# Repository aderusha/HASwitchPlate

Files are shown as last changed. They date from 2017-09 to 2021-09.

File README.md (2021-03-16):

# We're Moving!

This repository is an archived snapshot of the pre-1.0 HASP project.

## [Click here to head to the new home for HASPone!](https://github.com/HASwitchPlate/HASPone)

Below you'll find saved information about previous versions of HASP.

---

# HA SwitchPlate

The HA SwitchPlate is a user-programmable LCD touchscreen you can mount into a [standard North American work box](https://www.nema.org/Standards/ComplimentaryDocuments/NEMA%20WD%206%20-%20Dimensions%20for%20Wiring%20Devices%20-%20Excerpt.pdf) in place of a light switch.  It connects to your home automation system over WiFi to send and receive [MQTT](https://en.wikipedia.org/wiki/MQTT) messages in response to user interactions on the screen or events happening in your home.  The result is an attractive and highly-customizable controller for your home automation system which you can build yourself!

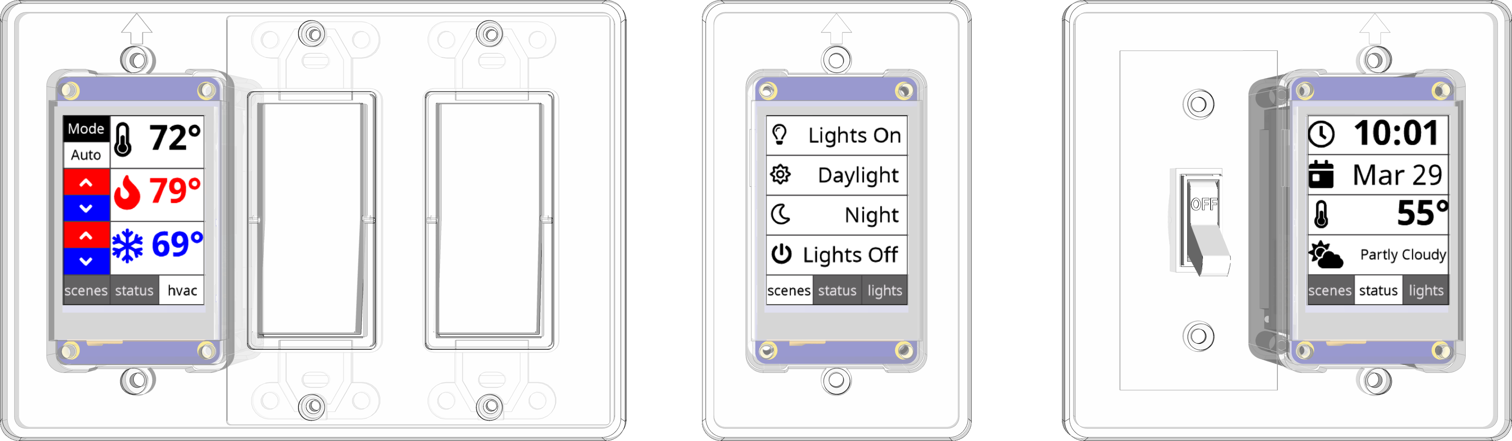
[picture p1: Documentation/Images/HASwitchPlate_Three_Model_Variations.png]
HA SwitchPlate Models


The HA SwitchPlate ("HASP") utilizes a [Nextion 2.4" LCD Touchscreen display](https://amzn.to/2TRTEU2) mounted in a 3D-printed enclosure as a touchscreen panel for home control and information display.  An [ESP8266-based microcontroller](https://amzn.to/2UZlga4) provides WiFi connectivity and system control.  The project has been developed to integrate with [Home Assistant](https://home-assistant.io/) and [OpenHAB](https://www.openhab.org/) but [should be compatible](Documentation/06_MQTT_Control.md) with any other MQTT-enabled automation platform such as [Domoticz](https://www.domoticz.com/wiki/MQTT), [Node-Red](http://noderedguide.com/tag/mqtt/), [Wink](https://github.com/danielolson13/wink-mqtt), [SmartThings](https://github.com/stjohnjohnson/smartthings-mqtt-bridge), [Vera](https://github.com/jonferreira/vera-mqtt), [HomeKit](https://www.npmjs.com/package/homekit2mqtt), etc.

The [Arduino code](Arduino_Sketch) for the ESP8266 provides a generic gateway between [MQTT](https://en.wikipedia.org/wiki/MQTT) and the [Nextion instruction set](https://www.itead.cc/wiki/Nextion_Instruction_Set).  A basic [Nextion HMI display file](Nextion_HMI) has been included with several pages of various layouts to provide user controls or to present information in response to MQTT messages sent to the device.

## Demo screens

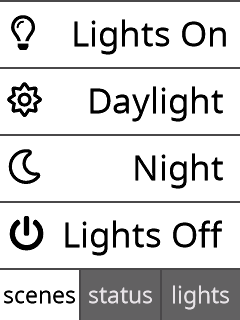
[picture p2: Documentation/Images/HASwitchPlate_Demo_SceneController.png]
Scene controller
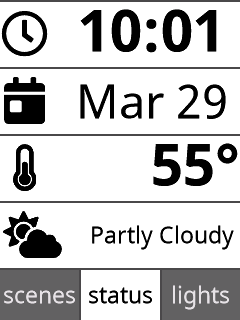
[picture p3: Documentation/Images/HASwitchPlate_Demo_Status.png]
Status display
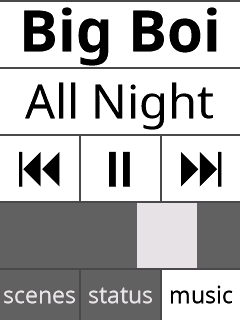
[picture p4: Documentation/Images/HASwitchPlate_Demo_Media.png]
Media control
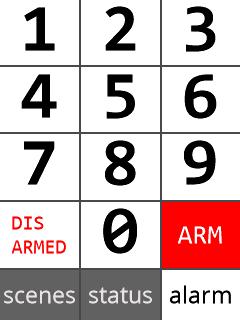
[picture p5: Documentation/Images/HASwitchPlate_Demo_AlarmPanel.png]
Alarm Panel
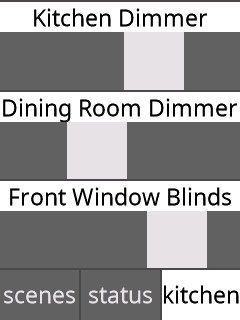
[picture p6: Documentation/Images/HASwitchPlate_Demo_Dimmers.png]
Slider/Dimmer Controls
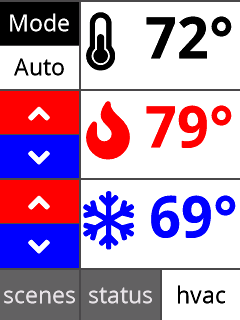
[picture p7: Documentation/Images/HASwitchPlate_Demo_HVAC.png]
HVAC Controls
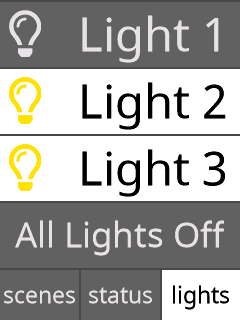
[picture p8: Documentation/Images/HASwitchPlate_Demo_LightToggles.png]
Light toggles
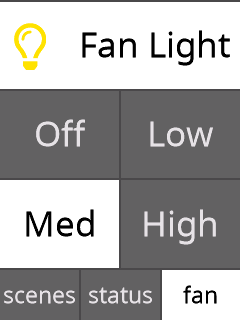
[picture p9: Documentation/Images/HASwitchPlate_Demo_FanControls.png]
Fan controller
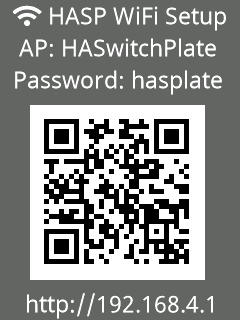
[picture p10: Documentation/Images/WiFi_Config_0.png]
WiFi Setup
        

## Purchase an assembled unit

As this build requires some specialist skills and tools, I will occasionally be [offering assembled devices for sale here](https://www.tindie.com/products/luma/ha-switchplate-hasp-single-wide-assembled/).

## Buy me a coffee

Buy me a coffee (https://www.buymeacoffee.com/gW5rPpsKR)

This project is powered by coffee.  [I might get a little weird about it at times](https://github.com/aderusha/RoastLearner), but it's not much of a stretch to suggest that coffee both powers and consumes a fair portion of my mental energy.  [Hook me up if you think HASP is cool](https://www.buymeacoffee.com/gW5rPpsKR).  Thanks!

## Bill of Materials

To build a simple version of this project you will minimally need the [Nextion display](https://amzn.to/2DIpahB) and the [WeMos D1 Mini](https://amzn.to/2Gc92Xs), 4 jumper wires, and a USB cable to power both devices.

A complete build that's ready to install will require the following components:

* [Nextion 2.4" LCD Touchscreen display](https://amzn.to/2RksiXr)
* [WeMos D1 Mini ESP8266 WiFi microcontroller](https://amzn.to/2UZlga4)
* [3D printed switch plate](3D_Printable_Models/HASwitchPlate_front_single.stl)
* [3D printed rear cover](3D_Printable_Models/HASwitchPlate_rear_nolcdmod.stl)
* [Mean Well IRM-03-5 AC to 5VDC Power supply](https://amzn.to/2UUWGa8)
* [PCB](PCB/)
* [2N3904 NPN Transistor](https://amzn.to/2TRuwwD)
* [1k Ohm Resistor](https://amzn.to/2Ec3kTZ)
* [4pin 2.54mm JST-XH PCB header](https://amzn.to/2Eaywmt)
* [Rubber grommet](https://amzn.to/2N6Etny)
* [6" each of white and black 300V 18AWG stranded power cables](https://amzn.to/2EcMmoA)
* [Two M2 self-tapping 6MM screws](https://amzn.to/2V0djBg) (or just any 4-6mm M2 screws) to mount PCB in rear enclosure
* [Four 20mm M2 flathead screws](https://amzn.to/2TQvd9N) and [four 3mm M2 threaded inserts](https://amzn.to/2N511Fh) to fasten both halves of the enclosure together

## Get Started!

[Check out the documentation](Documentation/) to get started building your own HA SwitchPlate.

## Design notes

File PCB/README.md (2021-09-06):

# We're Moving!

This repository is an archived snapshot of the pre-1.0 HASP project.

## [Click here to head to the new home for HASPone!](https://github.com/HASwitchPlate/HASPone)

Below you'll find saved information about previous versions of HASP.

---

# PCB source files and Gerber outputs

Above you'll find [KiCad](http://kicad-pcb.org/) [schematic](https://github.com/aderusha/HASwitchPlate/blob/master/PCB/HASwitchPlate.sch) and [PCB](https://github.com/aderusha/HASwitchPlate/blob/master/PCB/HASwitchPlate.kicad_pcb) files along with [a ZIP bundle containing complete gerber outputs](https://github.com/aderusha/HASwitchPlate/raw/master/PCB/HASwitchPlate.gerbers.zip) ready to send to [your favorite PCB shop](https://www.allpcb.com/?Mb_InviteId=34099).

I had these manufactured by [AllPCB](https://www.allpcb.com/?Mb_InviteId=34099) and I'm very happy with the results.  The quality has been perfect and their shipping time to the US has been under a week across several orders.  [If you sign up through this link](https://www.allpcb.com/?Mb_InviteId=34099)  they credit me some cash that I can use for future projects which helps me out a bit.

If you aren't looking to buy a zillion boards, I may have some ready for US orders in [my Tindie store](https://www.tindie.com/products/luma/ha-switchplate-hasp-pcb/).

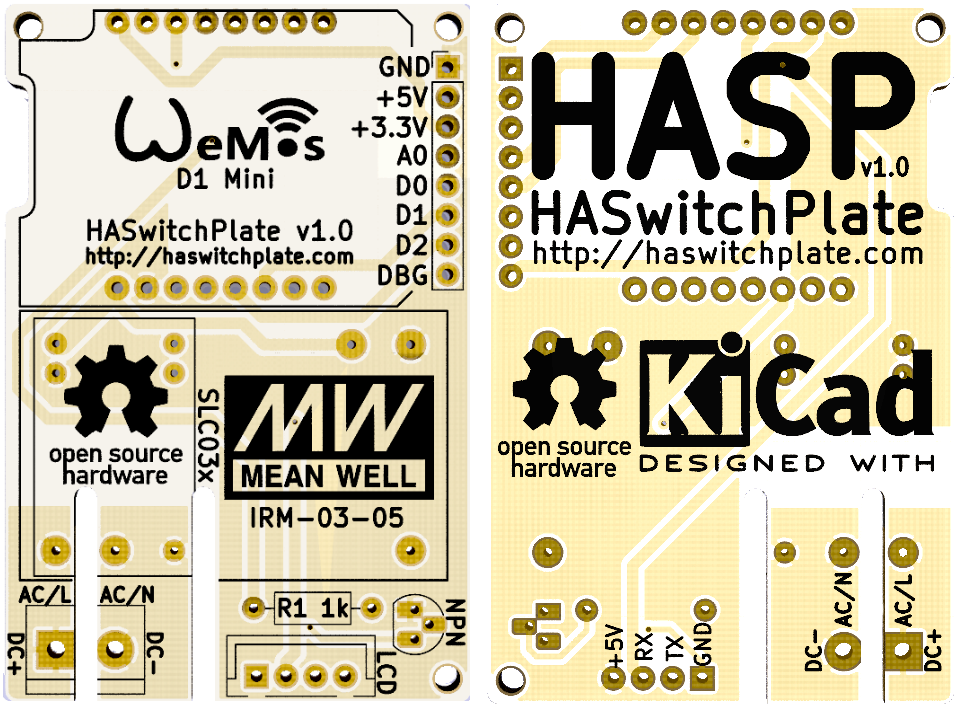
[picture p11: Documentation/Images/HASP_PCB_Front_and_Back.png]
HA SwitchPlate PCB


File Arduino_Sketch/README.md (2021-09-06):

# We're Moving!

This repository is an archived snapshot of the pre-1.0 HASP project.

## [Click here to head to the new home for HASPone!](https://github.com/HASwitchPlate/HASPone)

Below you'll find saved information about previous versions of HASP.

---

# HASwitchPlate Arduino Sketch

Here you'll find the [Arduino source code](./HASwitchPlate/HASwitchPlate.ino) for the microcontroller firmware along with [a pre-compiled binary image](https://github.com/aderusha/HASwitchPlate/raw/master/Arduino_Sketch/HASwitchPlate.ino.d1_mini.bin) which can be [flashed directly to your ESP8266](../Documentation/01_Arduino_Sketch.md#nodemcu-flasher).  

Please [check the Arduino Sketch documentation](../Documentation/01_Arduino_Sketch.md) for additional deployment details.

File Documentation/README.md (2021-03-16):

# We're Moving!

This repository is an archived snapshot of the pre-1.0 HASP project.

## [Click here to head to the new home for HASPone!](https://github.com/HASwitchPlate/HASPone)

Below you'll find saved information about previous versions of HASP.

---

# HA SwitchPlate Documentation

## First, a note of caution

The HA SwitchPlate project requires some basic knowledge of soldering, electronics, Arduino programming, MQTT, and how to safely handle high-voltage AC.  This point bears some repeating so let's try a bigger font to make sure everyone gets it:

# THIS PROJECT INVOLVES MONKEYING WITH HIGH VOLTAGE AND YOU COULD KILL YOURSELF AND/OR SET YOUR HOUSE ON FIRE

The end result is a thing that connects to live voltage and will be placed into your wall for years to come. It will not carry any sort of UL/CE/etc certification.  Proceed with extreme caution.

## With that out of the way, let's get started!

If you want to jump right in, follow the steps below in order to build and setup your device.  Keep reading after that for some background on how this all actually works.

## Step-by-step Instructions

### Step 1 - [Arduino Sketch](01_Arduino_Sketch.md)

Get started with deploying your code to the ESP8266 and getting it connected to WiFi and your MQTT broker.

### Step 2 - [Nextion HMI](02_Nextion_HMI.md)

Next you'll want to flash the Nextion touchscreen with the provided firmware.

### Step 3 - [Electronics Assembly](03_Electronics_Assembly.md)

Now we can hook the ESP8266 to the Nextion HMI and provide power to both.

### Step 4 - [Project Enclosure](04_Project_Enclosure.md)

Time to move from the breadboard into a nice new home suitable for mounting in your wall.

### Step 5 - [Home Assistant](05_Home_Assistant.md)

Utilize the provided Home Assistant automations to control and interact with the panel.

### Step 6 - [MQTT Control](06_MQTT_Control.md)

Time to remove the training wheels and learn to send commands to and from the panel via MQTT.

----

## Frequently Asked Questions

* **Can I install HASP outside of North America?** While the various power supply options for the HASP electronics should offer a solution which can handle line voltage in most countries, the physical installation of the device probably won't work outside of North America.  There is no international standard for the size and shape of workboxes, so things like screw hole locations and overall mounting dimensions used for the HASP are unlikely to work in any workbox outside of North America.
* **Can I use HASP with \<Some Home Automation System\>**?  If your home automation system can send Nextion commands as MQTT payloads, then yes.  Getting it all to work is going to take a lot of work, but it's possible.
* **Can I run HASP without a neutral wire?** Like most smart devices, a HASP installation will require a neutral wire available in the box you're mounting into.

----

## HASwitchPlate Architecture

The complete HA SwitchPlate ("HASP") build consists of 4 physical components:

* Nextion LCD Touchscreen
* ESP8266 WiFi microcontroller
* Power supply and circuit board
* 3D-printed enclosure

In addition, there are three different programming environments involved:

* Nextion Instruction set
* Arduino for ESP8266
* Home Assistant automations (or automation platform of your choice)

## The basics

A home automation system such as Home Assistant can interact with the HASP by sending and receiving MQTT messages to control what appears on the HASP and to respond to user interactions at the HASP.  At its core this project is an Nextion-over-MQTT gateway.  [Nextion Instruction Set](https://nextion.tech/instruction-set/) commands are sent to the HASP via an MQTT message and delivered to the Nextion LCD.  User interactions triggered from the LCD (such as button presses) are sent back out from HASP via MQTT messages to be acted upon by your home automation system.

### Example: one screen button

To illustrate, let's discuss the case of a single button shown on the screen.  Below we see  "page 1", showing a set of 4 buttons arranged vertically and a set of 3 page select buttons at the bottom.

Scene Controls

Referring to the [Nextion Object Reference](02_Nextion_HMI.md#hasp-nextion-object-reference) (more on this later), we find that the top-most button above is an object named `p[1].b[4]`.  When the HASP device shown here powered on, the home automation controller sent an MQTT message that looked like this:

| topic | message |
|---|---|
| `hasp/plate01/command/p[1].b[4].txt` | `"  Lights On "` |

Let's take a look at this `command` message:

`hasp` All messages to and from the HASP appear under the `hasp/` namespace in MQTT

`plate01` This device is named `plate01`.  You can have several HASP devices in your home and each gets their own name.

`command` This message is a `command` being sent *to* the HASP device.

`p[1].b[4]` is the name of a Nextion "object".  A full discussion of these names and a map to the objects included in the HASP project can be found [here](02_Nextion_HMI.md#hasp-nextion-object-reference).

`.txt` is a property of the object named above.  In this case, `.txt` is a reference to the text which appears on this object.

`"     Lights On "` Is the text we wish to appear on the screen.  The `` part of this text is a [FontAwesome icon codepoint](https://fontawesome.com/cheatsheet), which here happens to be a lightbulb.  We've mixed the icon and the text to be displayed in this message.

Put together, we've told the HASP named `plate01` to send a Nextion instruction `p[1].b[4].txt="     Lights On "`.  The HASP sent this command to the Nextion LCD, and the result is the text you see on the screenshot above.

### User Interaction

Now that we have some nice text appearing on the screen, let's see what happens when the user interacts with our button.  When the `Lights On` button is pressed, the Nextion LCD sends a command to the HASP device, which publishes the following MQTT message:

| topic | message |
|---|---|
| `hasp/plate01/state/p[1].b[4]` | `ON` |

Let's take a look at this `state` message:

`hasp` Just as before, all messages to and from the HASP appear under the `hasp/` namespace

`plate01` This message came from a device named `plate01`.

`state` This message is a `state` update sent *from* the HASP device.

`p[1].b[4]` is the Nextion object which triggered the new `state`

`ON` This messages tells us that the object above has entered the `ON` state.  In the case of a button object, this means somebody has pressed the button.  An `OFF` message will be sent later when the user releases the button.

### Responding to User Interaction

Now it is up to your home automation system to pick up this message and doing something meaningful in response, like turning on the lights.  In this project, a set of [Home Assistant automations](https://www.home-assistant.io/docs/automation/) has been provided to demonstrate various interactions which you can use as a starting point for customizing your own environment.

[This is an example Home Assistant automation which will listen for HASP button presses](../Home_Assistant/packages/plate01/hasp_plate01_p1_scenes.yaml#L45-L53):

```yaml
# Trigger scene.lights_on when p[1].b[4] pressed
- alias: hasp_plate01_p1_SceneButton4
  trigger:
    - platform: mqtt
      topic: "hasp/plate01/state/p[1].b[4]"
      payload: "ON"
  action:
    - service: scene.turn_on
      entity_id: scene.lights_on
```

This automation tells Home Assistant to listen to the MQTT topic `hasp/plate01/state/p[1].b[4]` for a message with the payload `ON`.  As we learned above, this is the message that will be sent out when a user presses the button which we've applied the text label "Lights on" (with a nice icon).  When Home Assistant receives this button press, we trigger a [Home Assistant scene](https://www.home-assistant.io/docs/scene/) called `lights_on`.

And that's it!  All of the HASP interactions follow some version of this basic workflow.  The device is configured to display things by receiving MQTT messages.  When the user does things at the HASP device, MQTT messages are sent back for your home automation platform to respond to.

Of course, things can get complicated.  The included automations make extensive use of [templates](https://www.home-assistant.io/docs/automation/templating/) and other advanced features of Home Assistant.  Don't be worried though, underneath it all it's always going to be some version of the simple interaction shown above.

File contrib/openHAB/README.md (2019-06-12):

# openHAB HASP Configuration

The configuration files in this folder have been created to adapt the HASP project for use with the openHAB home automation system. They interface with aderusha's Arduino code via MQTT, without the need for any additional bindings.

## Installation

1. Ensure you have a working MQTT broker and HASP plate
2. Copy the included .items and .rules files into their appropriate folders within your configuration.
3. Copy the sitemap configuration out of the HASP.sitemap file into your own configuration

## Configuration

1. Edit the HASP.rules file (within the "USER CONFIG" sections only!) to adapt the HASP plate to your configuration. You will want to modify the HASP page settings and buttons, to select the pages and buttons you want to show on your HASP plate. Then, edit the HASP->openHAB and openHAB->HASP rules to make the HASP buttons and dimmers interact with your openHAB items and rules.

***

## Notes

I have included several sample config settings and rules to show you how to interact with your own openHAB items (e.g. setting the first dimmer on page 5 will change the HASP brightness item, and the changing brightness item will modify the state of the second dimmer on page 5 - this will show you how to make HASP work with your own openHAB configuration). I also included a rule to operate the chart on page 9, which is a specific display item on the Nextion HMI and this should show you how to interact with the chart.

If you want to use multiple plates, you'll need to create a second set of items/rules/sitemap files, and rename all of them from "plate01" to your proper HASP name.

If you have any specific questions related to the openHAB implementation of the HASP, please post your questions on the [openHAB forums](http://community.openhab.org), watch [BK Hobby's](https://www.youtube.com/c/BKHobby) Youtube channel for videos related to this or openHAB in general, or join [BK Hobby's Discord](https://discord.gg/jUr7J4u) servier for a direct question to one of the openHAB experts there.

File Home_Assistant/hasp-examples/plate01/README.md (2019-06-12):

# Home Assistant example configurations

These configurations serve as additional examples for interacting with the HASP from Home Assistant.  Each `.yaml` file is a Home Assistant package with all of the required components to accomplish the specified task.  Using these examples is as easy as renaming `plate01` to your device name (search and replace will work) and copying the result to your `packages` folder.

## Example Configurations

* [`hasp_plate01_00_autofirmwareupdate.yaml`](hasp_plate01_00_autofirmwareupdate.yaml) Update HASP Arduino code when a new firmware package is published
* [`hasp_plate01_00_backlightbysun.yaml`](hasp_plate01_00_backlightbysun.yaml) Adjust HASP backlight level to gradually dim as the sun goes down, the brighten when it comes back up
* [`hasp_plate01_00_defaultpage.yaml`](hasp_plate01_00_defaultpage.yaml) Define a default page and timeout, switch back to default page after the timeout expires
* [`hasp_plate01_00_kodisensor.yaml`](hasp_plate01_00_kodisensor.yaml) Template sensors to report Kodi media player activity by @squirtbrnr
* [`hasp_plate01_00_motionsensor.yaml`](hasp_plate01_00_motionsensor.yaml) Example automation for use with a motion sensor installed on the HASP
* [`hasp_plate01_p0_messagedisplay.yaml`](hasp_plate01_p0_messagedisplay.yaml) Display messages or QR codes on the HASP
* [`hasp_plate01_p9_3dprint.yaml`](hasp_plate01_p9_3dprint.yaml) Monitor a 3D printer via OctoPrint

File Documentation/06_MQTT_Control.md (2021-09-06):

# We're Moving!

This repository is an archived snapshot of the pre-1.0 HASP project.

## [Click here to head to the new home for HASPone!](https://github.com/HASwitchPlate/HASPone)

Below you'll find saved information about previous versions of HASP.

---

# MQTT Control

## MQTT

[MQTT](https://mqtt.org/faq) is a standard IoT protocol in widespread use everywhere from small home automation projects to global industrial IoT environments.  Think of it as a "twitter for devices" - it works in very much the same way.  MQTT is a "publish/subscribe" message bus, where attached devices can publish `messages` on `topics`, and other devices can subscribe to those `topics` to receive the published message.  MQTT requires a central MQTT server we call a "broker".  Built-in MQTT broker services are available in [Home Assistant](https://www.home-assistant.io/docs/mqtt/broker/) and [OpenHAB](https://www.openhab.org/addons/bindings/mqtt/) or you can run your own standalone instance.  The [Mosquitto](https://mosquitto.org/) MQTT broker is a common open source solution and is probably a good place to start for home use.

At its core, the HASP project acts as a gateway between MQTT and the Nextion LCD.  It will "subscribe" to MQTT messages sent by your home automation software and forward the contents of those messages to the Nextion LCD.  Interactions from the LCD, such as a user pressing a button, are sent back to your home automation system as published MQTT messages.

In order to make use of the HASP project to its full potential, you'll need to understand how the Nextion LCD sends and receives commands, and how to make your home automation system interact with those commands over MQTT.

## Nextion Instructions

A detailed guide to the Nextion instruction set can be found [here](https://nextion.itead.cc/resources/documents/instruction-set/).  A mostly-complete list of all available instructions and their use is available [here](https://www.itead.cc/wiki/Nextion_Instruction_Set).  These Nextion instructions are sent as MQTT messages per the [`MQTT Namespace`](#mqtt-namespace) outlined below.

A common issue people encounter centers around the use of quotes in the Nextion instruction set.  As a general rule, attributes which accept only numbers do not have quotes, and all other values must be enclosed in double quotes.

## Nextion Page and Object IDs

Objects are referenced by page number (*not page name*) and object ID (*not object name*) as shown in the Nextion editor.  The Nextion notation for each object is of the form `p[1].b[2]` meaning page number 1, object ID 2.  Confusingly, button object *names* will start at `b0` but it might be object ID 2, or 7, etc. Other objects will be named similarly with different letters.  For example, the first text field on the page will be automatically named `t0`.  **Ignore these names**.  They have nothing to do with the object ID, and all objects regardless of type are still referenced as `p[<page number>].b[<object id>]`

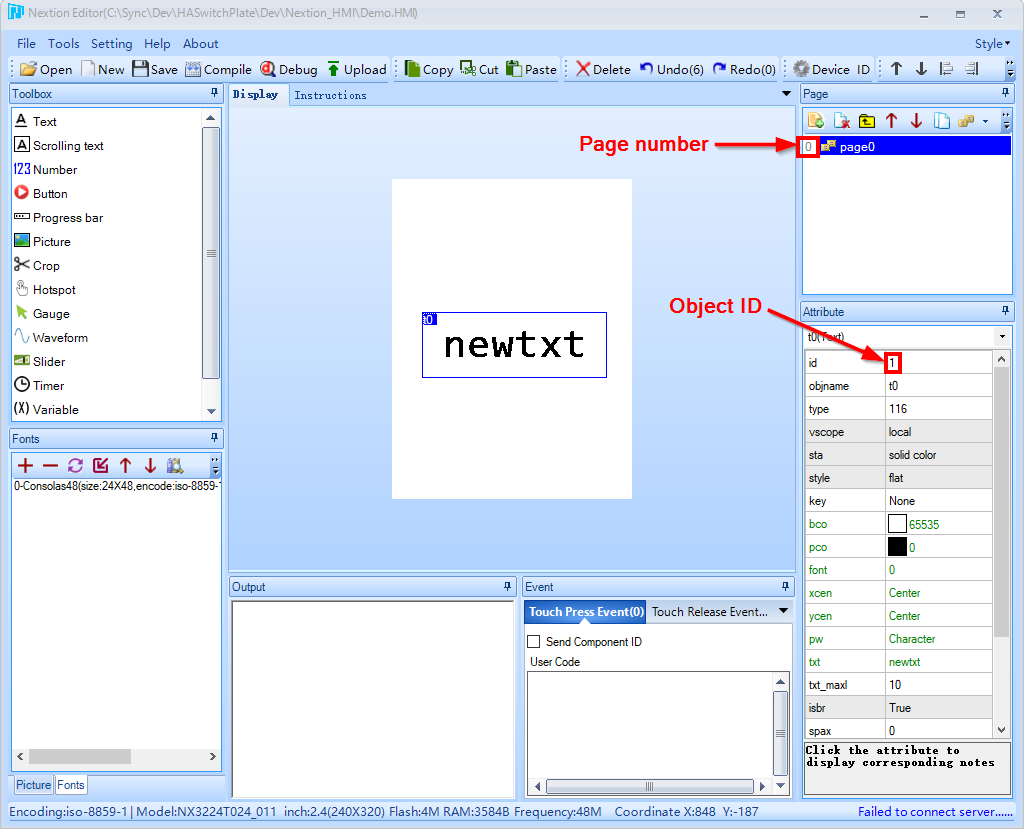
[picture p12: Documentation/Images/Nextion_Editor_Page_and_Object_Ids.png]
Page and Object IDs


Screenshots of each object number on each page of the HASP project can be found in the [Nextion HMI documentation section](02_Nextion_HMI.md#hasp-nextion-object-reference).

An object will have multiple attributes, some of which can be changed.  For example, a button named `p[1].b[2]` may have a "txt" attribute which we'd refer to as `p[1].b[2].txt`.  Not all attributes can be changed at runtime, the ones which can are shown in a green font in the Nextion editor (see the right pane of the image above.)

## MQTT Message Examples

With the information above we can now take a look at a some example MQTT  transactions.  To begin, let's customize the text appearing on a button.  The [topmost button on page one](02_Nextion_HMI.md#pages-1-3) is `p[1].b[4]`.  If we want to set the text on that button to read `HASP` we could send the following MQTT message:

> topic: `hasp/plate01/command/p[1].b[4].txt`  
> message: `"HASP"`

The HASP device named `plate01` will be subscribed to the topic `hasp/plate01/command`.  When it sees this message, it will send the Nextion LCD the command `p[1].b[4].txt="HASP"` which will update the text on our button.

Now let's try one going the other way.  When a user presses that button, HASP is going to publish an MQTT message that looks like this:

> topic: `hasp/plate01/state/p[1].b[4]`  
> message: `ON`  

Your home automation system will be subscribed to `hasp/plate01/state`.  When the message example above is published, your home automation system will know that somebody pressed button `p[1].b[4]` on a HASP device named `plate01` and can take appropriate action in response.

## Home Assistant Automation Example

The HASP project includes [a number of Home Assistant automations](../Home_Assistant) to get you up and running.  To make full use of your HASP you will want to customize these automations to suit your own needs.  The example automations provided are broken down into pages, and the ideas presented build on each other as you work through each page in numerical order.  If you're looking to understand how this works, [start with page 1](../Home_Assistant/packages/plate01/hasp_plate01_p1_scenes.yaml) and work your way up through the rest.

Let's take a look at an automation example to handle the `p[1].b[4]` button we were just working with.  The automations discussed here will be specific to Home Assistant but the concepts should apply to any home automation platform.

### Send commands from Home Assistant to the HASP

[The first page 1 automation](../Home_Assistant/packages/plate01/hasp_plate01_p1_scenes.yaml#L6-L21), like most Home Assistant automations, begins with a [trigger](https://www.home-assistant.io/docs/automation/trigger/).  Ours looks like this:

```yaml
  - alias: hasp_plate01_p1_ScenesInit
    trigger:
    - platform: state
      entity_id: 'binary_sensor.plate01_connected'
      to: 'on'
    - platform: homeassistant
      event: start
```

This trigger will fire whenever the HASP device `plate01` connects to Home Assistant, or whenever Home Assistant starts.  When the HASP starts up it has no text on any buttons, so the first thing we'll do is start sending commands to tell the HASP what we want our buttons to say.  Let's look at the [action](https://www.home-assistant.io/docs/automation/action/) section:

```yaml
    action:
    - service: mqtt.publish
      data:
        topic: 'hasp/plate01/command/p[1].b[4].font'
        payload: '2'
    - service: mqtt.publish
      data:
        topic: 'hasp/plate01/command/p[1].b[4].txt'
        payload: '"Lights On"'
```

The first action tells Home Assistant to publish the message `2` on the topic `hasp/plate01/command/p[1].b[4].font`.  This command sets the font for our button to [font number 2](02_Nextion_HMI.md#hasp-default-fonts) which "Consolas 48 point".  That font allows us to fit 10 characters into a standard-sized button.

Our next action tells Home Assistant to publish the message `"Lights On"` on the topic `hasp/plate01/command/p[1].b[4].txt`.  Note the use of quotes here, as we're sending text instead of a numeric value.  This command will program button `p[1].b[4]` to show the text `Lights On`.

If you would like this button to say something else, you can make that change now and restart Home Assistant to see what happens.

### Send commands from HASP to Home Assistant

[The second page 1 automation](../Home_Assistant/packages/plate01/hasp_plate01_p1_scenes.yaml#L47-L55) in our example looks like this:

```yaml
# Trigger scene.lights_on when p[1].b[4] pressed
  - alias: hasp_plate01_p1_SceneButton4
    trigger:
    - platform: mqtt
      topic: 'hasp/plate01/state/p[1].b[4]'
      payload: 'ON'
    action:
    - service: scene.turn_on
      entity_id: scene.lights_on
```

This automation is `trigger`ed when Home Assistant receives the message `ON` in the topic `hasp/plate01/state/p[1].b[4]`.  The `action:` calls a [Home Assistant scene](https://www.home-assistant.io/components/scene/) called `lights_on` which was [defined elsewhere](../Home_Assistant/packages/hasp_demo.yaml#L43-L57).

You can [change the action](https://www.home-assistant.io/docs/automation/action/) to be anything that Home Assistant can do - [turn on a light](https://www.home-assistant.io/components/light/#service-lightturn_on), [play a song](https://www.home-assistant.io/components/media_player/#service-media_playerplay_media), [notify a user over SMS](https://www.home-assistant.io/components/notify.twilio_sms/#usage), or whatever else you can think of.

## MQTT Namespace

By default the device will subscribe to `hasp/<node_name>/command/#` to accept incoming commands.  The device will also subscribe to `hasp/<group_name>/command/#` to accept incoming commands aimed at a group of devices.

There are two subtopics to send commands to and receive messages from the panel:

* `command` will send commands or set attribute of the display, such as button text or screen dim. The specific attribute must be appended as a subtopic, with the value to be set delivered as the payload.  For example, the following command will set the text displayed on page 1/button 4 to "Lamp On": `mosquitto_pub -h mqtt -t hasp/plate01/command/p[1].b[4].txt -m '"Lamp On"'`
* `state` topics will be sent by the panel in response to local user interactions or received commands which provide output in return.  For example, a user pressing button 4 on page 1 will cause the panel to publish a message: `'hasp/plate01/state/p[1].b[4]' 'ON'`

## `command` Syntax

Messages sent to the panel under the `command` topic will be handled based on the following rules:

* **`-t 'hasp/plate01/command' -m 'dim=50'`** A `command` with no subtopic will send the command in the payload to the panel directly.
* **`-t 'hasp/plate01/command/page' -m '1'`** The `page` command subtopic will set the current page on the device to the page number included in the payload.
* **`-t 'hasp/plate01/command/json' -m '["dim=50", "page 1"]'`** The `json` command subtopic will send a JSON array of commands one-by-one to the panel.
* **`-t 'hasp/plate01/command/p[1].b[4].txt' -m '"Lamp On"'`** A `command` with a subtopic will set the attribute named in the subtopic to the value sent in the payload.
* **`-t 'hasp/plate01/command/p[1].b[4].txt' -m ''`** A `command` with a subtopic and an empty payload will request the current value of the attribute named in the subtopic from the panel.  The value will be returned under the `state` topic as `'hasp/plate01/state/p[1].b[4].txt' -m '"Lamp On"'`
* **`-t 'hasp/plate01/command/statusupdate'`** `statusupdate` will publish a JSON string indicating system status.
* **`-t 'hasp/plate01/command/reboot'`** The `reboot` command will reboot the HASP device.
* **`-t 'hasp/plate01/command/factoryreset'`** The `factoryreset` command will wipe out saved WiFi, nodename, and MQTT broker details to reset the device back to default settings.
* **`-t 'hasp/plate01/command/lcdupdate'`** The `lcdupdate` command subtopic with no message will attempt to update the Nextion from the HASP GitHub repository.
* **`-t 'hasp/plate01/command/lcdupdate' -m 'http://192.168.0.10:8123/local/HASwitchPlate.tft'`** The `lcdupdate` command subtopic attempts to update the Nextion from the HTTP URL named in the payload.
* **`-t 'hasp/plate01/command/espupdate'`** The `espupdate` command subtopic with no message will attempt to update the ESP8266 from the HASP GitHub repository.
* **`-t 'hasp/plate01/command/espupdate' -m 'http://192.168.0.10/local/HASwitchPlate.ino.d1_mini.bin'`** The `espdupdate` command subtopic attempts to update the ESP8266 from the HTTP URL named in the payload.

In each of those commands, you can substitute the `<node_name>` for the `<group_name>` if you want to target all devices in a group.

### MQTT Error codes (rc=n)

If the HASP cannot connect to MQTT it will display a return code on the screen as RC=_n_.  These codes are specified by the MQTT spec [here](http://docs.oasis-open.org/mqtt/mqtt/v3.1.1/os/mqtt-v3.1.1-os.html#_Table_3.1_-).

| Value | Return Code Response | Description |
|---|---|---|
| 0 | 0x00 Connection Accepted | Connection accepted |
| 1 | 0x01 Connection Refused, unacceptable protocol version | The Server does not support the level of the MQTT protocol requested by the Client |
| 2 | 0x02 Connection Refused, identifier rejected | The Client identifier is correct UTF-8 but not allowed by the Server |
| 3 | 0x03 Connection Refused, Server unavailable | The Network Connection has been made but the MQTT service is unavailable |
| 4 | 0x04 Connection Refused, bad user name or password | The data in the user name or password is malformed |
| 5 | 0x05 Connection Refused, not authorized | The Client is not authorized to connect |
| 6-255 | | Reserved for future use |

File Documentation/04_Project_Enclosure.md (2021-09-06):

# We're Moving!

This repository is an archived snapshot of the pre-1.0 HASP project.

## [Click here to head to the new home for HASPone!](https://github.com/HASwitchPlate/HASPone)

Below you'll find saved information about previous versions of HASP.

---

# Project Enclosure

## 3D Printed Enclosure

The [enclosure provided](../3D_Printable_Models) includes STL files ready for slicing and the source models editable in the free edition of [SketchUp Make](https://www.sketchup.com/download).

## Assembling the completed project

### High voltage AC cabling

The AC power cables should be at least 18AWG 300V stranded cable with a white jacket soldered to the `AC/N` pad on the PCB and a similar wire with a black jacket soldered to `AC/L`.  These are fed through a [rubber push-in grommet](https://amzn.to/2N6Etny) mounted into the rear enclosure.  I've had good luck stripping an existing 3 conductor power cord and using the black/white wires inside.

### Threaded Inserts

The two halves of the enclosure are held together by [four 20mm M2 flat-head screws](https://amzn.to/2TQvd9N) through the rear of the enclosure into a set of [four 3mm M2 threaded inserts](https://amzn.to/2N511Fh) installed into the front plate.

To install the threaded inserts in the front plate, thread the end of an M2 screw into the insert with the end of the screw flush with the bottom face of the insert (meaning, it's not sticking out the other side).  Apply a thin bead of slow-set superglue around the outside edge of the insert, taking care not to get glue on the screw itself as you don't want to pull the glue up into the threads when removing the screw.  Then, take a hammer and *gently* tap it into place on the front plate.  You can crack the plastic if you swing too hard, you just need enough force to push the knurled ridges on the outside of the insert into the plate.

### PCB Installation

Installing the [HASP PCB](../PCB) requires a pair of small m2-ish screws, I'm using [M2 self-tapping 6MM screws](https://amzn.to/2V0djBg) but most any 4-6mm M2 screws should work fine too.  There shouldn't be much strain on these two so I haven't bothered with inserts here.

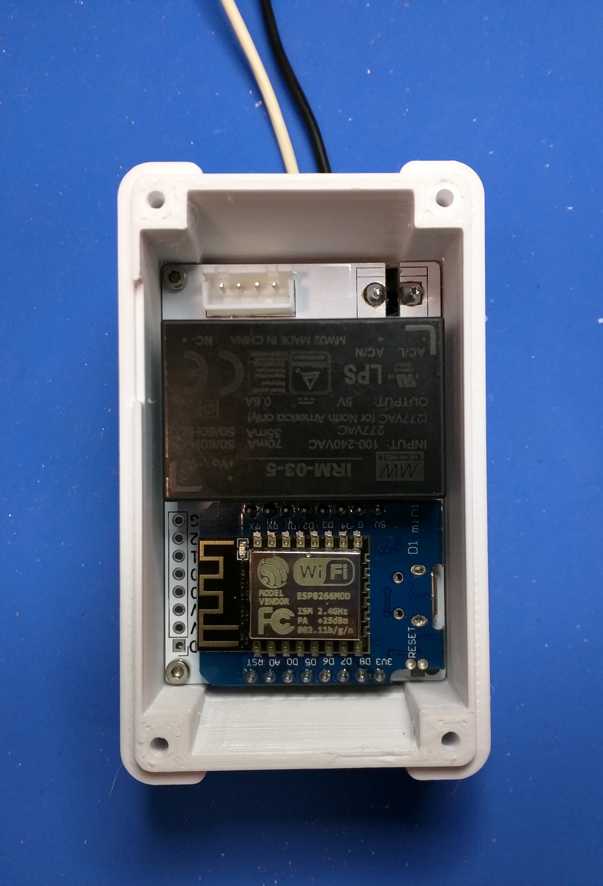
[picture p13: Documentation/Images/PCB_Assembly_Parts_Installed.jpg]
Parts installed


Once everything is fit together then it's a simple matter of running the four 20mm m2 screws through the back to hold the two halves of the enclosure together.  Again, be careful not to tighten these too hard as the screws can dimple the front of the switch plate.  Now you should be ready to mount into the wall!

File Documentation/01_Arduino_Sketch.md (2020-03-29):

# Flash firmware to ESP8266

The first order of business will be to flash the provided firmware to the ESP8266.  You can do this using the [NodeMCU Flasher](#nodemcu-flasher) (easy, Windows-only) or the [Arduino IDE](#arduino-ide) (less easy, but cross-platform).  You should only need to run through this process once as future firmware updates can be applied through the provided web interface.

## NodeMCU Flasher

If you're running Windows and you just want to get started without dealing with Arduino this is probably going to be your best option.

### Required Downloads

* NodeMCU Flasher: [Win32](https://github.com/nodemcu/nodemcu-flasher/raw/master/Win32/Release/ESP8266Flasher.exe) / [Win64](https://github.com/nodemcu/nodemcu-flasher/raw/master/Win64/Release/ESP8266Flasher.exe)
* [HASwitchPlate Firmware](https://github.com/aderusha/HASwitchPlate/raw/master/Arduino_Sketch/HASwitchPlate.ino.d1_mini.bin)

### NodeMCU Flasher Process

* Plug your WeMos D1 into an available USB port on your PC
* Launch the NodeMCU flasher and select the COM port for your device from the `COM Port` drop-down menu
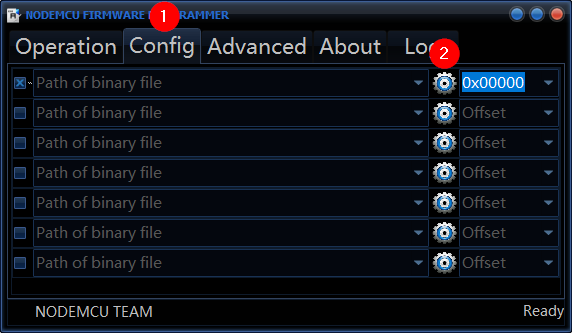
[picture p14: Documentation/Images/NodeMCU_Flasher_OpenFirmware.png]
NodeMCU_Flasher_OpenFirmware
* Select the `Config` tab<sup>(1)</sup>, then click the top-most gear icon to the right<sup>(2)</sup> to open a file browser. 
* Navigate to the HASP firmware image you downloaded and click `Open` to select it
* Switch back to the `Operation` tab and click `Flash(F)`

Now proceed to [First-time Setup](#first-time-setup) to connect to your wireless network.

---

## Arduino IDE

[Download the IDE for your platform](https://www.arduino.cc/en/Main/Software) and [follow these instructions to add support for the ESP8266 platform](https://github.com/esp8266/Arduino#installing-with-boards-manager).  HASP is currently compiled with Arduino core for ESP8266 version 2.5.0.  Once this is installed, select the board `LOLIN(WEMOS) D1 R2 & mini` from 'Tools' > 'Board'

### Required Libraries

Next you will need to add several libraries to your Arduino environment.  [Follow this guide for the general process](https://www.arduino.cc/en/Guide/Libraries) and add the following libraries to your IDE:

* [ArduinoJson](https://github.com/bblanchon/ArduinoJson) by Benoit Blanchon version 6.15
* [MQTT](https://github.com/256dpi/arduino-mqtt) by Joel Gaehwiler version 2.4.7
* [WiFiManager](https://github.com/tzapu/WiFiManager) by tzapu version 0.15.0

To enable future firmware updates you'll need to modify settings in the Arudino IDE for 1M SPIFFs, leaving 3M free for code and updates.  In the Arduino IDE select `Tools` > `Flash Size:` > `4M (1M SPIFFS)`.  If you're using [PlatformIO](https://platformio.org/) instead of Arduino, [modify the build flags](http://docs.platformio.org/en/latest/platforms/espressif8266.html#flash-size) to include `-Wl,-Teagle.flash.4m1m.ld`
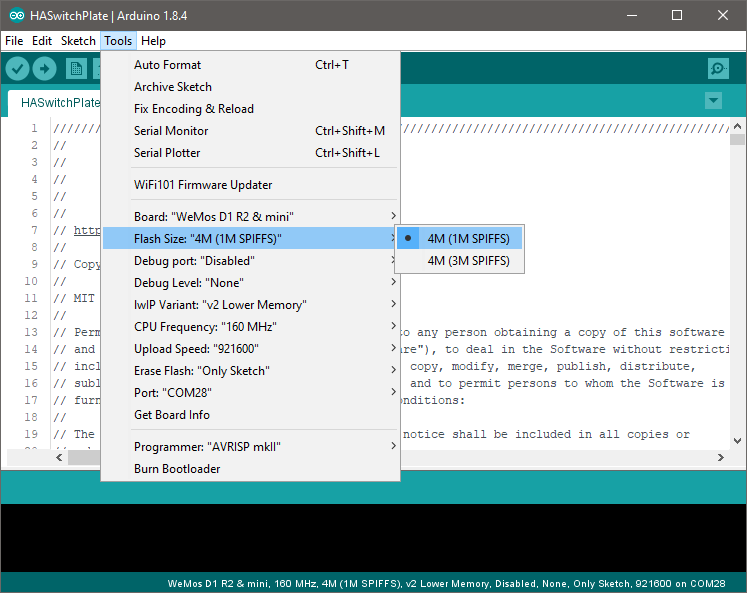
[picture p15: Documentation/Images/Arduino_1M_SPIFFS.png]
Arduino Erase All Flash Contents


## First-time Setup

Once your device has been flashed, restart it and connect to the WiFi SSID and password displayed on the LCD panel (or serial output if you don't have the LCD ready).  You should be prompted to open a [configuration website](http://192.168.4.1) to find your WiFi network and password.  You can set the MQTT broker information and admin credentials now, or use the web interface to do so later.  Once you `save settings` the device will connect to your network.  Congratulations, you are now online!

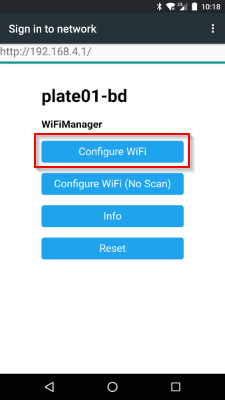
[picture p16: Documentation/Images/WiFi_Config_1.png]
WiFi Config 1
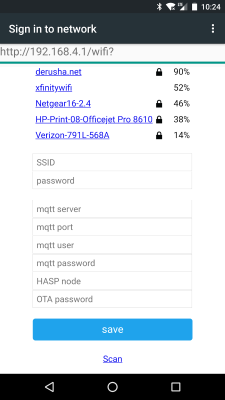
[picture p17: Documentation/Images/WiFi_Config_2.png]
WiFi Config 2
WiFi Config 0  

## Firmware updates

After the initial firmware deployment you should be able to upload new firmware through the web admin interface or [using Arduino OTA updates](https://randomnerdtutorials.com/esp8266-ota-updates-with-arduino-ide-over-the-air/) without connecting to your device via USB.

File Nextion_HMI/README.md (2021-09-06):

# We're Moving!

This repository is an archived snapshot of the pre-1.0 HASP project.

## [Click here to head to the new home for HASPone!](https://github.com/HASwitchPlate/HASPone)

Below you'll find saved information about previous versions of HASP.

---

# Nextion HMI

The Nextion panel ships with a default demo configuration which we need to overwrite with the included compiled code.  The file [HASwitchPlate.tft](HASwitchPlate.tft) can be saved to a FAT32-formatted microSD card and placed into the panel before power on.  The panel will recognize the code update and load it automatically, after which you're ready to connect to the microcontroller.  Note that some users have reported problems with cards formatted under Linux, so use a Windows system for this process and it should work without trouble.

If you want to manually edit your own panels, [download the editor from Nextion](https://nextion.itead.cc/resource/download/nextion-editor/) and you can flash the panel directly via serial.

Please [check the Nextion HMI documentation](../Documentation/02_Nextion_HMI.md) for additional details.

## Nextion Files Explained

* **[HASwitchPlate.hmi](HASwitchPlate.hmi)** This is the "source" file which you can modify in the [Nextion editor](https://nextion.itead.cc/resource/download/nextion-editor/).  If you want to make your own Nextion HMI, I'd recommend starting with this file, keeping Page 0 (`p0`), then start your own design on pages 1+.
* **[HASwitchPlate.tft](HASwitchPlate.tft)** This is the compiled Nextion firmware for the HASwitchPlate usable on a standard Nextion 2.4" LCD, model `NX3224T024_011R`
* **[HASwitchPlate-Enhanced.tft](HASwitchPlate-Enhanced.tft)** This is the compiled Nextion firmware for the HASwitchPlate usable on an enhanced Nextion 2.4" LCD, model `NX4024K032_011R`.  This panel will not fit in the provided 3D printed enclosure and no enhanced features are used in this project.  **Don't buy this panel**, but if you did (*and you shouldn't*), you can use this firmware.
* **[HASwitchPlate-TJC.hmi](HASwitchPlate-TJC.hmi)** This is the "source" file for the Chinese-market TJC LCD model `TJC3224T024_011`.  This file cannot be used with the english language editor.  If you purchase this panel, you will need to use the Chinese-language "USART HMI" editor to modify this file.  **Don't buy this panel**.
* **[HASwitchPlate-TJC.tft](HASwitchPlate-TJC.tft)** This is the compiled Nextion firmware for the HASwitchPlate usable on a Chinese market TJC 2.4" LCD, model `TJC3224T024_011`.

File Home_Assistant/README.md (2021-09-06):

# We're Moving!

This repository is an archived snapshot of the pre-1.0 HASP project.

## [Click here to head to the new home for HASPone!](https://github.com/HASwitchPlate/HASPone)

Below you'll find saved information about previous versions of HASP.

---

# Home Assistant configurations

These folders contain a ready-to-run Home Assistant configuration for testing and demonstration. 3 dimmable lights are defined to demonstrate device control, some weather sensors are defined to show status output, and the [Google Desktop Music Player](https://home-assistant.io/components/media_player.gpmdp/) component is included to demonstrate media player controls.

[Check the documentation](../Documentation/05_Home_Assistant.md) for deployment details.

This setup utilizes [Home Assistant packages](https://www.home-assistant.io/docs/configuration/packages/) for easy deployment.

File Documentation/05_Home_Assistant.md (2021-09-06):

# We're Moving!

This repository is an archived snapshot of the pre-1.0 HASP project.

## [Click here to head to the new home for HASPone!](https://github.com/HASwitchPlate/HASPone)

Below you'll find saved information about previous versions of HASP.

---

# Home Assistant integration

Configuring Home Assistant for the HASP requires making some basic changes to your configuration and downloading the packages to your installation.  [Continue below]((#standard-home-assistant-installation) for a standard Home Assistant installation in a container (HassOS, HassIO, Docker, etc).

The procedure will be a little different if you're running Home Assistant Core (venv, hassbian, or similar), so [skip to that section](#home-assistant-core-installation).

Finally, if you'd rather make all the changes yourself, jump to the [Manual Home Assistant installation section](#manual-home-assistant-installation).

## Standard Home Assistant installation

Before deploying your first HASP device, you'll need to install and configure the [`Mosquitto broker`](https://www.home-assistant.io/addons/mosquitto/) and [`Terminal & SSH`](https://www.home-assistant.io/addons/ssh/) add-ons from the default repository.  Be sure to follow the configuration instructions provided for both add-ons.

The mosquitto broker package requires a username and password.  Be sure to configure the "MQTT User" and "MQTT Password" on the HASP with a valid user from your Home Assistant configuration, and set the broker to the IP address of your Hass.io installation.  You will also need to setup the MQTT Integration (`Configuration` > `Integrations` > `MQTT` > `CONFIGURE`) and check the box `Enable discovery`.

Once those are installed, configured, and started, you can open the Terminal and execute the following command:

```bash
bash <(wget -qO- -o /dev/null https://raw.githubusercontent.com/aderusha/HASwitchPlate/master/Home_Assistant/deployhasp.sh)
```

You will be prompted for a device name and the script will do the rest.  Once it completes, the script will display a Lovelace configuration which you can paste into your existing Home Assistant UI through the Lovelace editor.

To apply your changes, restart Home Assistant (`Configuration` > `Server Controls` > `Server management` > `RESTART`) and then continue to the [First time setup](#first-time-setup) section below to initialize your environment.

[Check out this video](https://youtu.be/wbtVfuDKaM4) for the complete process of starting up a new Hass.io installation, configuring the required add-ons, and setting up your first HASP device.

---

## Home Assistant Core installation

Before deploying your first HASP device, you'll need to install and configure an [MQTT broker](https://www.home-assistant.io/docs/mqtt/broker) for Home Assistant.

You'll need to ssh to your Home Assistant installation as a user who has access to write to your home assistant installation.  For most installations, this will be the user `homeassistant`.

```bash
sudo su -s /bin/bash homeassistant
cd ~/.homeassistant
bash <(wget -qO- -o /dev/null https://raw.githubusercontent.com/aderusha/HASwitchPlate/master/Home_Assistant/deployhasp.sh)
```

You will be prompted for a device name and the script will do the rest.  Once it completes, restart your Home Assistant service to apply changes and then continue to the [First time setup](#first-time-setup) section below to initialize your environment.

---

## Manual Home Assistant installation

### `configuration.yaml` changes

To deploy your first HASP device into Home Assistant a couple simple changes will need to be made to your `configuration.yaml`.  [See the documentation here](https://www.home-assistant.io/getting-started/configuration/) for the general process of editing that file.  These changes only need to be made once, if you are adding additional HASP devices to an existing installation you can skip directly to the [`deployhasp.sh`](#deployhaspsh) section below.

### Packages

The configuration and automation files for the HASP are bundled as [Home Assistant Packages](https://www.home-assistant.io/docs/configuration/packages/).  Enable packages under the `homeassistant` section at the top of your `configuration.yaml` by adding the following line:

```yaml
homeassistant:
  packages: !include_dir_named packages
```

### MQTT

This project relies on communication with an [MQTT broker](https://www.home-assistant.io/docs/mqtt/broker).  You will need to enable Home Assistant MQTT support by following that guide.

### Recorder

The [Home Assistant Recorder](https://www.home-assistant.io/components/recorder/) component is required to allow Home Assistant to save configuration and state of some HASP controls across reboots.  You will can enable Home Assistant Recorder by adding the following line to your `configuration.yaml`:

```yaml
# Example configuration.yaml entry
recorder:
```

### `deployhasp.sh`

Now you'll need to copy over the [packages directory](https://github.com/aderusha/HASwitchPlate/tree/master/Home_Assistant/packages) and modify it for your new device.  The folder name, file names, and the contents of the `.yaml` files will all need to have `plate01` replaced with your new device name.

The `deployhasp.sh` script will automate this task and can be executed with the following commands:

```bash
sudo su -s /bin/bash homeassistant
cd ~/.homeassistant
bash <(wget -qO- -o /dev/null https://raw.githubusercontent.com/aderusha/HASwitchPlate/master/Home_Assistant/deployhasp.sh)
```

Finally, you'll need to restart Home Assistant to apply your changes then continue to the [First time setup](#first-time-setup) section below to initialize your environment.

---

## First time setup

## Lovelace configuration

Lovelace doesn't support automation of the UI so a few manual steps need to happen next

Upon startup the default HMI display file contains empty buttons with no text.  Launch the Home Assistant web UI and look for a new tab with your chosen device name.  Select that tab and look for the automation titled `hasp_<your_device_name>_00_FirstTimeSetup`.  Select that automation and click "TRIGGER" to apply the basic configuration to your new device.

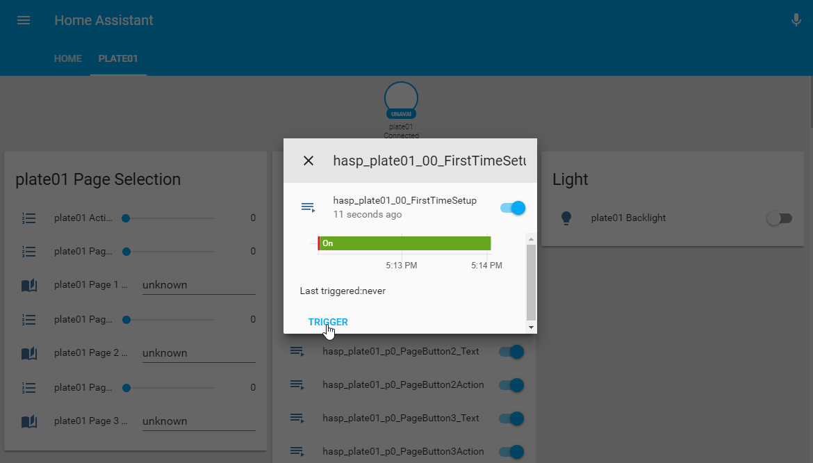
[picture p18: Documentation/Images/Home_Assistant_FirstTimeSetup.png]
Home_Assistant_FirstTimeSetup


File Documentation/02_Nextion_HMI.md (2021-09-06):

# We're Moving!

This repository is an archived snapshot of the pre-1.0 HASP project.

## [Click here to head to the new home for HASPone!](https://github.com/HASwitchPlate/HASPone)

Below you'll find saved information about previous versions of HASP.

---

# Nextion HMI

## Basic first-time use

For most users the deployment of the Nextion firmware is straightforward - simply copy [the compiled firmware image](../Nextion_HMI/HASwitchPlate.tft) to a [FAT32-formatted microSD card](https://nextion.tech/faq-items/using-nextion-microsd/), insert the microSD card into the Nextion LCD, and then apply 5VDC to the power pins on the panel.  It should power up the panel, recognize the .TFT file, and update the panel automatically.  Once the firmware update has completed you can remove power and eject the microSD card.

Compiled TFT files are included for the [Basic](https://github.com/aderusha/HASwitchPlate/raw/master/Nextion_HMI/HASwitchPlate.tft) and [Enhanced](https://github.com/aderusha/HASwitchPlate/raw/master/Nextion_HMI/HASwitchPlate-Enhanced.tft) versions of the panel.  This project does not currently utilize any features offered in the Enhanced panel, and the Enhanced device does not fit in the provided enclosure.  **It is strongly recommended that you do not use the enhanced display**.

Once the project is assembled, future updates to the Nextion firmware can be handled over-the-air by utilizing the built-in web interface or by [issuing an MQTT command](06_MQTT_Control.md#command-syntax) with a URL to the target TFT file.

With the Nextion firmware flashed you can proceed to the [Electronics Assembly section](03_Electronics_Assembly.md) to test the assembled system.

---

## Nextion Editor

For advanced customization you will need to download the (Windows-only) [Nextion editor](https://nextion.tech/nextion-editor/).  You can find instructions on its use [here](https://www.itead.cc/blog/nextion-editor-a-basic-introduction).

If you want to edit the existing HASP interface, you will likely need to delete some pages in order to add your own work as the project consumes nearly the entire memory space of the Nextion basic panel.  If you'd like to start a new interface from the ground up, copy over the existing Page 0 page as the ESP8266 firmware makes use of page 0 for user interactions and WiFi setup.  The Home Assistant automations will probably need to be changed if any major modifications are made to the HMI.

## Nextion Page and Object IDs

Objects are referenced by page number (*not page name*) and object ID (*not object name*) as shown in the Nextion editor.  The Nextion notation for each object is of the form `p[1].b[2]` meaning page number 1, object ID 2.  Confusingly, button object *names* will start at `b0` but it might be object ID 2, or 7, etc. Other objects will be named similarly with different letters.  For example, the first text field on the page will be automatically named `t0`.  **Ignore these names**.  They have nothing to do with the object ID, and all objects regardless of type are still referenced as `p[<page number>].b[<object id>]`

Page and Object IDs

Screenshots of each object number on each page of the HASP project can be found in the [Nextion HMI documentation section](02_Nextion_HMI.md#hasp-nextion-object-reference).

An object will have multiple attributes, some of which can be changed.  For example, a button named `p[1].b[2]` may have a "txt" attribute which we'd refer to as `p[1].b[2].txt`.  Not all attributes can be changed at runtime, the ones which can are shown in a green font in the Nextion editor (see the right pane of the image above.)

## Nextion Instruction Set

The Nextion accepts and sends commands over the serial interface.  Your Home Automation system will send Nextion instructions wrapped in an MQTT message to be delivered by HASP to your display.  A detailed guide to the Nextion instruction set can be found [here](https://nextion.tech/instruction-set/).

## Nextion color codes

The Nextion environment utilizes RGB 565 encoding.  [Use this handy convertor](https://nodtem66.github.io/nextion-hmi-color-convert/index.html) to select your colors and convert to the RGB 565 format.

## HASP Nextion Object Reference

| Page 0 | Pages 1-3 | Pages 4-5 |
|---|---|---|
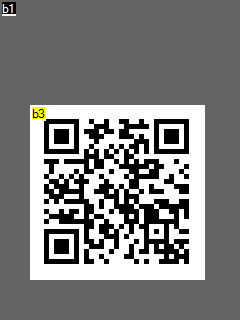
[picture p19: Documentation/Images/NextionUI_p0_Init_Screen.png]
Page 0
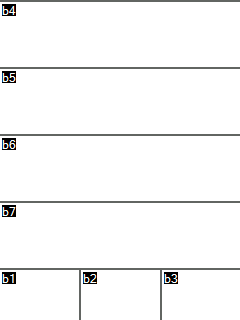
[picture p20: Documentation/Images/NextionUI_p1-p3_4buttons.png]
Pages 1-3
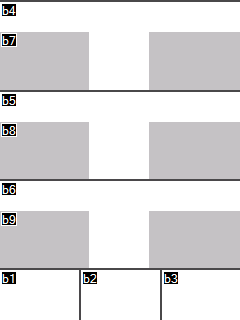
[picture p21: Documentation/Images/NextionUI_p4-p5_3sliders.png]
Pages 4-5
|  |  |  |

| Page 6 | Page 7 | Page 8 |
|---|---|---|
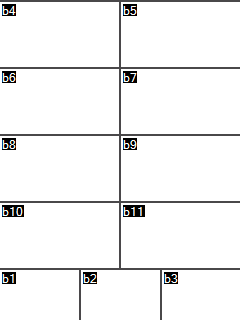
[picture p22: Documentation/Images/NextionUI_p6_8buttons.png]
Page 6
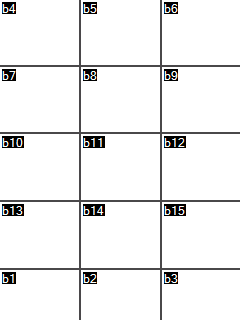
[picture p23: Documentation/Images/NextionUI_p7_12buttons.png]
Page 7
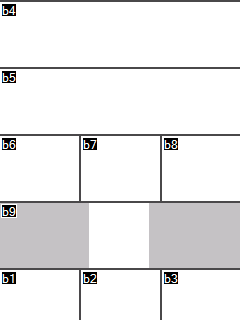
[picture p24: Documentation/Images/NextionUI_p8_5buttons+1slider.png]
Page 8
|  |  |  |

| Page 9 | Page 10 | Page 11 |
|---|---|---|
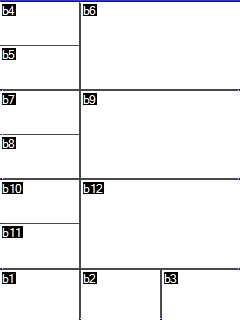
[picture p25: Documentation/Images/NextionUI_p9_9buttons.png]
Page 9
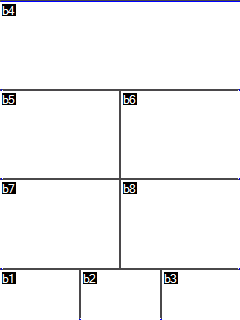
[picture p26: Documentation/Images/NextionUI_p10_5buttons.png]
Page 10
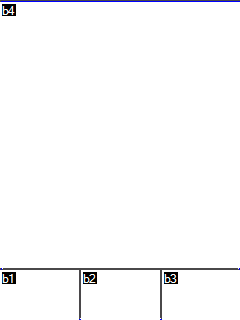
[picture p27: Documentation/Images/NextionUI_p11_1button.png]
Page 11
|  |  | 

## HASP Default Fonts

The Nextion display supports monospaced and proportional fonts.  For proportional fonts, the HASP project includes [Consolas](https://docs.microsoft.com/en-us/typography/font-list/consolas) in 4 sizes and [Webdings](https://en.wikipedia.org/wiki/Webdings#Character_set) in 1 size.

| Number | Font | Max characters per line | Max lines per button |
|---|---|---|---|
| 0 | Consolas 24 point | 20 characters | 2 lines |
| 1 | Consolas 32 point | 15 characters | 2 lines |
| 2 | Consolas 48 point | 10 characters | 1 lines |
| 3 | Consolas 80 point | 6 characters | 1 lines |
| 4 | Webdings 56 point | 8 characters | 1 lines |

The HASP also includes [Google's "Noto Sans"](https://github.com/googlefonts/noto-fonts) proportional font in 5 sizes.  These fonts also have the "[FontAwesome](https://fontawesome.com/cheatsheet)" icon set which can be mixed with normal ASCII text.

| Number | Font |
|---|---|
| 5 | Noto Sans Regular 24 point |
| 6 | Noto Sans Regular 32 point |
| 7 | Noto Sans Regular 48 point |
| 8 | Noto Sans Regular 64 point |
| 9 | Noto Sans Regular 80 point |
| 10 | Noto Sans Bold 80 point |

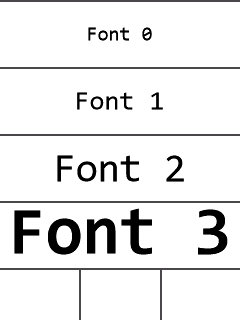
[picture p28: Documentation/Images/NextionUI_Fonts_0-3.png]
HASP Fonts 0-3
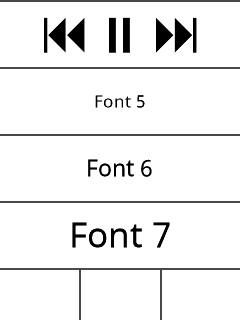
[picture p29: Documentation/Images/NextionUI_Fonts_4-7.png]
HASP Fonts 4-7
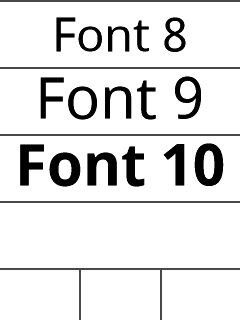
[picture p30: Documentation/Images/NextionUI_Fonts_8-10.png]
HASP Fonts 8-10
  

## Using FontAwesome Icons

FontAwesome ("FA") icons are now included with HASP in fonts 6-10 (`Noto Sans` fonts).  To use these, open the [FontAwesome Cheat Sheet](https://fontawesome.com/cheatsheet), browse to any of the "Solid", "Regular", or "Brands" pages, highlight the icon in your browser, and then paste the result into your automation or the Nextion editor.  The result in your editor should look like this: 

When sent to your LCD with the appropriate font selected (again, only fonts 6-10), the icon should show up as seen on the Cheat Sheet.  You can also mix text and icons in the same string.

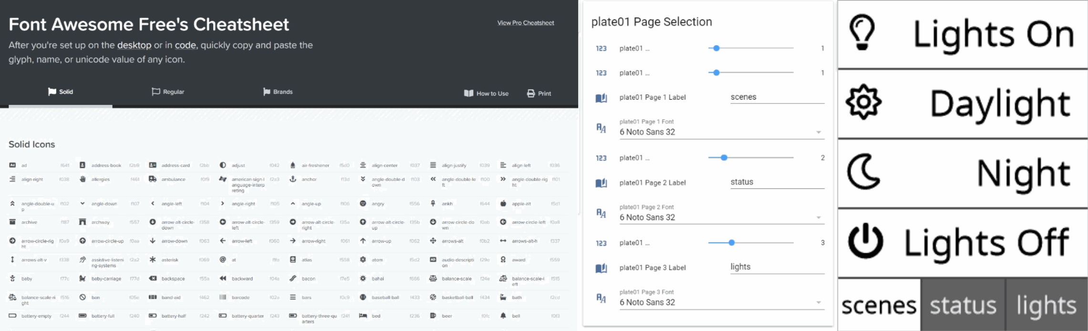
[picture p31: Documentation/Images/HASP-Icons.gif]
Using FontAwesome Icons


## HOW TO: Run this software with an ESP8266 only

One feature of the Nextion Editor is the [Nextion Simulator](https://www.itead.cc/wiki/Nextion_Editor_Quick_Start_Guide#Debug.2C_online_simulator), which allows the user to debug an HMI being edited.  You've probably used this if you've worked on editing your own HMI file.  You can run through the screens using your mouse to issue touch commands and feed it commands and see output in the text boxes provided.

The Nextion simulator allows you to run [hardware-in-loop](https://en.wikipedia.org/wiki/Hardware-in-the-loop_simulation) with your microcontroller.  If you have a second USB UART kicking around (you could use a second WeMos or Arduino if you have one handy), connect the UART RX to pin D4 and the TX to pin D7 which are the pins you'd use to hook up a real panel.  In the Nextion Simulator you can then select "User MCU Input", select your UARTs COM port, set the Baud to 115200, then click Start.

Now the Simulator will accept input from and send output to your flashed ESP8266 without having a Nextion on hand!

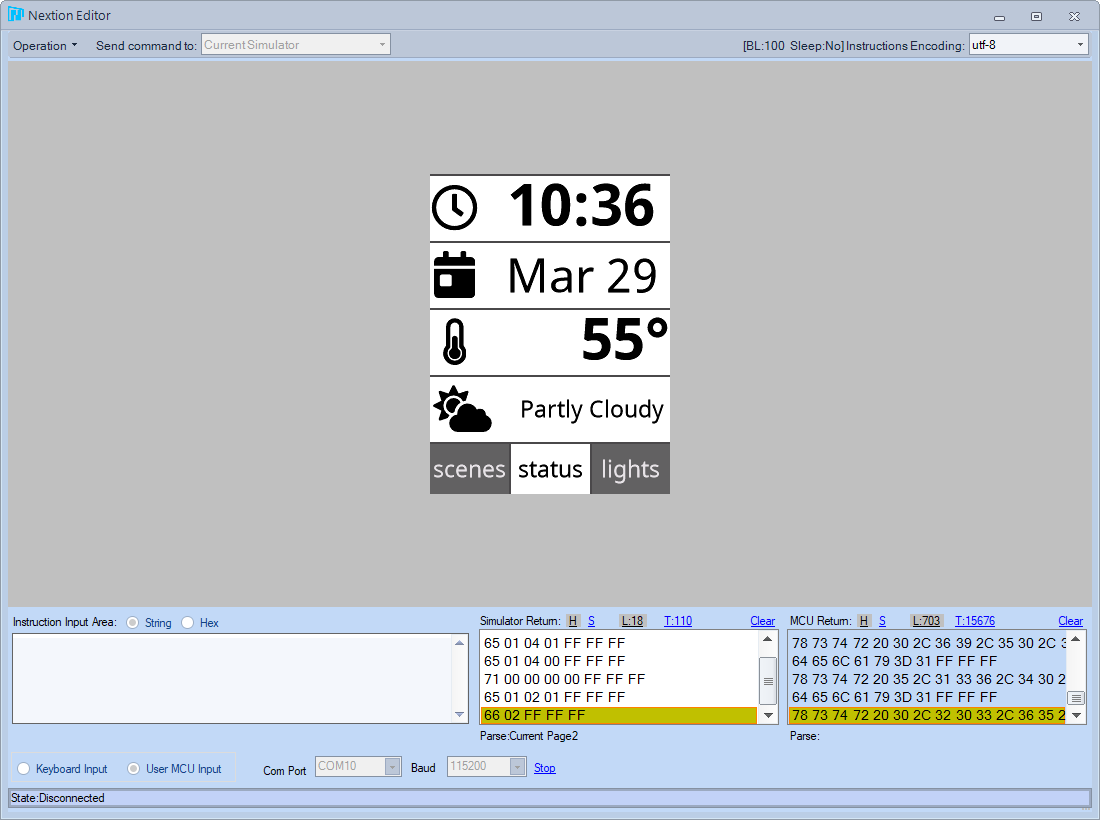
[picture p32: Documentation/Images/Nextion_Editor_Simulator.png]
Nextion Editor Simulator


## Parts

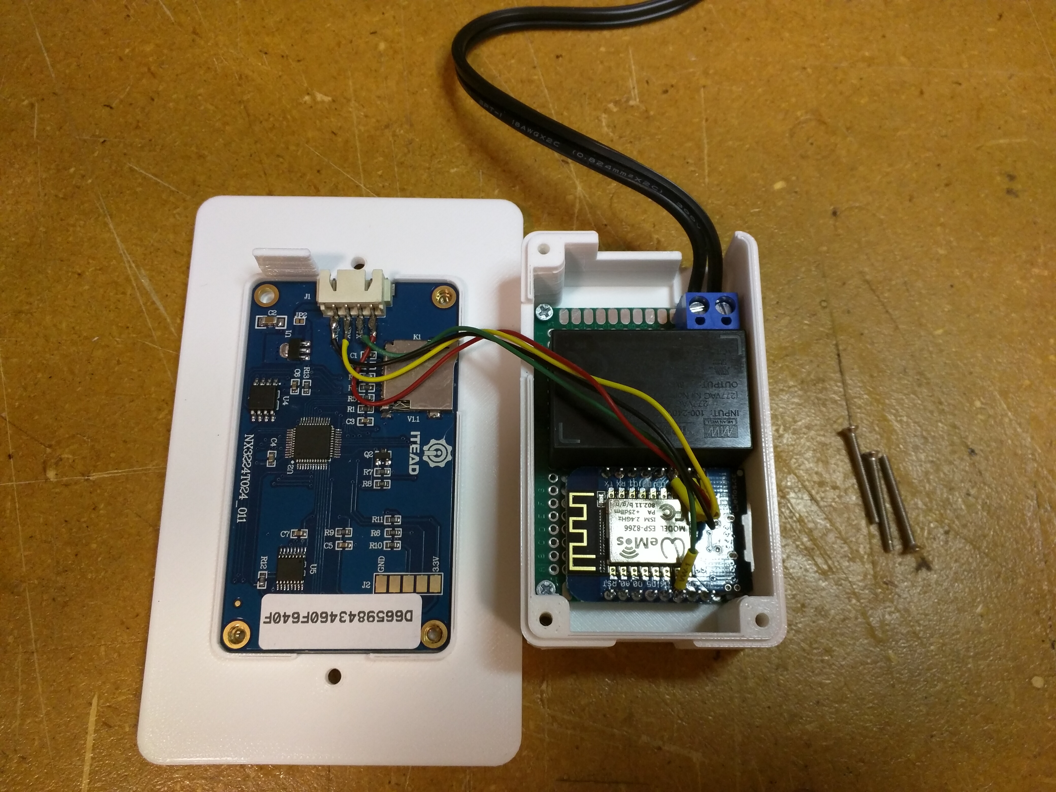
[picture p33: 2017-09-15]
Documentation/Images/Perfboard_Assembly_Parts_Installed.jpg

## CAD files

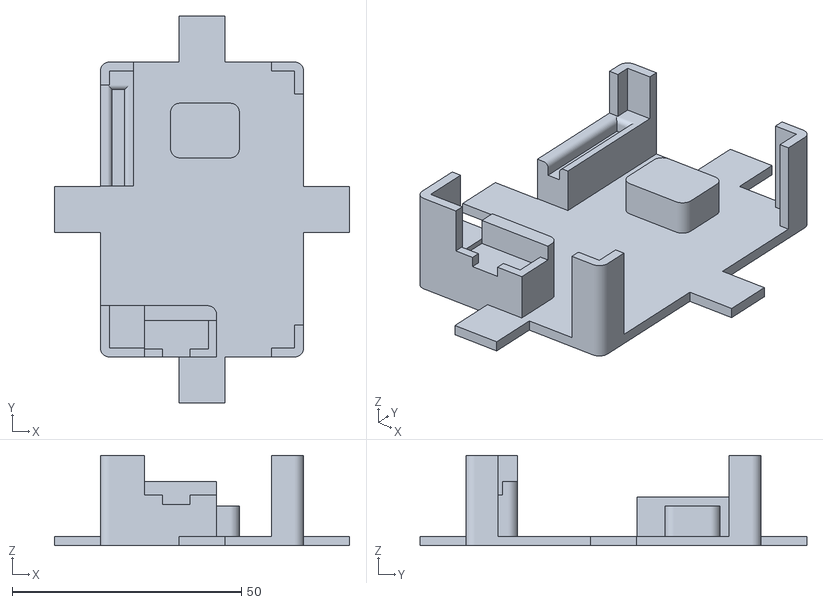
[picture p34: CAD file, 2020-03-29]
3D_Printable_Models/HASwitchPlate_assembly_jig.stl
64.4 x 84.4 x 19.7

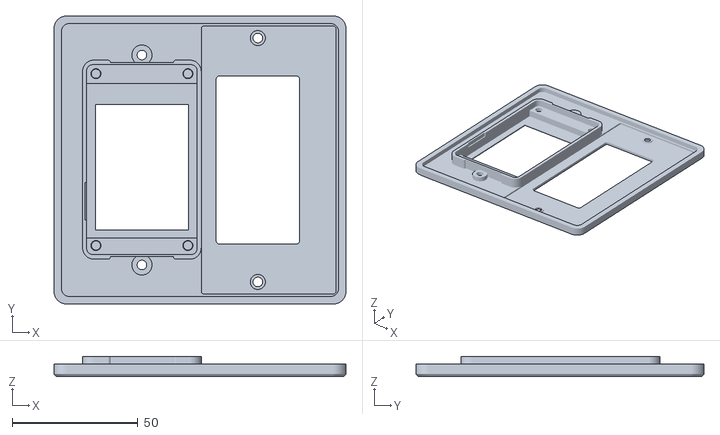
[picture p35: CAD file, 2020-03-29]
3D_Printable_Models/HASwitchPlate_front_2x_hasp_decora.stl
115.9 x 114.3 x 8.00

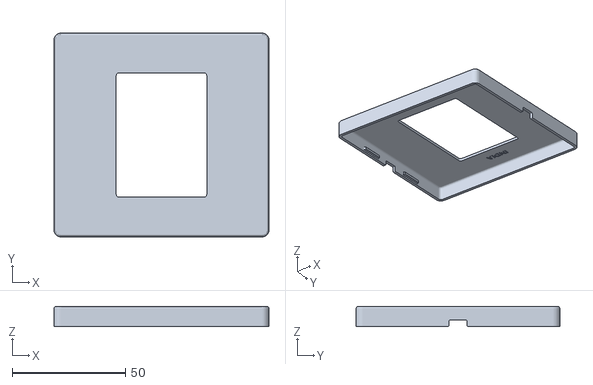
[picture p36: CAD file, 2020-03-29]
contrib/3D_Printable_Models/HASP_frontcover_India_V2.STL
95.0 x 90.0 x 9.00

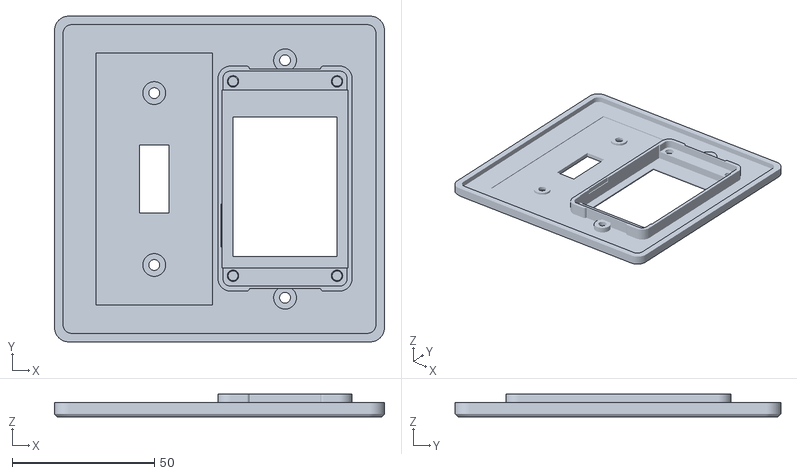
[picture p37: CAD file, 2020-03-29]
3D_Printable_Models/HASwitchPlate_front_2x_toggle_hasp.stl
115.8 x 114.3 x 8.00

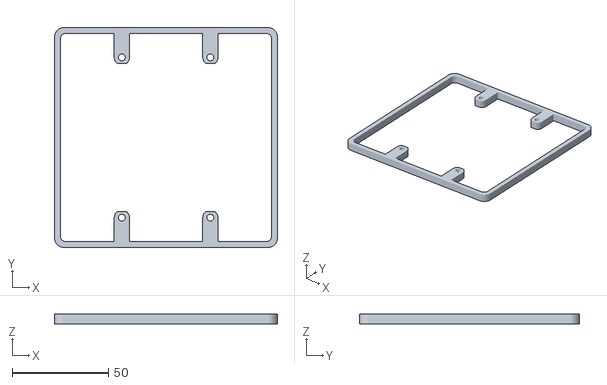
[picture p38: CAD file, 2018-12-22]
contrib/3D_Printable_Models/HASwitchPlate_double_spacer.stl
115.9 x 114.3 x 5.00

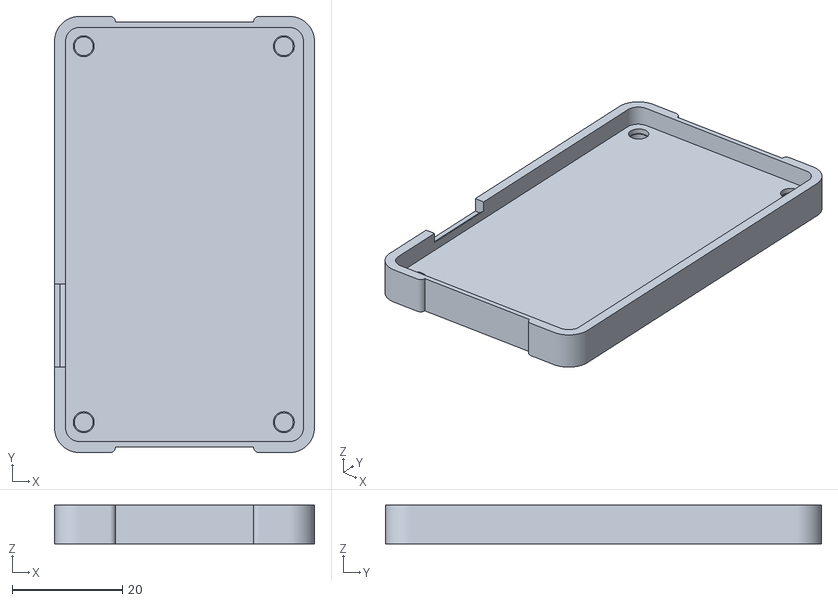
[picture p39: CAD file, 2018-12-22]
contrib/3D_Printable_Models/HASwitchPlate_front_nolcd.stl
47.1 x 79.0 x 7.00

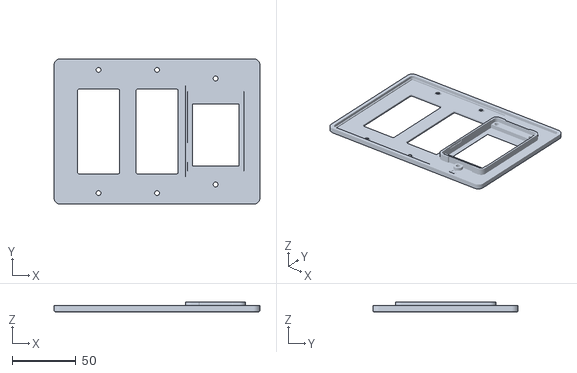
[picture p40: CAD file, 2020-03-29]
3D_Printable_Models/HASwitchPlate_front_3x_decora_decora_hasp.stl
161.9 x 114.3 x 8.00

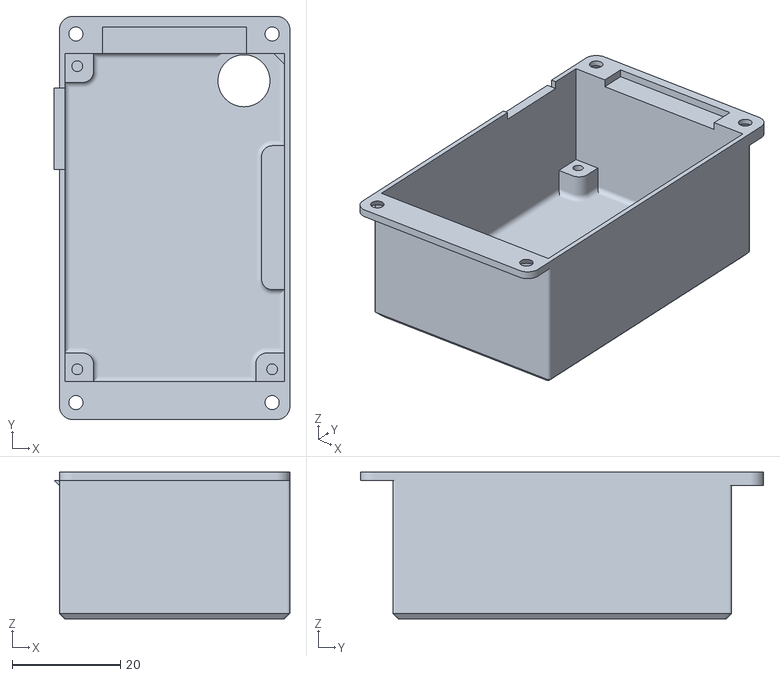
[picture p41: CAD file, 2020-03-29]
3D_Printable_Models/HASwitchPlate_rear_lcdmod_minimum_clearance.stl
43.6 x 74.5 x 27.1

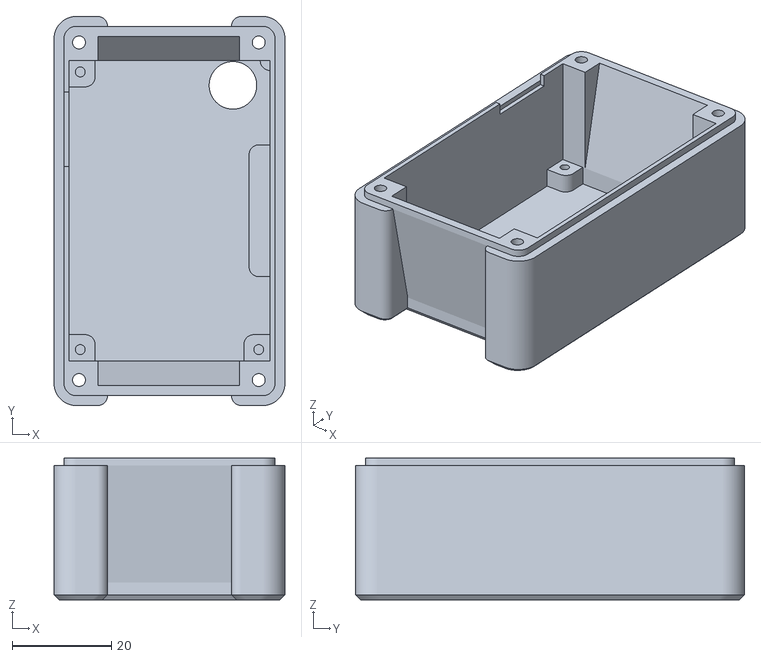
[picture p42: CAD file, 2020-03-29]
3D_Printable_Models/HASwitchPlate_rear_lcdmod.stl
46.6 x 78.5 x 28.6

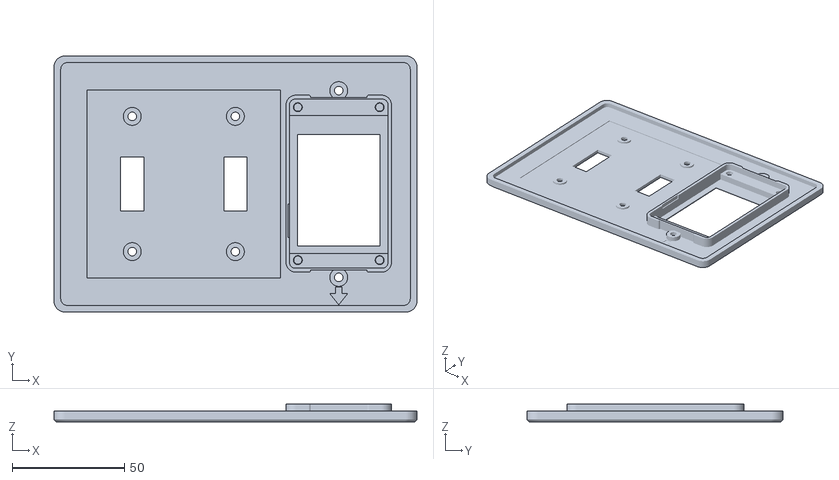
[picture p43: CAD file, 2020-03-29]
3D_Printable_Models/HASwitchPlate_front_3x_toggle_toggle_hasp.stl
161.9 x 114.3 x 8.00

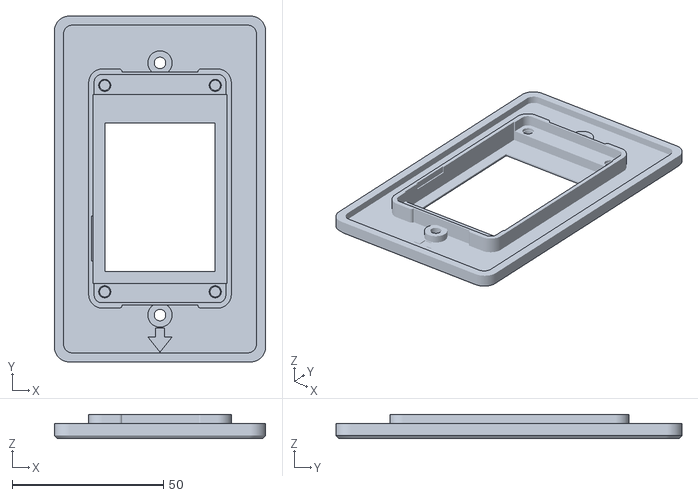
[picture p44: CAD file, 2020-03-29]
3D_Printable_Models/HASwitchPlate_front_single.stl
69.8 x 114.3 x 8.00

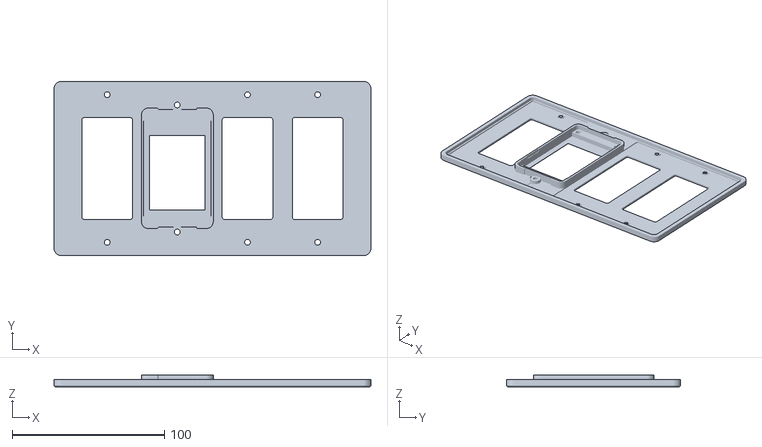
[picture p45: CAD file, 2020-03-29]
3D_Printable_Models/HASwitchPlate_front_4x_decora_hasp_decora_decora.stl
207.9 x 114.3 x 8.00

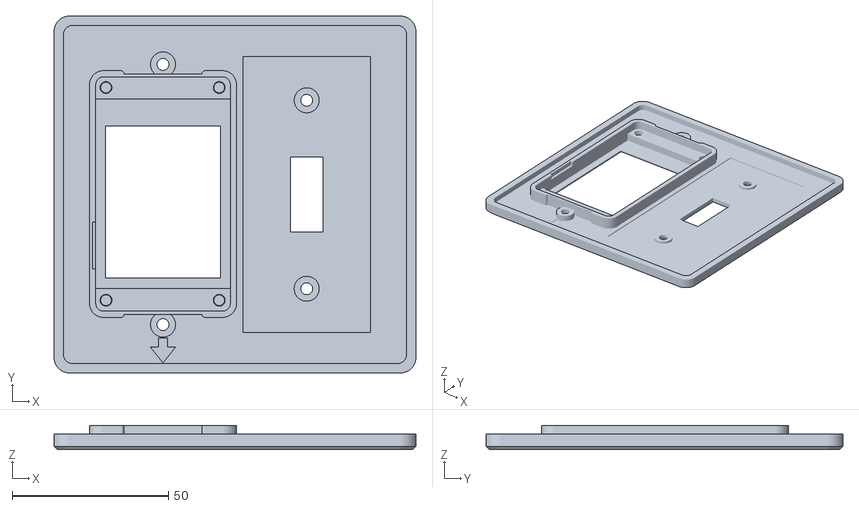
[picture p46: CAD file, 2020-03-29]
3D_Printable_Models/HASwitchPlate_front_2x_hasp_toggle.stl
115.9 x 114.3 x 7.70

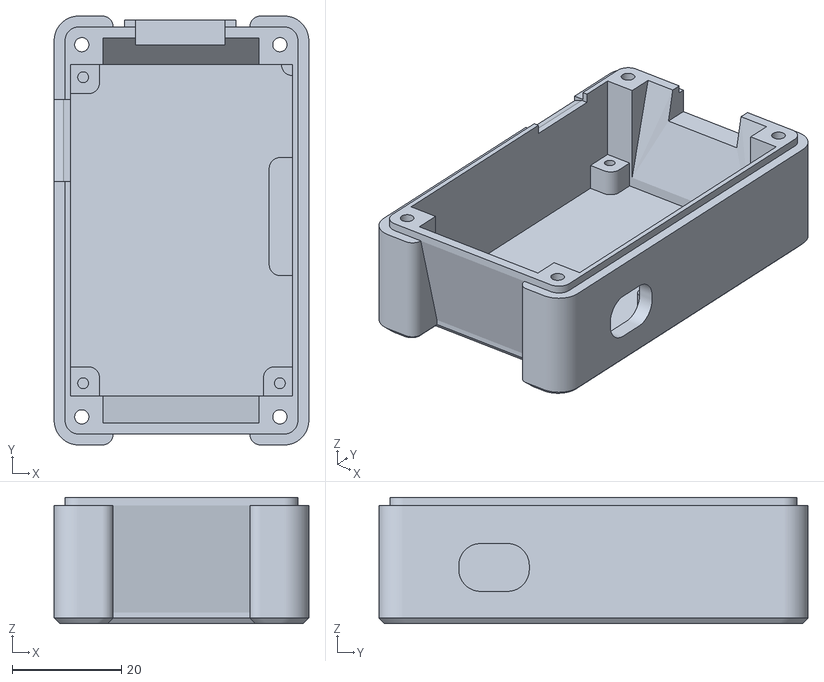
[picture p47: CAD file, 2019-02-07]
3D_Printable_Models/HASwitchPlate_desktop_rear.stl
46.6 x 78.5 x 23.1

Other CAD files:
3D_Printable_Models/HASwitchPlate_front_3x_hasp_decora_decora.stl
3D_Printable_Models/HASwitchPlate_front_2x_decora_hasp.stl
3D_Printable_Models/HASwitchPlate_front_3x_decora_hasp_decora.stl
3D_Printable_Models/HASwitchPlate_front_3x_hasp_toggle_toggle.stl
3D_Printable_Models/HASwitchPlate_desktop_base.stl
3D_Printable_Models/HASwitchPlate_desktop_front.stl
3D_Printable_Models/HASwitchPlate_front_single_UK-UNTESTED.stl
3D_Printable_Models/HASwitchPlate_front_single_dev.stl
3D_Printable_Models/HASwitchPlate_rear_dev.stl
3D_Printable_Models/HASwitchPlate_rear_nolcdmod.stl
contrib/3D_Printable_Models/HASwitchPlate_contrib.skp

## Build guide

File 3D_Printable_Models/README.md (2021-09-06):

# We're Moving!

This repository is an archived snapshot of the pre-1.0 HASP project.

## [Click here to head to the new home for HASPone!](https://github.com/HASwitchPlate/HASPone)

Below you'll find saved information about previous versions of HASP.

---

# Switch Plate model for single-gang workbox

## 3D Printed Enclosure

Above you'll find STL files ready for slicing and the source models editable in the free edition of [SketchUp Make](https://www.sketchup.com/download).  There are several models presented here for various plate configurations on the front and two options for the rear enclosure.

For most users, you'll want to print [HASwitchPlate_front_single.stl](HASwitchPlate_front_single.stl) and [HASwitchPlate_rear_nolcdmod.stl](HASwitchPlate_rear_nolcdmod.stl).

### Front plate models

* **[HASwitchPlate_front_single.stl](HASwitchPlate_front_single.stl)** Standard single-wide plate. `[HASP]`
* **[HASwitchPlate_front_2x_hasp_decora.stl](HASwitchPlate_front_2x_hasp_decora.stl)** Double-wide plate with Decora switch to the right `[HASP|Decora]`
* **[HASwitchPlate_front_2x_hasp_toggle.stl](HASwitchPlate_front_2x_hasp_toggle.stl)** Double-wide plate with toggle switch to the right `[HASP|toggle]`
* **[HASwitchPlate_front_3x_hasp_decora_decora.stl](HASwitchPlate_front_3x_hasp_decora_decora.stl)** Triple-wide plate with Decora switches to the right `[HASP|Decora|Decora]`
* **[HASwitchPlate_front_3x_hasp_toggle_toggle.stl](HASwitchPlate_front_3x_hasp_toggle_toggle.stl)** Triple-wide plate with toggle switches to the right `[HASP|toggle|toggle]`
* **[HASwitchPlate_front_5x_decora_decora_hasp_decora_decora.stl](HASwitchPlate_front_5x_decora_decora_hasp_decora_decora.stl)** 5-wide plate with 4x Decora switches and HASP in center `[Decora|Decora|HASP|Decora|Decora]`
* **[HASwitchPlate_front_single_dev.stl](HASwitchPlate_front_single_dev.stl)** Standard single-wide plate with SD card exposed for development use (unsafe!) `[HASP]`

### Rear enclosure models

* **[HASwitchPlate_rear_lcdmod.stl](HASwitchPlate_rear_lcdmod.stl)** The `lcdmod` enclosure requires the removal of the 4-pin XHP connector from the Nextion LCD panel.  This option allows for better clearance around the screw posts which may help in tight work boxes, but the process of safely removing the connecter may require a hot air station.
* **[HASwitchPlate_rear_nolcdmod.stl](HASwitchPlate_rear_nolcdmod.stl)** The `nolcdmod` enclosure does not require removing the 4-pin XHP connector from the Nextion LCD panel.  This simplifies the build process but has just a little less room behind the device for the work box screws.  We're not talking a lot here, so if you don't have the hot air station this option will probably work fine for you.
* **[HASwitchPlate_rear_lcdmod_minimum_clearance.stl](HASwitchPlate_rear_lcdmod_minimum_clearance.stl)** The `lcdmod_minimum_clearance` rear enclosure has been modified to provide the tightest fit around the HASP components that I can work out.  The walls are flimsy and thin, it will require supports to print, and you'll need 4 x [4mm M2 countersunk screws](https://amzn.to/2Eaz9wl) to assemble.  I don't recommend this enclosure unless you can't get the standard enclosure to fit in your workbox.
* **[HASwitchPlate_rear_dev.stl](HASwitchPlate_rear_dev.stl)** The `dev` enclosure has USB, SD card, and Nextion XHP connector exposed for development/test purposes.  This is unsafe to install in your workbox.

### Desktop models

An enclosure designed for desktop (table, bedstand, etc) use has been developed.  The enclosure will fit the standard PCB, WeMos D1 Mini, and Nextion 2.4" but will not allow installation or use of the AC PSU.  Power is provided by USB connection to the WeMos D1 Mini.

* **[HASwitchPlate_desktop_front.stl](HASwitchPlate_desktop_front.stl)** Front panel for desktop use with opening for SD card access
* **[HASwitchPlate_desktop_rear.stl](HASwitchPlate_desktop_rear.stl)** Rear enclosure for desktop use with openings for SD card, USB, and Nextion Serial access
* **[HASwitchPlate_desktop_base.stl](HASwitchPlate_desktop_base.stl)** Handy base for desktop use.  Print with higher infill to add mass to weigh it down a bit.

## 3D Printing Notes

### FDM affordance

The careful observer might note that the dimensions of the model vary just slightly from the [published dimensions](https://www.itead.cc/wiki/images/a/ad/2.4%27%27_Nextion_Dimension.pdf) of the panel used in this project.  This has been done to accommodate the nature of FDM 3D printing, which means that other production technologies may require slight modifications to make everything fit snug.  The STLs are published in the correct orientation for printing.

### Filament

I printed these two parts with [AmazonBasics White PETG](https://amzn.to/2I6ctPd) on a [Prusa i3 MK3](https://shop.prusa3d.com/en/3d-printers/180-original-prusa-i3-mk3-kit.html) with 20% infill, .15mm layers, no supports, and 6 bottom layers.  PETG provides good flexibility when mounting the device into your wall, as sometimes the drywall, workbox, etc require a little bit of flex.  PLA might work, but may crack in some installations.  If you have both on hand, print the front in PETG and the back in PLA.

### Inserts

The mounting holes for the Nextion panel are sized to fit [M2 x 3mm threaded inserts](https://amzn.to/2N511Fh) but should accept an M3 screw (tightly).  See [the enclosure build documentation](../Documentation/04_Project_Enclosure.md#threaded-inserts) for more details.

### SketchUp

The SketchUp file included here is dimensioned in meters but 1m == 1mm due to issues with how SketchUp (doesn't) handle small dimensions.  If you intend to modify the provided SketchUp model, export to STL in meters then import for print in mm (the standard setting for most slicers) and you'll be fine.  The included STLs are ready to slice as-is.

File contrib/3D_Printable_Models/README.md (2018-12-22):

# Additional User Contributed 3D Printable Models

HASwitchPlate_double_spacer.stl - 5mm spacer between front switchplate and wall. 

HASwitchPlate_front_double_blank.stl - Left HASP module and right is a blank for two gang boxes

HASwitchPlate_front_nolcd.stl - Solid front plate to separate LCD from D1/Power

HASwitchPlate_contrib - Source files for above

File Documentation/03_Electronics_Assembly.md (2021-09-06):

# We're Moving!

This repository is an archived snapshot of the pre-1.0 HASP project.

## [Click here to head to the new home for HASPone!](https://github.com/HASwitchPlate/HASPone)

Below you'll find saved information about previous versions of HASP.

---

# Electronics Assembly

## Test Assembly

Once the [ESP8266](01_Arduino_Sketch.md) and [Nextion](02_Nextion_HMI.md) firmware images have been flashed, you can connect the two devices together using the following wiring map:

| WeMos Pin | Nextion Cable |
|---|---|
| 5V | Red |
| GND | Black |
| D7 | Blue |
| D4 | Yellow |

### First-time Setup

With your device flashed and wired up, plug the WeMos into a USB port to power up your HASP.  You should be presented with an initialization screen and then information regarding WiFi access along with a QR code for easy connection.  With a PC or mobile device, connect to the WiFi SSID and password displayed on the Nextion (or serial output if you don't have the Nextion ready).  You should be prompted to open a [configuration website](http://192.168.4.1) which will allow you to configure HASP to connect to your WiFi network.  You can set the MQTT broker information and admin credentials now, or use the web interface to do so later.  Once you `save settings` the device will connect to your network.  Congratulations, you are now online!

WiFi Config 0 WiFi Config 1 WiFi Config 2

If you are still testing the HASP before complete assembly, continue to the [Home Assistant section](05_Home_Assistant.md) to configure your Home Assistant installation to support your HASP device.

---

## Complete Electronics Assembly

### BOM

* [Nextion 2.4" LCD Touchscreen display](https://amzn.to/2RksiXr)
* [WeMos D1 Mini ESP8266 WiFi microcontroller](https://amzn.to/2UZlga4)
* [Mean Well IRM-03-5 AC to 5VDC Power supply](https://amzn.to/2UUWGa8)
* [2N3904 NPN Transistor](https://amzn.to/2TRuwwD)
* [1k Ohm Resistor](https://amzn.to/2Ec3kTZ)
* [4pin 2.54mm JST-XH PCB header](https://amzn.to/2Eaywmt) *(note that these are the knockoff 2.54mm versions of the 2.50 XH series from JST.  What they lack for in authenticity they make up for in ubiquity and dirt cheap pricing)*
* [PCB](../PCB)
* [6" each of white and black 300V 18AWG stranded power cables](https://amzn.to/2EcMmoA)

> ## WARNING: do not connect AC power and USB at the same time, as there is a chance you could fry your USB ports.  Always disconnect AC before connecting USB or serial to the ESP8266 and Nextion panel (or doing anything else to the device for that matter)

### PCB Unassembled

This is what your PCB should look like from the top before you've placed any of the components.

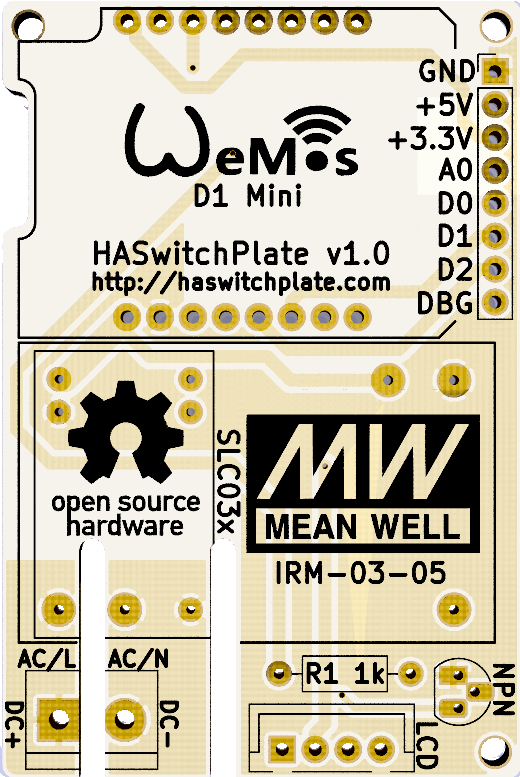
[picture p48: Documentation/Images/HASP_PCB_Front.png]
PCB Unassembled


### PCB Assembled

Now place the components, taking care to orient the WeMos D1 Mini, Mean Well Power Supply, and JST-XH header as shown in the image below.

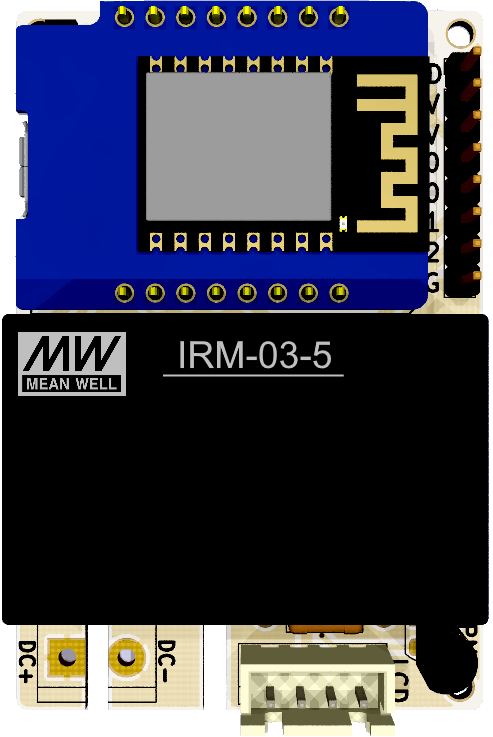
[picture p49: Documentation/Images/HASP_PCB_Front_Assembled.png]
PCB Assembled


### Transistor soldering

The transistor and resistor act as a switch on the GND connection for the Nextion LCD.  This allows the HASP to reboot the LCD in the event of a failed LCD firmware update.  The pads on the transistor are a little close together, so take care when soldering here and use as little solder as possible.  **The LCD will not power on until the ESP8266 code is flashed and running**, sending power to the "switch" to turn on the LCD.  If you've flashed the ESP8266 code to the WeMos, you've connected the LCD, you can see the program running in the serial console, and the display isn't powering on... you almost certainly have a problem with the soldering job on the transistor.  If you just can't make it work, that's OK!  Simply cut the resistor out of the circuit (important!), and then you can bridge the 3 pads for the transistor together with a glob of solder.  This will disable the power switch for the LCD, which might mean pulling the device out of the wall if an LCD firmware update fails but will not otherwise impact daily operation.

### High voltage AC cabling

The AC power cables should be at least [18AWG 300V stranded cable](https://amzn.to/2EcMmoA) with a white jacket soldered to the `AC/N` pad on the PCB and a similar wire with a black jacket soldered to `AC/L`.  These are fed through a [rubber push-in grommet](https://amzn.to/2N6Etny) mounted into the rear enclosure.  I've had good luck stripping an existing 3 conductor power cord and using the black/white wires inside.

### Nextion LCD Modification

The Nextion LCD can be modified to give a little extra room around the screw lugs which may help with mounting in some work boxes.  If you have the means to do so, you can use a hot air gun to remove the 4-pin JST XHP connector from the PCB and then use the [`lcdmod` rear enclosure model](../3D_Printable_Models/HASwitchPlate_rear_lcdmod.stl) for some extra room in your box.  If you don't have hot air, some careful use of side cutters or a rotary tool may also do the job.  Be careful not to lift any traces as it's easy to do when applying mechanical force the connector.

In any event, you're going to need to solder the cable harness included with the Nextion display directly to the pins as shown in the image below.  This demonstrates a panel with the connector removed, but you also solder the cable harness directly to the legs of the existing connector with a simple soldering iron with little trouble.  After soldering the cables in place and confirming everything works, I like to put a bit of hot glue over the wires to provide some measure of strain relief.

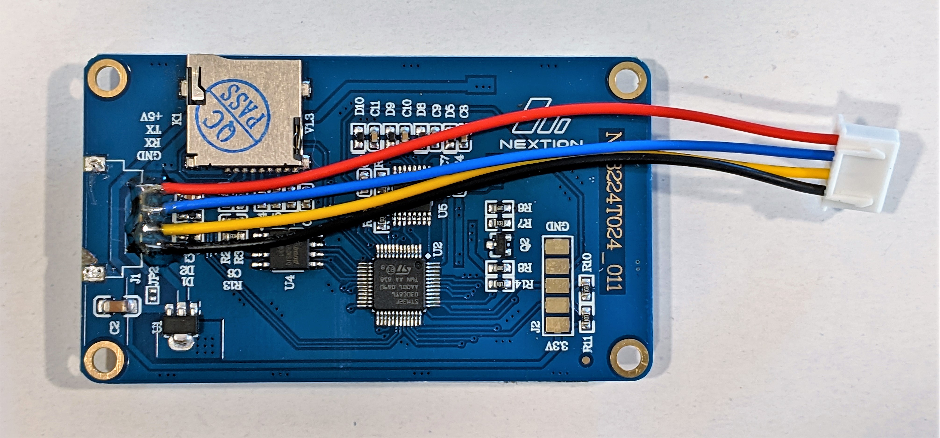
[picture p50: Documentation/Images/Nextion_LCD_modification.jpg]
Nextion_LCD_modification


### DC Power Option

The [Mean Well IRM-03-5 AC to 5VDC Power supply](https://amzn.to/2UUWGa8) can be substituted with any of the following [Mean Well SLC03-series DC-DC power supplies](http://www.meanwellusa.com/productPdf.aspx?i=786) if you'd prefer a low-voltage DC option.  This should be suitable for use over existing Cat5 cables, speaker cables, alarm cabling, etc already in your wall.  Check to confirm that the existing cable wire gauge will be safe for the load you will be putting on the system, and try not to put voltage down a wire where other expensive and flammable things might be connected which aren't expecting it.

| Model | Input Voltage Range |
|---|---|
| SLC03A-05 | 9-18VDC |
| SLC03B-05 | 18-36VDC |
| SLC03C-05 | 36-75VDC |

These DC-DC supplies are smaller than the AC-DC supply and have a different footprint on the board.  Position the supply as shown below.

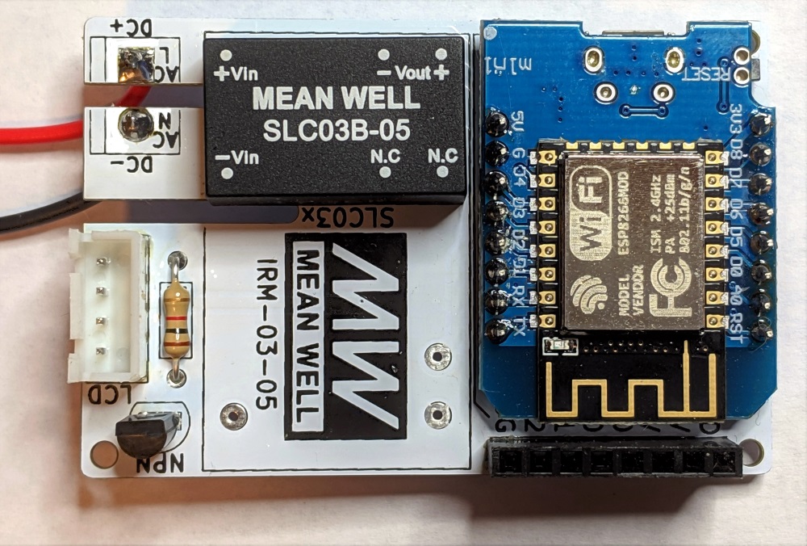
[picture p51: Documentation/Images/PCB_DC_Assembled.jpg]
PCB_DC_Assembled


### Schematic for protoboard assembly

This project was initially built on a [4x6 protoboard](https://amzn.to/2N6IqbM) and the enclosure should still accommodate this approach if you have boards on hand.  Note that this approach is probably dangerous as 120VAC and protoboards are a bad mix.

The parts should be fit much as shown in the PCB images above.  In my case the bottom-most row of 8 pins on the WeMos D1 mini [as shown in this image](https://raw.githubusercontent.com/aderusha/HASwitchPlate/master/Documentation/Images/Perfboard_Assembly_Parts_Installed.jpg) would not fit on the perforated area of the board, instead I soldered the pin header with the pins projecting upward from the board to attach wires above.  It wasn't pretty, it's likely not safe, and you really should use the PCB.

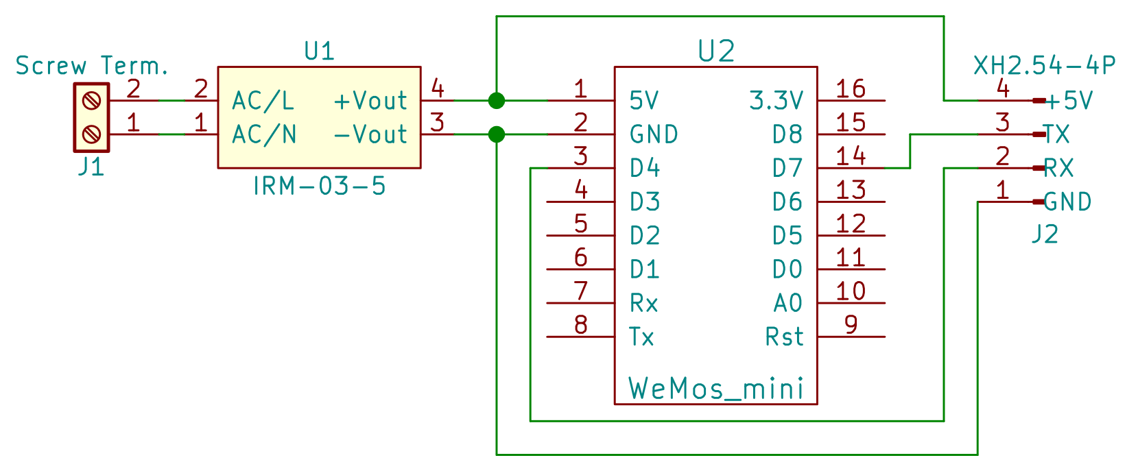
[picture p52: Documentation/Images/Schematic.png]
Schematic


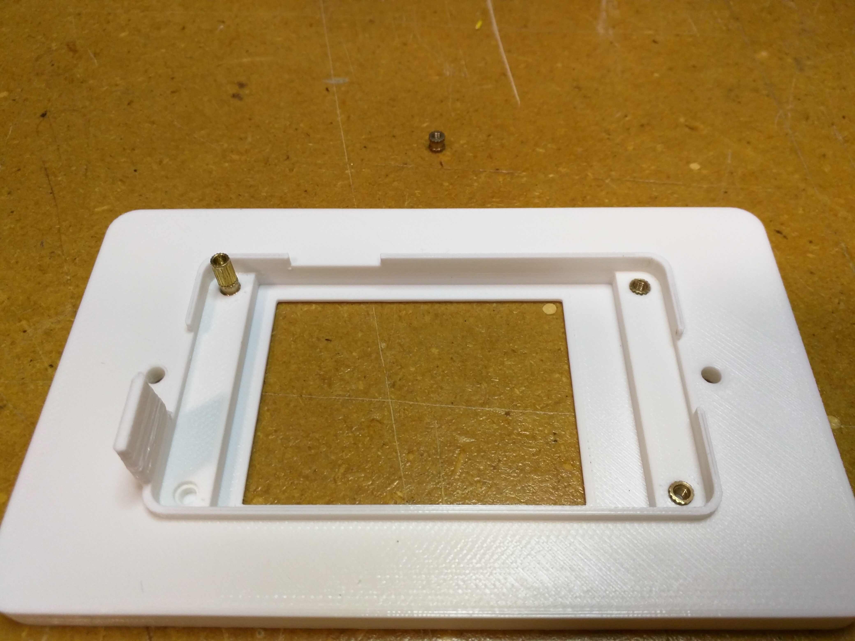
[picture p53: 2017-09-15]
Documentation/Images/Assembly_Installing_Inserts.jpg

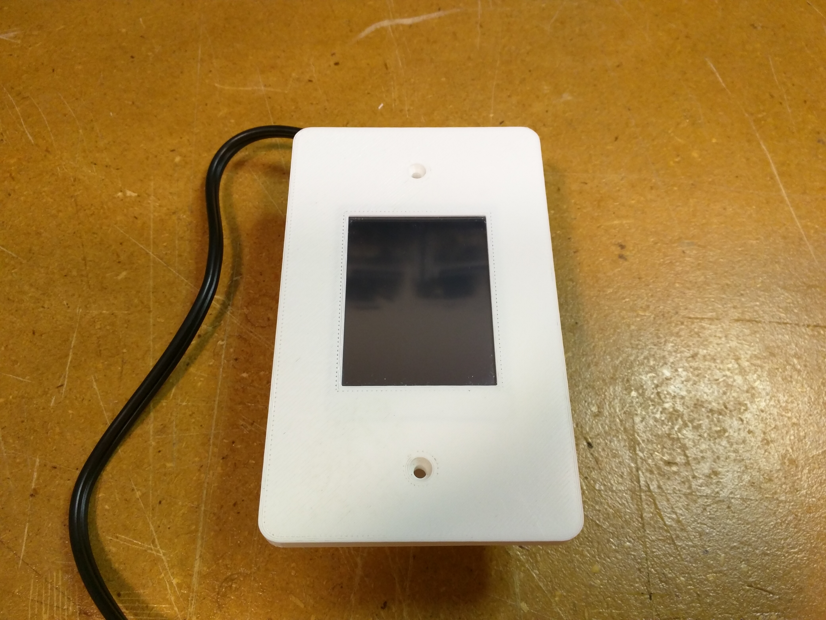
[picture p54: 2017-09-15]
Documentation/Images/Assembly_Assembled_Front.jpg

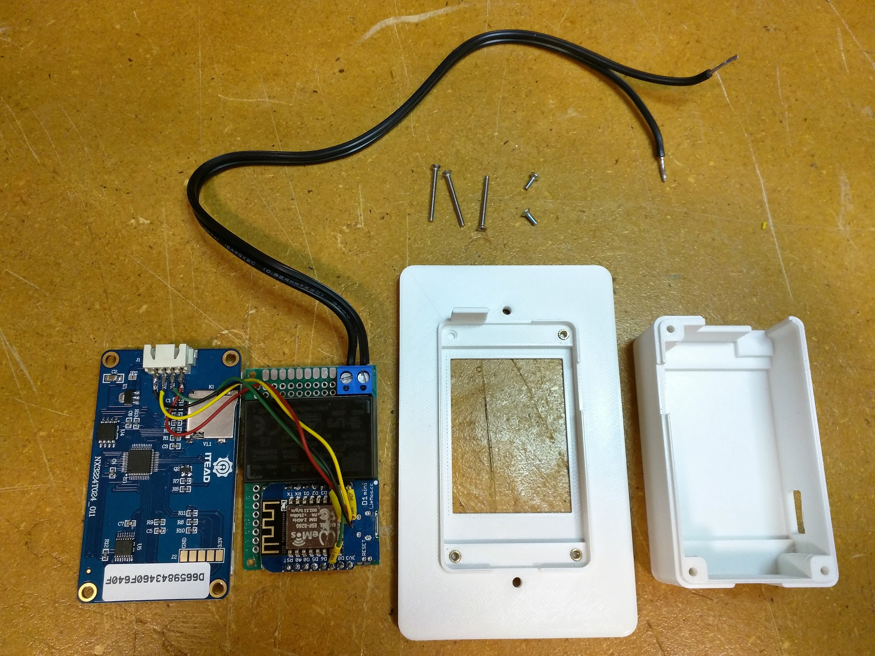
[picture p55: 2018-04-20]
Documentation/Images/Perfboard_Assembly_Ready_to_Assemble.jpg

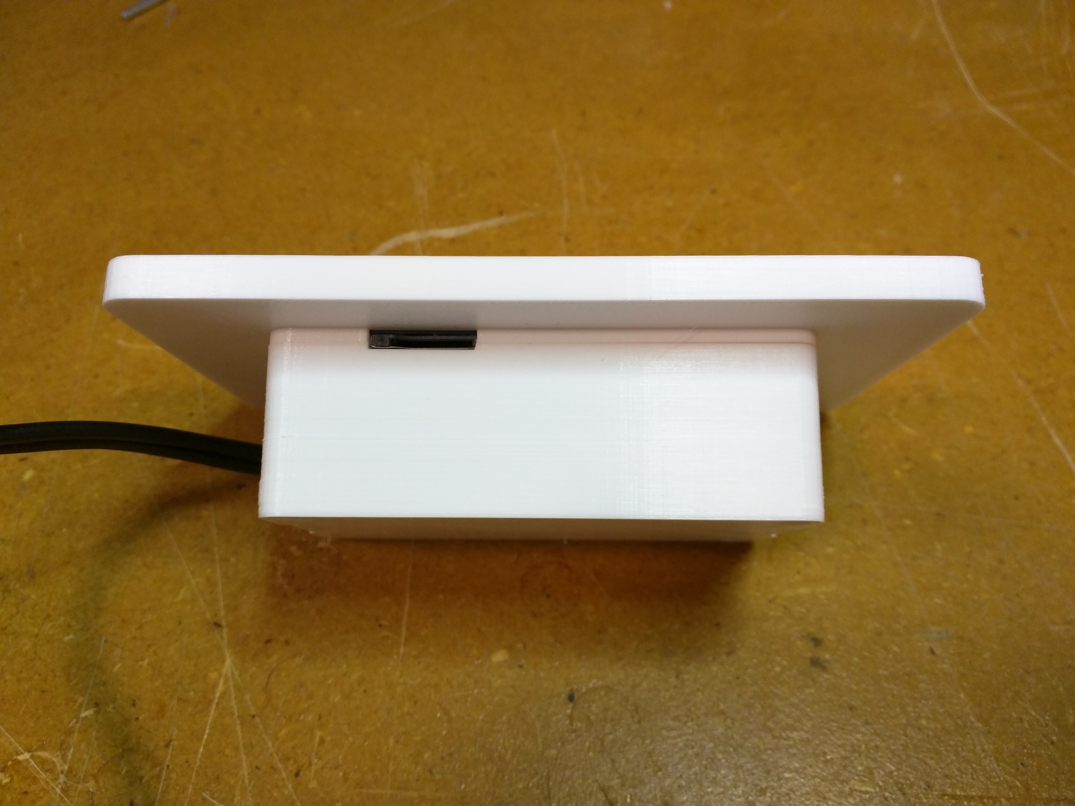
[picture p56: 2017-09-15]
Documentation/Images/Assembly_Assembled_Side.jpg

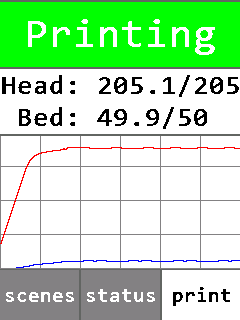
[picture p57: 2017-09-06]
Documentation/Images/HASwitchPlate_Demo_PrintStatus.png

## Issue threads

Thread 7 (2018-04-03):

HASwitchPlate Connected automation triggers multiple times

squirtbrnr, 2018-04-03:
The HASwitchPlate_Connected automation triggers multiple (close to 15 times) when cycling power on the panel or when it reconnects to WiFi/MQTT

squirtbrnr, 2018-04-03:
file: HASwitchPlatePages.yaml

aderusha, 2018-04-18:
I can't seem to reproduce this behavior.  I've deployed a new instance of hass (currently `0.67.1`) and deployed the stock config from the repo here with the following command:
`svn export https://github.com/aderusha/HASwitchPlate/trunk/Home_Assistant ~/.homeassistant --force`

I started up Hass and configured the default state of the page selection buttons with the following commands:
```
curl -X POST -H "x-ha-access: YOUR_PASSWORD" -H "Content-Type: application/json" -d '{ "entity_id": "input_text.haswitchplate_pagebutton1_label", "value": "scenes" }' http://localhost:8123/api/services/input_text/set_value
curl -X POST -H "x-ha-access: YOUR_PASSWORD" -H "Content-Type: application/json" -d '{ "entity_id": "input_text.haswitchplate_pagebutton2_label", "value": "status" }' http://localhost:8123/api/services/input_text/set_value
curl -X POST -H "x-ha-access: YOUR_PASSWORD" -H "Content-Type: application/json" -d '{ "entity_id": "input_text.haswitchplate_pagebutton3_label", "value": "media" }' http://localhost:8123/api/services/input_text/set_value
curl -X POST -H "x-ha-access: YOUR_PASSWORD" -H "Content-Type: application/json" -d '{ "entity_id": "input_number.haswitchplate_pagebutton1_page", "value": 1}' http://localhost:8123/api/services/input_number/set_value
curl -X POST -H "x-ha-access: YOUR_PASSWORD" -H "Content-Type: application/json" -d '{ "entity_id": "input_number.haswitchplate_pagebutton2_page", "value": 2}' http://localhost:8123/api/services/input_number/set_value
curl -X POST -H "x-ha-access: YOUR_PASSWORD" -H "Content-Type: application/json" -d '{ "entity_id": "input_number.haswitchplate_pagebutton3_page", "value": 8}' http://localhost:8123/api/services/input_number/set_value
curl -X POST -H "x-ha-access: YOUR_PASSWORD" -H "Content-Type: application/json" -d '{ "entity_id": "input_number.haswitchplate_active_page", "value": 1}' http://localhost:8123/api/services/input_number/set_value
```
Once Hass has initialized I powered on the HASwitchPlate and observed all automations running once.  I power cycled the HASwitchPlate device several more times with Hass running and observed the same behavior each time.

Can you test this with a clean configuration by chance?  Is there any way another automation you've deployed might be interacting somehow?

aderusha, 2018-04-22:
I've narrowed the issue down to two compounding problems.  One is [an issue with Hass for which I have submitted a bug report](https://github.com/home-assistant/home-assistant/issues/14047).  With MQTT discovery enabled, hass is sending multiple replies in response to a single trigger.  This behavior is compounded by the page switching automations, which in certain cases can result in the page command being sent twice.  Because Hass is duplicating the automation response, the system can get stuck in a loop sending page commands back and forth, each of which triggers an additional cascade of MQTT messages until the Arduino code can't keep up and either resets or takes too long to respond to keep the loop going.  The result can be 10 or more responses on some of the page flipping automations.

squirtbrnr, 2018-05-06:
this is still occurring.  in fact I have the switch plate disconnected from power yet whenever I restart HA, the state goes back to "Connected" even though the switch plate is physically powered off, then the automation triggers now close to 25 times

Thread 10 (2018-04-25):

WiFi autoconfig not triggered on missing MQTT broker

aderusha, 2018-04-25:
The WiFi autoconfig process is triggered when the system cannot connect to WiFi with the saved SSID and password.  This leaves the system in a loop trying to connect to an MQTT broker that hasn't been defined.  The OTA service will work while in this loop, allowing you to push new firmware to the device while it's attempting to connect to MQTT, but that's not a great approach.  I think it might be better to trigger the WiFi autoconfig process if there is no saved MQTT broker defined.

zombu2, 2018-04-25:
great idea

aderusha, 2018-04-26:
With release v0.2.1 I've added a web admin panel which removes the need for this.  If the device can connect to WiFi, it opens an admin interface for basic configuration, allowing you to change MQTT settings and displaying current MQTT connection status along with any errors.  With WiFi up and running, you can now make any other configuration changes as needed.

Closed 2018-04-26.

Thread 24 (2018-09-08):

Custom Component?

rohankapoorcom, 2018-09-08:
We might be approaching the point where a custom component may be the right way to go rather than having all of the automations dealing with the MQTT directly.

Pull requests #17 , #19, #23 have been moving us towards the right direction (using python_scripts) for the actions being performed but it would be better if we created a new event that would be fired whenever a button was clicked with the button information in the event data. This would simplify the automation triggers.

Additionally, we could fire events when a HASP unit was connected/disconnected (similar to my [custom automations in my own config](https://github.com/rohankapoorcom/homeassistant-config/blob/master/packages/hasp/plates/plates_components.yaml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)

Another benefit of the custom component approach is that some point after making a custom component we could work to get it added to Home Assistant proper which would make setting up new HASP units much easier.

aderusha, 2018-09-08:
I don't really speak Python so a custom component is out of my reach.  However, if you wanted to take a swing at it I'm 100% behind the concept.  I'm going to have a difficult time contributing anything meaningful towards the component but would be thrilled if someone were to take it on!

rohankapoorcom, 2018-09-09:
Sounds good, I've made some progress towards this today. If anyone wants to try it out, it's currently on [my fork](https://github.com/rohankapoorcom/HASwitchPlate/blob/custom-component/Home_Assistant/custom_components/ha_switchplate.py)

So far, this handles all of the same stuff as the python_scripts I had added in pull requests #19, #23 as well as firing an event when a node action occurs.

Feel free to assign this issue to me. I'll keep posting here when I make meaningful updates.

aderusha, 2019-01-03:
Coming back to this - I'm still on the fence about a custom component, as it creates another environment for HASP users to learn if they want to make changes to anything.  I've tested the component and it works great!  However, we now have the ability to send a JSON object which allows Home Assistant to publish a single MQTT message with up to 4kb worth of Nextion commands which has had the impact of improving performance and reducing network traffic.  This makes me wonder if the custom component is still a net benefit.

What I'd like to do is to merge the component itself so people can experiment with it on their own if needed, but leave the stock automations as they currently exist (meaning, using the core MQTT functionality) as I believe it will be a little more approachable for new users.

Does this sound reasonable?  I really appreciate your work here and sorry this has taken so long.  I don't want to sideline the massive effort you've put into this and I'd like to make sure the work you've done is available for everyone.

rohankapoorcom, 2019-01-26:
I haven't seen this JSON object yet. Docs link?

I think the custom component is still helpful with batching these commands. For example, you can provide it a set of key value pairs representing text to update at once and the component can add the necessary logic for adjusting font sizes and batching that all at once so the user doesn't have to worry about it. I think it's also super convenient to just get the sensors provided with no configuration.

I'd like to refactor the custom component (over the last few months, I've learned a lot more about how HA code is architected) and I think it's worth basically rewriting the component. I think it's probably something we can get included in stock Home Assistant rather than as a custom component as well. That makes it much more accessible immediately.

I definitely think the component is a much better approach than the python_scripts in #19.

aderusha, 2019-06-11:
Hey @rohankapoorcom is this still under development?  Looking to cleanup issues and branches here.  Does the JSON command approach outline above do what you would expect?

rohankapoorcom, 2020-02-13:
The JSON command does do what I expect, but I'm not sure I like the way a full component makes this work super well. It gets a little inflexible in some places.

Let's keep it closed.

Closed 2020-02-13.

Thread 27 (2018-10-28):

Failed to mount FS - symptom, can't save MQTT setting.

dethpickle, 2018-10-28:
Hi, I'm going through building my own - fabulous project and instructions, btw - and am running into a problem in testing the thing when all connected.

When I initially flashed the D1 Mini and connected to it unattached to anything, I could see that my logging into the website and configuring "took".  At least, I could see through a serial monitor that it setup all the plates channels on MQTT.

So then I soldered up the D1 to the board and attached the screen and now I'm constantly getting, `Configure MQTT`.  When I look at it, it has all the WiFi configs I put in there but the MQTT is gone.  Configuring it again fails with the log looking like this: (starting with where I save the settings)

```[+3.555s] HMI OUT:  vis 3,1
[+21.850s] SPIFFS: Saving config
[+21.857s] SPIFFS: Failed to open config file for writing
[+21.868s] RESET: HASP reset

 ets Jan  8 2013,rst cause:2, boot mode:(3,6)

load 0x4010f000, len 1384, room 16
tail 8
chksum 0x2d
csum 0x2d
v614f7c32
~ld
   [+0.058s]
SYSTEM: Hardware initialized, starting program load
[+0.070s] HMI OUT:  rest
[+0.075s] SPIFFS: mounting FS...
[+0.082s] SPIFFS: [ERROR] Failed to mount FS
[+0.091s] HMI OUT:  page 0
[+0.099s] HMI OUT:  'p[0].b[1].txt="WiFi Connecting"'
[+5.057s] HMI OUT:  'p[0].b[1].txt="WiFi Connected:\r172.16.1.189"'
[+5.069s] WIFI: Connected succesfully and assigned IP: 172.16.1.189
[+5.082s] HTTP: Server started @ http://172.16.1.189
[+5.093s] ESP OTA: Over the Air firmware update ready
[+5.104s] HMI OUT:  page 0
[+5.116s] HMI OUT:  'p[0].b[1].txt="WiFi Connected!\rConfigure MQTT:\r172.16.1.189\r\r\r\r\r\r\r "'
[+5.138s] HMI OUT:  'p[0].b[3].txt="http://172.16.1.189"'
[+5.149s] HMI OUT:  vis 3,1
[+13.114s] HMI OUT:  connect
```

Any clue what I might have done?  Something in soldering or elsewhere that could result in this?  And are the comments around the FS normal?

Any thoughts would be appreciated.

Thanks,

Dave

dethpickle, 2018-10-29:
I think I found it.  When flashing with ESP8266Flasher, I needed to set the `Flash size` to 4MByte instead of the default 1MByte.

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

My apologies if I missed that in the instructions.

Closed 2018-10-29.

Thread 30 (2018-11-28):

Relay control?

jshank, 2018-11-28:
Could this setup support a single relay for local control of a device?

jshank, 2018-11-28:
Could also use this to add dimming on the PWM channel of the WeMos - https://www.aliexpress.com/item/AC-Light-Dimmer-Module-for-PWM-control-1-Channel-3-3V-5V-logic-AC-50-60hz/32802025086.html

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

jshank, 2018-11-29:
Thanks for getting back to me @aderusha. The HASP seems to be the best solution available today for dynamic control. I've ordered all of the parts for 2 of these units in an effort to replace some failing [Insteon Keypadlinc](https://amzn.to/2TTvkSe) units. I've looked for comparable Z-Wave solutions and come up very short. I've yet to find a single-gang solution that locally controls a dimming load as well as provides dimming control of 7 other devices.

I'm really excited at the possibility of context changing the buttons but bummed that I'm losing the ability to locally control the one device like the Keypadlinc does. It might be a while before the displays are here (AliExpress), can you provide the open area inside the enclosure where I might be able to add a relay/dimmer?

aderusha, 2018-11-29:
I think your best bet would be to grab something like a Shelly 1, which should fit in your box with the HASP.  If the ask is to modify the enclosure to provide more room, I'm probably not going to be adding that to the project directly although it should be doable for your own use with the provided models.

jshank, 2018-11-29:
Just wondering if there was room to incorporate the dimmer/relay into the HASP enclosure directly. The Wemos has additional GPIO capacity and I'm sure the sketch could be modified easily to control it. Unfortunately neither Shelly nor Sonoff makes an AC dimmer module.

aderusha, 2018-11-29:
The WeMos has a bit of room above it for mounting of WeMos shields. [There is approximately 12mm of usable space between the WeMos and the LCD above](https://i.imgur.com/Fv12siN.png).  If you need more room than that (and you certainly will for AC dimmers that can handle several hundred watts of load), you'd probably need to modify the enclosure.  The source files for the enclosure are available and editable via [SketchUp Make](https://www.sketchup.com/download/make).

xHirscHx, 2021-02-25:
I know this an old post but was wondering if the new .41 is going to have gpio support.  I want to use a Sonoff T3 as the base for power and the relays and retrofit the mini and screen.

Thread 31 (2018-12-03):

Faceplate Design Methods

jshank, 2018-12-03:
I'm working on recreating the faceplate in a parametric CAD tool (Fusion 360) for easier customization. I was wondering how you came up with the placement of the panel in the faceplate. I noticed the top of the screen is 30.34mm from the top of the panel (in 3D_Printable_Models/HASwitchPlate_front_double_decora_right.stl) and 35.16mm from the bottom edge. Was there a specific reason it's off center?

jshank, 2018-12-03:
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

aderusha, 2018-12-04:
That's because the actual display device (including the frame around the LCD display area) is not centered.  There is very little room between the screw holes for everything to fit, so the dimensions as you are seeing in the model are a requirement to make this work in a North American workbox.

jshank, 2018-12-04:
Thanks. I'll model mine after yours then.

Closed 2018-12-04.

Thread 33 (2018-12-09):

Too many MQTT messages.

marciogranzotto, 2018-12-09:
The idea of the project is great.
However, it's very message intensive and that demands a lot of the broker. It's causing my broker to slow down for the rest of my devices.

I propose having a batch topic, that we could send one message containing several topics and values, much like the [Tasmota Backlog command](https://github.com/arendst/Sonoff-Tasmota/wiki/Commands#using-backlog).
A simple JSON would suffice, like so:
```json
{
	"command": "dim=50",
	"command/page": 1,
	"command/p[1].b[4].txt": "Lamp On"
}
```

aderusha, 2018-12-09:
This is an interesting idea and I'll look into it further.  The latest release of the Arduino code + Home Assistant automations may resolve a lot of the MQTT traffic you're seeing, so I'd make sure you're running the latest automations and that will likely address your current problems.

Still, I think sending a JSON over with a set of commands it interesting and warrants further investigation.  Thanks for the suggestion!

aderusha, 2019-01-02:
This has been added in version 0.33 using a JSON array instead of objects, as key:value doesn't really make sense here.  Documentation [here](https://github.com/aderusha/HASwitchPlate/blob/master/Documentation/06_MQTT_Control.md#command-syntax).

Closed 2019-01-02.

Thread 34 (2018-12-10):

Recommended Motion Sensor

jshank, 2018-12-10:
I noticed the `Motion Sensor Pin` setting in the configuration and code. Is there a recommended sensor that fits in the enclosure? Any pics of the install?

aderusha, 2018-12-10:
The hardware angle is still being worked out.  I posted a solution here: https://community.home-assistant.io/t/ha-switchplate-diy-lcd-touchscreen-wall-switch-replacement/25464/726

But there are still a fair amount of false positives and the sensor performance is flakey.  Others have used a PIR sensor which works but for which there isn't any particularly good option for mounting that I've worked out yet.  Still, I think the code is useful for those looking to experiment with different hardware solutions.

Closed 2019-01-01.

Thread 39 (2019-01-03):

information for pcb

lscosta90br, 2019-01-03:
What are the dimensions height x width mm?
How many layers and thickness?

aderusha, 2019-01-03:
60mm x 40mm, dual layer, silkscreen on both sides, FR4 1.6mm board, 1oz copper, and the tracks/drills/etc are all big enough and far enough apart that they should fit into any board shops' design rules.

MrClowny666, 2019-01-04:
I just wanted to say thank you for this amazing project, it was something I was going to start looking at and then suddenly via DrZ channel I found out that you've already done all the heavy lifting!

I've never completed any PCB's before, so thank you once again. There are a lot of options on the AllPCB page - can I just leave these as standard and use the options you have listed above?

aderusha, 2019-01-04:
Yup!  I personally like how the white solder mask looks so I'd check that box but it's just an aesthetic thing :D

Closed 2019-01-10.

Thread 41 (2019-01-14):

Question: Is anyone working on a UK version

nodecentral, 2019-01-14:
As the UK have a different style of wall light switch, I was just wondering if anyone was working on something that would be compatible there ?

aderusha, 2019-01-14:
If I can get somebody to mail me a UK standard workbox I can work on developing a model to fit.  I've been unable to source them locally.

aderusha, 2019-01-14:
What I don't see are detailed IDs of the opening in the wall (the workbox itself).  There is already a [UK model](https://github.com/aderusha/HASwitchPlate/blob/master/3D_Printable_Models/HASwitchPlate_front_single_UK-UNTESTED.stl) based on a similar diagram but I have no way to test if it works, and I haven't gotten anyone in the UK to try printing it for me and reporting back.  If you have a printer, maybe give it a go and let me know what comes of it?

I'd really like to offer some international versions, but to do that I need detailed mechanical drawings (not just screw hole locations, but the entire model), and I'd strongly prefer having something physically in hand so I can mount it and do thorough print/fit testing.

welbymcroberts, 2019-02-10:
There are also a few other points of note for UK folks.

We have 3 back box depths
- 16mm - not common
- 25mm - most common
- 35mm - not common

A number of new build homes have started using the 16mm, which makes it exceedingly challenging to work with if you've got a 3 way - 3 wire switch with 1.5mm cable, however i would argue its safest to target the 25mm, as that's what most folks have.

The biggest issue however is the wiring in most boxes. Most homes in the UK have a '2 wire' light switch, which is a 'switched live', relying on the load to be connected for the switch to have a connection to neutral via the load. A '3 wire' system I believe is similar to the US where Live and Neutral are in the switch box, however we don't actually use the neutral for anything, other than putting on a connector block. Due to this we have a very limited number of relays etc that work with home automation systems, with the majority being things like LightwaveRF.

There also is the added challenge of light switches that are multiple individual switches. It's extremely common to see a 1, 2 or 3 gang light socket, all fit into the same '1 gang' socket shown above (I've not seen anything larger than a  3 switch in a 1 gang, as I think that would be impossible to fit between the two screw holes!). Which can mean even if you're not switching loads with the switch, you've got a plethora of wires to contend with.

I'm looking at options to adapt the existing PCB design into an 'u-shape' pcb that could be used in an existing light switch, without the screen. Mainly as our options for switches that don't actually switch the load directly are very few and far between, are usually touch button, or momentary buttons, both of which are not in line with what most people 'expect' for a light switch in the UK. I know its a different use case to the HASP, but it's something that I'm looking at.

I'd be happy to send some backboxes, and a switch or two for you to use for sizing.

aderusha, 2019-06-11:
Duplicate of #46

Closed 2019-06-11.

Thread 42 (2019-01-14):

LCD Reset

RDickens, 2019-01-14:
The `nextionReset()` function does not work.

You have set the `digitalWrite(nextionResetPin, LOW);` but did not set it HIGH again

`void nextionReset()`
`{`
`  digitalWrite(nextionResetPin, LOW);`
`  Serial1.print("rest");`
`  Serial1.write(nextionSuffix, sizeof(nextionSuffix));`
`  Serial1.flush();`
`  delay(2000);`
`}`

I have added a `digitalWrite(nextionResetPin, HIGH);` and `mqttClient.disconnect();`. This turns on the power to the diplay again and also forces the diplay to re-connect and sync.

`void nextionReset()`
`{`
`  digitalWrite(nextionResetPin, LOW);`
`  Serial1.print("rest");`
`  Serial1.write(nextionSuffix, sizeof(nextionSuffix));`
`  Serial1.flush();`
`  delay(2000);`
`  digitalWrite(nextionResetPin, HIGH);`
`  mqttClient.disconnect();`
`}`

aderusha, 2019-01-17:
Great catch!  I had intentionally done this the way it's written as the use cases I was considering were followed by an `ESP.reset()`.  Of course, I forgot the MQTT command `lcdreset` which *doesn't* also reset the ESP.

Next release will have this fix, thank you for digging into it, pointing it out, and providing an easy solution!

aderusha, 2019-02-07:
New reset code in latest HASP release v0.35

Closed 2019-02-07.

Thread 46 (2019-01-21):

EU version

zdar, 2019-01-21:
Hi,
I'm trying to develop a version which fits into EU style box (68mm diameter) for 2.4" LCD.

For those interested  - current version of PCB can be found here: https://easyeda.com/zdar/d1-power-board

At this moment I have prototype PCB assembled and I'm waiting for the LCD to test everything.
Unfortunatelly the HMI LCD is a bit too big so regular switch front frame and plate will need adjustment (Logus90 in my case).

The design uses power source (the break out part of PCB - simply snap it off by pliers) perpendicullary attached to the main board via solder bridge or angle pins. The LCD should go on top and hopefully it will fit into regular plastic frame with the inner fence trimmed off in apropriate parts.

Comments are welcome :-)

zdar, 2019-01-22:
Open the project at EasyEda and select "Switch version"
Note: It is completly untested with IRM-15-5 and it may be too deep for your box.

stijnbrattinga, 2019-02-17:
Did you already get the Nextion screens? Is everything fitting well into the wall box?  I live in The Netherlands and would like to start a build. Can I use your PCB design as is and just download the .gerber and send to JLCPCB, or do you recommend any additional modifications?

zdar, 2019-02-18:
> Did you already get the Nextion screens? Is everything fitting well into the wall box? I live in The Netherlands and would like to start a build. Can I use your PCB design as is and just download the .gerber and send to JLCPCB, or do you recommend any additional modifications?

I'm still waiting for my 2.4" display. Sofar I have assembled PCB and it fits in deep box (depth of 35 mm is needed when powerboard is attached).

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

stijnbrattinga, 2019-02-21:
Very nice! Looks great, I will order some PCB's!

zdar, 2019-02-21:
> Very nice! Looks great, I will order some PCB's!

Wait a few days :-)
I should pick up my nextion shortly (it is at post office) and I'll test everything togeather...

aderusha, 2019-02-22:
WOW!

stijnbrattinga, 2019-02-23:
Very cool, thanks for all the hard work @zdar ! I will order the parts and report back on my progress.

stijnbrattinga, 2019-03-22:
@zdar  Did you use the exact same parts for the rest of the projects? Like the 4pin header and grommet?

zdar, 2019-03-23:
> @zdar Did you use the exact same parts for the rest of the projects? Like the 4pin header and grommet?

No. My LCD is solded directly to PCB by short uninsulated wires. The LCD sits directly on PCB and solder pads on LCD&PCB should be aligned.

Originally I planned to use plastic spacers and nuts to hold LCD but at the end I just removed connector from LCD board, soldered wires on LCD board in place of connector, aligned LCD on PCB with wires going trough, soldered wires to PCB, did some testing and hot glued the LCD to PCB. That way I got lowest profile.

For the power lines make sure to use good 230V or better rated connector on power PCB. Insulate any exposed mains connected parts (for your own safety). If you want to be extra safe use shrink wrap/insulation tape over power board (do not over do it - the power supply needs cooling).

It all fits into wall box which itself provides secondary (mechanical) protection. Keep it mind that it has to be installed according to your local code and it is intended for permanent installation (not to be opened by user).

If you do not install it into the wall then you need a compliant box. These boxes shall come with proper grommit/cable gland a there has to be strain relief on the cable to prevent cable beeing pulled out and wires exposed.

Warning - this project is connected to the mains. It should be only done by person with proper qualification. There is serious risk of injury (the same applies to orginial US version).

marrobHD, 2019-06-14:
Were can I buy it?

Misiu, 2019-11-18:
@zdar did you use nextion LCD? or maybe other types could be used?

aderusha, 2019-11-18:
> @zdar did you use nextion LCD? or maybe other types could be used?

The HASP project fundamentally relies on the Nextion command protocol, so unless another LCD panel also supports that protocol, you're stuck with Nextion or TJC.  [There have been reports of people swapping out the display panel on an existing Nextion board](https://unofficialnextion.com/t/9-500nit-screen-on-7-nextion-enhanced-board/331) to utilize larger or brighter displays.

rexkani, 2020-04-02:
Hi, may i know why is this L shaped designed needed for EU boxes? i guess the original design give a slimmer profile for the whole thing? with only the thickness of the IRM-03-05 module?

but this L shape will make the whole thing digging deeper into the box with the length of the IRM-03-05 module?

I'm going to try installing HAswitchplate to our UK boxes and i'm also worried about fitting the whole thing into the box, appreciate if you could share more experiences here.

Thanks!

zdar, 2020-04-02:
> Hi, may i know why is this L shaped designed needed for EU boxes? i guess the original design give a slimmer profile for the whole thing? with only the thickness of the IRM-03-05 module?
> but this L shape will make the whole thing digging deeper into the box with the length of the IRM-03-05 module?

It is not exactly mandatory :-) But there were several reasons for this design. The biggest constrain was simply that there is not enough space in round 68 mm diameter box used on continent (screw distance 60 mm). It is impossible to fit D1 mini and power supply safely there on one board. That means a second board or separate supply had to be used.

I have opted for L shape design for two reasons:
- I did not want to have connecting wires and two separate units in the box
- It reduced depth of assembly a bit.

This construction resulted in 35 mm of depth needed  which fits into commonly used deeper variant of installation wall boxes.

Anyway, you do not need to use L shape construction. You can simply keep the power board separated (and have it parallel to main board or elsewhere) or not use it at all.

I believe that UK you have square boxes which gives you more space. You can probably stick IRM-03-05 somewhere to the corner without any problem which will reduce overall height.

My recommendation - if you have the option install as deep wall box as possible (UK  ?47 mm deep). That way you will have some space for the wiring,...

Note: I do not recommend having power supply on the front PCB (or similary exposed) as it poses risk having live mains lines in place where somebody could touch them after removal of front plate.

rexkani, 2020-04-08:
Thanks for you information, i guess i could try with the original PCB
first, and if it doesnt fit to the UK box, then i will try on your design.

As i'm living in an apartment and i have asked workers to drill deeper
space for boxes during renovation, i guess it should be easier for me.

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

socialstijn, 2020-07-21:
My soldering connection (Power to PCB and Screen to PCB keep breaking. Any tips on making a small and strong connection from screen to the pcb?

aderusha, 2022-09-06:
Closing as this repo is not being maintained.  [Check here for the updated project](https://github.com/HASwitchPlate/HASPone)!

Closed 2022-09-06.

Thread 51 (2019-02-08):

Temperature sensor

spiddder, 2019-02-08:
Are you planning to integrate a DHT22  sensor into your firmware?

aderusha, 2019-02-10:
HASP is intended to be a control surface as opposed to an all-in-one hub, and I don't know how having a temperature sensor mounted inside the device is going to tell anyone anything useful.  I'd think you'd be far better served hooking a temperature sensor to a device that's not inside of your wall (and thus exposed to the room temperature), and then sending that data out via MQTT, where you can then display that info on the HASP.  Does that make sense?  Am I misunderstanding the question or your use case?

spiddder, 2019-02-11:
I thought it could be used as a thermostat if there was a temperature sensor in it. There was only one idea about me. Maybe someone else would like it.
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

aderusha, 2019-02-11:
That actually makes a bit of sense.  Let me stew on this a bit, thanks for the idea!

aderusha, 2019-06-11:
Still think is is really cool but also out of scope of the HASP project itself. Closing issue.

Closed 2019-06-11.

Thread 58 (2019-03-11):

Bluetooth presence detection

penright, 2019-03-11:
Feature Request:

[This link is an example of someone using esp32 and mqtt.](https://community.home-assistant.io/t/esp32-based-ble-tracking-for-mqtt-room/71309)

[This link is an example of someone using a pi-zero, this has some algorithms that might come in handy.](https://community.home-assistant.io/t/presence-detection-ble-mi-flora-rf-gateway-with-esp32-openmqttgateway-is-now-compatible/37577)

I thought I would start this here so it does not get lost in the main thread, and I am interested in helping code it.
I have a dozen esp8266 but no esp32 yet. I have one ordered, once I get it, I will try and get a hello world running. Then we can see more what is involved.

aderusha, 2019-03-25:
I think the major challenge is going to be making an ESP32 board fit into the existing WEMOS D1 Mini footprint.  There is a D1 mini-like ESP32 which is pin compatible but it's too wide for the PCB.

penright, 2019-03-25:
When I posted the FR I did not notice the size difference of the ESP8286 mini vs the ESP32.
I see what you mean. I do have the board I order from you now. I also had a B114R (old work box) laying around, and the current .STL files will not fit in it, little on making it bigger. My house has all new workboxes, so I am sure it will fit them.
I do have one of the ESP32 on order and I am waiting on the slow boat.  Still learning. (a lot). :-)

To be honest, I am not sure if it will help or not. Right now for presence detection, I am using the google maps. For some reason, in the middle of the night, it will drift far enough that it triggers a "not home". I try adding nmap, the problem is leaving takes too long to trigger the "leave home". Comparing nmap to google map, arriving is pretty close, leaving is sometimes up to 10 minutes. I know there are settings, but I am trying to save batteries.

aderusha, 2019-06-11:
Closing issue as it pertains to ESP32, not used in this project.

Closed 2019-06-11.

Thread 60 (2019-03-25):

"No matching function for call to HTTPClient::begin(WiFiClient&, String&)"

petergreis, 2019-03-25:
Arduino IDE version 1.8.9 on MacOS

Could we get a list of the required libraries (and versions)? I am getting various compiler errors (like the one above), and also a complaint about MDNS.

Second question - can the binary be downloaded to the board directly from the IDE? I don't see a way to do this...

aderusha, 2019-03-25:
Good call.  I've updated [the documentation page](https://github.com/aderusha/HASwitchPlate/blob/master/Documentation/01_Arduino_Sketch.md#arduino-ide) to call out specific versions of the board manager and libraries in use.  I've just tested this in a clean 1.8.9 using the instructions provided and the project compiles without errors.

The documentation also covers using NodeMCU Flasher for writing the binary directly but that's a Windows-only tool.  I don't have a Mac with which to test MacOS binaries but a google search suggests there are several options available.  [This command line tool from Espressif](https://github.com/espressif/esptool) seems like a good starting point.

petergreis, 2019-03-25:
Hi Allen

OK, flashing with esptool.py does the trick. But after updating my WiFi and MQTT settings, the screen simply displays

WiFi Connected: 192.168.1.205
MQTT Connected: 192.168.1.201

How does it move to the next screen? Is there something that I need to do?

Best regards

Peter

From: Allen Derusha <notifications@github.com>
Reply-To: aderusha/HASwitchPlate <reply@reply.github.com>
Date: Monday, 25 March 2019 at 14:22
To: aderusha/HASwitchPlate <HASwitchPlate@noreply.github.com>
Cc: Peter Greis <peter.greis@freethinker.com>, Author <author@noreply.github.com>
Subject: Re: [aderusha/HASwitchPlate] "No matching function for call to HTTPClient::begin(WiFiClient&, String&)" (#60)

Good call. I've updated the documentation page<https://github.com/aderusha/HASwitchPlate/blob/master/Documentation/01_Arduino_Sketch.md#arduino-ide> to call out specific versions of the board manager and libraries in use. I've just tested this in a clean 1.8.9 using the instructions provided and the project compiles without errors.

The documentation also covers using NodeMCU Flasher for writing the binary directly but that's a Windows-only tool. I don't have a Mac with which to test MacOS binaries but a google search suggests there are several options available. This command line tool from Espressif<https://github.com/espressif/esptool> seems like a good starting point.

—
You are receiving this because you authored the thread.
Reply to this email directly, view it on GitHub<https://github.com/aderusha/HASwitchPlate/issues/60#issuecomment-476193952>, or mute the thread<https://github.com/notifications/unsubscribe-auth/AEI0pygZuHZhQaiSgv9-Wvvj70U2K9MTks5vaM2cgaJpZM4cGxr7>.

aderusha, 2019-03-25:
You'll then need to proceed through the rest of the documentation to setup Home Assistant.  If you have everything physically hooked up (which is sounds like you do), you can probably jump to [step 5 in the documentation](https://github.com/aderusha/HASwitchPlate/blob/master/Documentation/05_Home_Assistant.md).

petergreis, 2019-03-25:
But what if I am not using home assistant? I use homebridge and an MQTT Broker, eventually driving everything with Apple Home and Siri.

Best regards

P

On Mar 25, 2019, at 17:13, Allen Derusha <notifications@github.com<mailto:notifications@github.com>> wrote:

You'll then need to proceed through the rest of the documentation to setup Home Assistant. If you have everything physically hooked up (which is sounds like you do), you can probably jump to step 5 in the documentation<https://github.com/aderusha/HASwitchPlate/blob/master/Documentation/05_Home_Assistant.md>.

—
You are receiving this because you authored the thread.
Reply to this email directly, view it on GitHub<https://github.com/aderusha/HASwitchPlate/issues/60#issuecomment-476268545>, or mute the thread<https://github.com/notifications/unsubscribe-auth/AEI0p53FtXsZqwv95BdsYNKDN9eKQt_yks5vaPWQgaJpZM4cGxr7>.

aderusha, 2019-03-25:
This project includes pre-canned automations for Home Assistant and OpenHAB.  If you aren't going to be using one of those two options, you'll need to build out your own solution for your own environment from scratch.  [The MQTT namespace is outlined here](https://github.com/aderusha/HASwitchPlate/blob/master/Documentation/06_MQTT_Control.md), but understand this is going to be a substantial undertaking.

petergreis, 2019-03-25:
I am ready to do that... was planning on mapping actions through NodeRed. My question is, should it boot fully into the screens with the buttons, or is it waiting to contact a home assistant server?

On Mar 25, 2019, at 19:17, Allen Derusha <notifications@github.com<mailto:notifications@github.com>> wrote:

This project includes pre-canned automations for Home Assistant and OpenHAB. If you aren't going to be using one of those two options, you'll need to build out your own solution for your own environment from scratch. The MQTT namespace is outlined here<https://github.com/aderusha/HASwitchPlate/blob/master/Documentation/06_MQTT_Control.md>, but understand this is going to be a substantial undertaking.

—
You are receiving this because you authored the thread.
Reply to this email directly, view it on GitHub<https://github.com/aderusha/HASwitchPlate/issues/60#issuecomment-476318925>, or mute the thread<https://github.com/notifications/unsubscribe-auth/AEI0p83GBrtki0Vq6OLW3Cd_FYVpukLKks5vaRLOgaJpZM4cGxr7>.

aderusha, 2019-03-25:
It's waiting on page 0 to be told what to do.  You can tell it to switch pages using the MQTT commands outlined in that document.  If you check the Home Assistant forums you'll find some users have been working on this.  [This user](https://community.home-assistant.io/t/ha-switchplate-diy-lcd-touchscreen-wall-switch-replacement/25464/983) posted his NR flows [here](https://hastebin.com/mayuyegufa.json).

petergreis, 2019-03-27:
Allen

Thank you so much 😊
I now have a 2.4 and 7” version running.

What I did find odd - adding a slider (as p[1]h[0] comes over MQTT as b[2], not h[0]. Is this the expected behavior?

Best regards

Peter

[image1.jpeg]

On Mar 25, 2019, at 19:26, Allen Derusha <notifications@github.com<mailto:notifications@github.com>> wrote:

It's waiting on page 0 to be told what to do. You can tell it to switch pages using the MQTT commands outlined in that document. If you check the Home Assistant forums you'll find some users have been working on this. This user<https://community.home-assistant.io/t/ha-switchplate-diy-lcd-touchscreen-wall-switch-replacement/25464/983> posted his NR flows here<https://hastebin.com/mayuyegufa.json>.

—
You are receiving this because you authored the thread.
Reply to this email directly, view it on GitHub<https://github.com/aderusha/HASwitchPlate/issues/60#issuecomment-476322151>, or mute the thread<https://github.com/notifications/unsubscribe-auth/AEI0p1QImHBME-eJSRSzJv6tRhpAJEMNks5vaRTCgaJpZM4cGxr7>.

aderusha, 2019-03-27:
> Allen Thank you so much 😊 I now have a 2.4 and 7” version running. What I did find odd - adding a slider (as p[1]h[0] comes over MQTT as b[2], not h[0]. Is this the expected behavior?

It is, [check out the documentation here](https://github.com/aderusha/HASwitchPlate/blob/master/Documentation/06_MQTT_Control.md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) for an explanation of what is going on.

Closed 2019-03-25.

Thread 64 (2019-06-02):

Compile Error - Software Serial - use of deleted function

FritzTheCatfish, 2019-06-02:
This is the Error:

HASwitchPlate-master\Arduino_Sketch\HASwitchPlate\HASwitchPlate.ino:

In function 'void debugPrintln(String)':

HASwitchPlate:2506:54: error: use of deleted function 'SoftwareSerial::SoftwareSerial(const SoftwareSerial&)'

     SoftwareSerial debugSerial = SoftwareSerial(17, 1); // 17==nc for RX, 1==TX pin

                                                      ^
Environment is:
Windows 10
Arduino 1.8.9 (Windows Store 1.8.21.0)

Libraries:
Esp8266 2.5.2
ArduinoJson 5.13.5
MQTT 2.4.3
WifiManager 0.14.0

No modifications were made to the file.
Any suggestions?

FritzTheCatfish, 2019-06-02:
BTW what esp8266 version was used? If I change version i.e. 2.5.0 I get an MDNS error

aderusha, 2019-06-11:
Fix is sorted out and coming in 0.38

aderusha, 2019-06-12:
HASP v0.38 has been published which resolves this issue.  HASP now uses the latest version of ArduinoJSON 6.x, and the Arduino build instructions have been updated to match.

Closed 2019-06-12.

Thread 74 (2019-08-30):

FR: Adjust switchplate model to address LCD Backlight light leakage

mattster98, 2019-08-30:
Just for tracking purposes at this point.  I bought mine pre-printed so I haven't tried to edit the model yet.  Noticed under low light that some backlight leaks through the front plastic of the cover plate (at the bottom, see pic below).  Hoping just some additional thickness will help and shouldn't break the clearances required for proper fit.

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

mattster98, 2019-09-01:
I might just add some black electrical tape or some other opaque material to the inside bottom - not sure how much clearance there is but it'll likely have to be a lot thicker in order to block all the light.

I printed a test piece with 1mm thickness instead of the 0.7mm and it wasn't significantly more opaque.. thicker than that and it'll start to look too thick, I think.

Closed 2019-09-01.

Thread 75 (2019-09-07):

Fitting into old work electrical box

osbash, 2019-09-07:
Has anyone been able to edit the 3D files to allow the back piece to fit into an old work electrical box?  Something like this:  https://www.homedepot.com/p/Carlon-1-Gang-Old-Work-PVC-Electrical-Box-with-Clamp-Case-of-25-B114RR-UPC/205338594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

The inner height is just under 2.9"

aderusha, 2019-09-08:
I created a [minimum clearance rear  enclosure](https://github.com/aderusha/HASwitchPlate/blob/master/3D_Printable_Models/HASwitchPlate_rear_lcdmod_minimum_clearance.stl) that you might be able to use.  It is a little flimsy, needs supports to print, and generally isn't as nice as the normal rear enclosure, but it has every bit of non-essential geometry stripped to the bone so it is as small as I could make it for tight work boxes.

osbash, 2019-09-09:
Thanks for the response.  After looking into it a bit more, I noticed the Nextion itself is about 1mm taller than the work box, so it wouldn't work even if I were to reduce enclosure to fit.  I don't have any spots to install the switch plate so I need to add one of these work boxes into existing drywall.

My only other option is to create a 3d printed workbox to work like the one linked above and fix the enclosure.

Closed 2019-09-09.

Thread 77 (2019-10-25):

Payload Problems: txt with ""

MadNBG, 2019-10-25:
Hi,
I'm a newbie. And I've got a Problem.
My home sends as payload 22.3 (i.e. for temperature in °C).
The hasp wants a txt-payload like "22.3" (with quotationmarks).
I use fhem (fhem.de) as home-server.

I cannot bring the marks in the payload. My scripting has a Problem with " in between "" of a command.

Is there a chance, that you build in a check on those Inputs and add the ""-marks?

I like this Project, and hope I'll get this (big) Problem solved.

Kind regards from Baden, GER
MadNBG

aderusha, 2020-01-15:
You should be able to escape a " with a preceding \

Closed 2020-01-15.

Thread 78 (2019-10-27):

Control without MQTT?

m14t, 2019-10-27:
### Question
Is it possible to adjust the backlight level when the MQTT server is unavailable?

### Back story

I live in CA and am effected by the fire preventive power shutoffs.  When this is scheduled, I proactively power down a bunch of things, like the MQTT server that my HASwitchPlate connects to in order to save the UPS it's connected to for other things.

However, when this happens, the HASwitchPlate displays the wifi information and sets the backlight to what looks like 100%.  This plate is in our bedroom and so ideally we would be able to control/dim this backlight.

--

Thanks again for all the work here!  This is one of the first things I look at every morning.  I love it.

petergreis, 2019-10-28:
In the pre-initialize for my 7” panel I have the following:

thup=1

thsp=120

This blanks the panel after 120 seconds of no input. The first touch thereafter turns the panel back on, the next touch is passed on normally. Perhaps this would help you?

From: Matt Farmer <notifications@github.com>
Reply to: aderusha/HASwitchPlate <reply@reply.github.com>
Date: Sunday, 27 October 2019 at 03:44
To: aderusha/HASwitchPlate <HASwitchPlate@noreply.github.com>
Cc: Subscribed <subscribed@noreply.github.com>
Subject: [aderusha/HASwitchPlate] Control without MQTT? (#78)

Question

Is it possible to adjust the backlight level when the MQTT server is unavailable?

Back story

I live in CA and am effected by the fire preventive power shutoffs. When this is scheduled, I proactively power down a bunch of things, like the MQTT server that my HASwitchPlate connects to in order to save the UPS it's connected to for other things.

However, when this happens, the HASwitchPlate displays the wifi information and sets the backlight to what looks like 100%. This plate is in our bedroom and so ideally we would be able to control/dim this backlight.

--

Thanks again for all the work here! This is one of the first things I look at every morning. I love it.

—
You are receiving this because you are subscribed to this thread.
Reply to this email directly, view it on GitHub<https://github.com/aderusha/HASwitchPlate/issues/78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>, or unsubscribe<https://github.com/notifications/unsubscribe-auth/ABBDJJ4XFUY232XXXU52LJ3QQT6BRANCNFSM4JFPYEMQ>.

aderusha, 2020-02-13:
The comment above shows one way to deal with the specific nature of the issue raised.  Also, the ask for "control without MQTT" is now fulfilled via telnet.  The telnet client allows you to send commands to the Nextion panel without MQTT being active.

Thoky81, 2020-08-10:
@petergreis Hi, can you please explain where to put thup=1 thsp=120 in nextion editor? I have done something but the display dont want to sleep - just restart. Plus, when I tried to simulate it on nextion, it was working no issue. Thanks

petergreis, 2020-08-11:
Certainly, it goes in the Preinitialize Event. For example, I have this:

bauds=115200

vis 3,0

thup=1

thsp=120

sendme

best regards

Peter

From: Thoky81 <notifications@github.com>
Reply to: aderusha/HASwitchPlate <reply@reply.github.com>
Date: Monday, 10 August 2020 at 22:17
To: aderusha/HASwitchPlate <HASwitchPlate@noreply.github.com>
Cc: Peter Greis <peter.greis@freethinker.com>, Mention <mention@noreply.github.com>
Subject: Re: [aderusha/HASwitchPlate] Control without MQTT? (#78)

@petergreis<https://github.com/petergreis> Hi, can you please explain where to put thup=1 thsp=120 in nextion editor? I have done something but the display dont want to sleep - just restart. Plus, when I tried to simulate it on nextion, it was working no issue. Thanks

—
You are receiving this because you were mentioned.
Reply to this email directly, view it on GitHub<https://github.com/aderusha/HASwitchPlate/issues/78#issuecomment-671566723>, or unsubscribe<https://github.com/notifications/unsubscribe-auth/ABBDJJ7756OB6SRK457QIM3SABIT3ANCNFSM4JFPYEMQ>.

Thoky81, 2020-08-11:
@petergreis Thanks its working now.

Closed 2020-02-13.

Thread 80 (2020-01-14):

Not Initializing

Erdcgh, 2020-01-14:
My screen is just stuck on "HASP Not Initializing......."

I have installed the HASwitchPlate.ino.d1_mini.bin onto the D1 mini and have it connected up to the HASP PCB.

I have tried to unplug the D1 mini and just power it up alone and see if I could see an Access Point, but I don't  see any. If it was possible to do so.

UPDATE:
I see that it is already connected to my WIFI. I have logged into its web page, updated the firmware and set up the MQTT broker. I do see MQTT messages being sent by it. But I still just have the "HASP Initializing......." that is being shown on the screen

aderusha, 2020-01-15:
That strongly suggests that TX from the PCB is not making it to RX on your Nextion.  Check your soldering joints and if you have a multimeter you can check continuity to make sure there's a path from D4 on the WeMos to the RX pad (usually the yellow wire) on your Nextion.

Erdcgh, 2020-01-15:
Thanks, That did it. The D1 mini actually had a cold solder joint on it.

Closed 2020-01-15.

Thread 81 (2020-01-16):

HASP Time not correct since upgrading to HA .104

rlust, 2020-01-16:
The displayed time on all of my panels are running several minutes slow since HA upgrade to V .104.

aderusha, 2020-01-16:
Is the time set correctly on your HA system?  An HA automation is triggered every minute which sends the current time to HASP.  The HASP understands nothing about time, it's just displaying what HA tells it.  If HA has the wrong time, then that's what it sends to the HASP.

rlust, 2020-01-17:
HA time is correct, I was just looking at all of the MQTT hasp messages.
Very few and very slow to update. Everything was fine prior to HA update to .104 and now .104.1.
MQTT server is fine and no issues with other device types using MQTT.

aderusha, 2020-01-17:
So for some reason Home Assistant isn't sending the messages on time, this is going to require troubleshooting your Home Assistant installation to determine why automations using the Time trigger aren't firing on time.

rlust, 2020-01-17:
OK Found the issue. I added more memory to the HA VM. It was maxing out as was the Swap area. I added memory and so far all is well.
Glances was very helpful in finding the issue.
Thanks for the help!

Closed 2020-01-17.

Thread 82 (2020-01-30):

Adding diferent component to Swichplate

CsepregiArtur, 2020-01-30:
Hello

Would it be possible to add different components (temp sensor, relay) to the switch plate?
I'm not referring to if there is space, I'm referring software side, and I need then to rewrite the software? Or it will wor with the actual one?

aderusha, 2020-01-30:
Currently the Arduino code has support for a motion sensor on D1 or D2.  Adding any other sort of sensor would require modification to the Arudino project.

Closed 2020-02-13.

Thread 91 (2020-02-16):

Three-gang plate with HASP in the middle

aph3rson, 2020-02-16:
At the moment, there's only one option for a three-gang plate with an HASP module - mounting it on the side.

In some instances, it may be more desirable to have it in the middle - case in point, I have two ZEN22's I'd be mounting it next to, which can't be mounted next to each other (heat dissipation issues). Therefore, putting the HASP in the middle would be more practical and fits the aesthetic I'd be going for.

aph3rson, 2020-02-16:
For reference, here's the two models that I'm referring to: [three-gang Decora](3D_Printable_Models/HASwitchPlate_front_triple_hasp_decora_decora.stl), [three-gang toggle](3D_Printable_Models/HASwitchPlate_front_triple_hasp_toggle_toggle.stl).

aderusha, 2020-02-29:
You make a compelling argument.  [Currently available in dev branch](https://github.com/aderusha/HASwitchPlate/blob/dev/3D_Printable_Models/HASwitchPlate_front_3x_decora_hasp_decora.stl), should hit master "soon".

Closed 2020-03-24.

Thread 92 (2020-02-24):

Uploading firmware or TFT to nextion display

jaygrovr, 2020-02-24:
I bought a nextion display from amazon and the part number is NX3224T024_011, and when i try to update the firmware on the device, I get the following message "model does not match Device model: NX3224T024_011R".  What am I doing wrong?  This part number seems to match what your readme file describes,.

aderusha, 2020-02-24:
How are you handling the update?  SD card? Serial through HASP?  Any screenshots of what you're seeing?  Can you provide a link to the device you bought?

jaygrovr, 2020-02-24:
Sorry, doing the update using an SD card.. i formatted it as fat32, and the device recognizes the file, but for some reason doesnt allow it.  Here is the link for the screen https://www.amazon.com/gp/product/B015DMP45K/ref=ppx_yo_dt_b_asin_title_o00_s02?ie=UTF8&psc=1

it does say the exact part number on the PCB.,. without the R at the end..

aderusha, 2020-02-24:
Weird :(  There should only be two models of that device per the Wiki: https://nextion.tech/datasheets/nx3224t024/#2

One ending in "R" for resistive touchscreen, and one ending in "N" for no touch sensor.

Do you have a spare UART kicking around?  I wonder if loading up the Nextion editor and attempting to send the project that way would yield any different results or at least tell you more about what it thinks is happening.

jaygrovr, 2020-02-24:
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

aderusha, 2020-02-24:
Allright one more idea - can you show me the contents of the SD card?

jaygrovr, 2020-02-24:
i can try with a uart, but was hoping to not have to do that.  Could it possibly be not enough power for the screen?
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

aderusha, 2020-02-24:
That is the correct file for your display model.  Power problems can present themselves in all sorts of wacky ways but I've not seen it do this...

I'd have to default back to using the Nextion editor.  Once it connects it should identify your device and give you some options for the current project to make sure it matches your LCD.

jaygrovr, 2020-02-24:
ok so with a uart, i should be able to connect to the screen directly with the editor?

aderusha, 2020-02-25:
That's the idea I'm shooting for.  Take HASP out of the middle, let the Nextion software talk directly to the Nextion panel and see what it makes of the situation.

jaygrovr, 2020-02-27:
by the way I figured out my issue.  For some reason github wasnt downloading the correct file.  i was downloading some other file type.  Once I signed in, the files were much larger and now everything works.  Totally my mistake and I feel very dumb about it.
jason
    On Tuesday, February 25, 2020, 04:17:30 AM PST, Allen Derusha <notifications@github.com> wrote:

That's the idea I'm shooting for. Take HASP out of the middle, let the Nextion software talk directly to the Nextion panel and see what it makes of the situation.

—
You are receiving this because you authored the thread.
Reply to this email directly, view it on GitHub, or unsubscribe.

aderusha, 2020-02-28:
Hey brother glad you got it sorted!

thatoneprogram, 2021-09-19:
how am I supposed to get rid of this error

thatoneprogram, 2021-09-19:
I

thatoneprogram, 2021-09-19:
need

thatoneprogram, 2021-09-19:
help

aderusha, 2021-09-19:
Can you maybe help us out by explaining what you've done, what you expected, and what happened?

thatoneprogram, 2021-09-19:
nvmd i have done it

melazzab, 2021-12-27:
I have the same error but when trying to uplad the tft file via the the serial port using the **whmi-wri** instruction. The same file can be uploaded properly using the SDcard, so the version is normally correct. But when I try to appload it via serial port, I receive the first message back from the screen **(0x5)** meaning that it is ready to receive, then I send the first 4096 bytes of the file, then the screen shows the error : Model does not match

mohammedelazzab, 2021-12-27:
I have the same error but when trying to uplad the tft file via the the serial port using the whmi-wri instruction. The same file can be uploaded properly using the SDcard, so the version is normally correct. But when I try to appload it via serial port, I receive the first message back from the screen (0x5) meaning that it is ready to receive, then I send the first 4096 bytes of the file, then the screen shows the error : Model does not match.

The file is generated using Nextion Editor on windows, then I move it to a Linux machine connected to the nextion touchscreen 3.5" Basic.

aderusha, 2021-12-27:
Which version of the HASPone firmware are you running, and what serial speed to do have set?

melazzab, 2021-12-27:
I don't know what is the HASPone. Can you please explain what it is and how to get the version?
 I am using the Nextion NX4832T035_011R, which is a 3.5" Basic, with a baudrate of 9600, I can establish a communication with the screen and send commands etc with that baudrate, only the TFT upload that doesn't work.

simoelazzab, 2021-12-27:
don't know what is the HASPone. Can you please explain what it is and how to get the version?
I am using the Nextion NX4832T035_011R, which is a 3.5" Basic, with a baudrate of 9600, I can establish a communication with the screen and send commands etc with that baudrate, only the TFT upload that doesn't work.

aderusha, 2021-12-27:
Are you using the HASwitchPlate project?  This repo is no longer maintained and everything has moved over to the [HASPone repo](https://github.com/HASwitchPlate/HASPone).  If you stumbled into this looking for general Nextion help, maybe try the [Unofficial Nextion Forum](https://unofficialnextion.com/).

ageorgiev86, 2023-01-28:
what do we do if the model is correct.  because in this case it is exactly like that.  The model is correct, but it tells me that it does not match

henriquejsbraga, 2025-03-07:
I have the same problem. The model was selected correctly, but the display says it is wrong. My display model is NX3224T024_011R.

Closed 2020-03-19.

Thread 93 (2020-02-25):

Trouble compiling source

bgardner46, 2020-02-25:
I have an HASwitchPlate running on a breadboard, have printed the case, and am just waiting for PCBs from PCBWay which have been slightly delayed due to the virus problems over there. I am using it with my Homevision controller and an MQTT plugin and it works great. I definitely plan to build several of them. My only problem is that I would like to make some minor changes for my personal use but I have been unable to compile the source. I am using the Arduino IDE version 1.8.8 and the ESP8266 core version 2.5.0. I get numerous errors but they all seem to have this form:

HASwitchPlate:1595:24: error: 'HTTP_HEAD_END' was not declared in this scope

   httpMessage += FPSTR(HTTP_HEAD_END);

D:\Electronics\HASP\Arduino\HASwitchPlate\HASwitchPlate.ino: In function 'void webHandleSaveConfig()':

HASwitchPlate:1716:30: error: 'HTTP_HEAD' was not declared in this scope

   String httpMessage = FPSTR(HTTP_HEAD);

It's probably something simple but I'm stumped. Any suggestions would be greatly appreciated.

Thank you for an incredibly useful project.

Bob Gardner

aderusha, 2020-02-25:
That problem is due to a change in the WiFiManager library.  The next release of HASP will address this issue, but you can clear it up yourself by simply deleting the lines calling HTTP_HEAD_END (so, just delete or comment out the entire line `httpMessage += FPSTR(HTTP_HEAD_END);`).

bgardner46, 2020-02-25:
Well I tried commenting out all of those lines as well as others that were
causing errors but never got the source to compile. I even tried other
versions of the WiFi Manager library but was unsuccessful there as well.
I'm not really in a big hurry so at this point I will wait for your next
release.

Thanks again for releasing such a great project.

Bob

On Tue, Feb 25, 2020 at 4:16 AM Allen Derusha <notifications@github.com>
wrote:

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

bgardner46, 2020-02-25:
Cancel my last email. I tried one more time with a fresh version of the source and version 0.14 of the WiFiManager and the source compiled. Sorry for the confusion.
Thanks,
Bob

aderusha, 2020-02-28:
No worries.  The Arduino library system can make this difficult, glad you got it worked out.  The next release will be up-to-date vs all current libraries, but that will last for all of a day until something gets updates somewhere....

Closed 2020-02-28.

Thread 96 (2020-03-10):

Setting Nextion attributes

bgardner46, 2020-03-10:
Greetings,
I'm not sure this is the correct place to put this so please tell me if there is somewhere else to post.
I am building an HASwitchPlate but using it with my Homevision home control system not Home Assistant. It has been going well but I was having trouble with sending some MQTT commands to set or change attributes on the nextion display from my system. For example I can send:
hasp/disp01/command/page 1
and page 1 is sent to the display and it changes as it should
however when I send:
hasp/disp01/command/picq 0,0,120,120,1
picq=0,0,120,120,1 is sent to the display and I get an error since the display doesn't want the = sign.
I went into the ESP8266 source and changed the following lines as shown here by replacing the = sign with a space.

`void nextionSetAttr(String hmiAttribute, String hmiValue)
{ // Set the value of a Nextion component attribute
  Serial1.print(hmiAttribute);
  Serial1.print(" "); // was "="
  Serial1.print(utf8ascii(hmiValue));
  Serial1.write(nextionSuffix, sizeof(nextionSuffix));
  debugPrintln(String(F("HMI OUT: '")) + hmiAttribute + " " + hmiValue + "'");```

This works for now but I don't know if this will affect anything else or if I'm doing something incorrectly. Can you provide me some insight?
Thanks,
Bob Gardner

aderusha, 2020-03-11:
What you're looking to do is send a command, not set an attribute.  The modification you've made to `nextionSetAttr()` is going to cause problems for you down the road and I'd recommend switching it back, as you'll have broken the ability to send attribute changes.

To run Nextion commands that have arguments, you'll want to send a message like this:

**Topic:** `hasp/disp01/command`
**Message:** `picq 0,0,120,120,1`

aderusha, 2020-03-11:
As a side note - very interested to hear about your progress with getting HASP to work with HomeVision!  If you want to drop in on [our Discord channel](https://discordapp.com/invite/c5DvZ4e) I might be able to field questions interactively as they come up and would love to help out where possible.

bgardner46, 2020-03-11:
Thanks for the quick response. I switched the Wemos software back to the
original form and I changed the way I was sending the message from
Homevision and it worked just fine. From Homevision I send a serial command
which is captured by an MQTT plugin written by one of the Homevision users
which is written in TCL. The original purpose of the plugin was to work
with Sonoff and Shelly devices that had been flashed with Tasmota software.
The command has this format:

mqtt: pub hasp/disp01/command picq 0,0,120,120,1;

This worked great. I also wrote another plugin that captures the published
messages from the hasp and performs the associated actions in Homevision.
When I'm all done I'll put together a page on my web site that has all of
the details and share it with you and our Homevision users.

I will also pop over to the discord channel since I have  few other
questions about 3D printing the enclosures.

Bob

On Wed, Mar 11, 2020 at 4:50 AM Allen Derusha <notifications@github.com>
wrote:

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

Closed 2020-03-12.

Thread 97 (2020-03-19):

group depreciated

mcfarlde, 2020-03-19:
Hassio 107 depreciated groups which is used extensively in the HASP demo configuration.

aderusha, 2020-03-19:
Groups haven't been deprecated entirely, but much of the functionality we had been using has been removed.  The current `master` branch of the project does not include and of the group capability that has been removed and loads on 107 without problem.

If you have an existing installation, a script was created to migrate your existing HASP installations to work with 107.

```bash
bash <(wget -qO- -o /dev/null https://raw.githubusercontent.com/aderusha/HASwitchPlate/master/Home_Assistant/migrate-hasp-107.sh.sh)
```

Finally, the `dev` branch contains the current codebase being developed for better Lovelace compatibility.  [See here](https://community.home-assistant.io/t/ha-switchplate-diy-lcd-touchscreen-wall-switch-replacement/25464/1369) for details on how to test that.

marc-gist, 2020-03-24:
Did something break/change in 0.107.5? as I get a blank page when I click on the "plate01" from the left bar (don't have a "plate01" tab on lovelace).
Thanks!

aderusha, 2020-03-24:
The link to the left is an iframe, which is opening the web interface on your HASP directly and presenting it in a frame.  It relies on MDNS working in your environment to turn "plate01.local" into the IP address of your HASP.  If for whatever reason your desktop can't resolve that address, then that frame won't work.

If you have the IP address of your HASP you should be able to type the address in directly to a web browser and access the same interface.

aderusha, 2020-03-29:
Closed, all compatibility fixes are now in the `master` branch.

Closed 2020-03-29.

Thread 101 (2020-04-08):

Splitting up the code into classes

gztproject, 2020-04-08:
Hi, I've been working on creating a PlatformIO version of the ESP firmware, would you be interested in including that in your repo?

aderusha, 2020-04-08:
This is all developed in PlatformIO and the project should be directly portable with no code changes, just drag the .ino into `./src`, pull in your libraries, and it will build.

gztproject, 2020-04-08:
Thanks for quick response.
I had some problems with function declarations but that might be an error on my part renaming it to .cpp

In any case, what I had in mind (and failed to properly explain) is splitting the code in classes as it might simplify it a bit and make the main file more readable. I will probably do it in my fork anyway, and see how it turns out :)

aderusha, 2020-04-08:
Sounds good.  I'm keeping the codebase Arduino IDE-native because I feel like that's the lowest-friction option for new users, but personally I can't stand working in that environment :D

Splitting up the code into classes is something that I should have done from the get-go, and we are now where we are due to years of accumulated features and me being a lousy programmer.  If you want to take a swing at this, please do!

SittingDuc, 2020-12-06:
Hello.

I have forked your project to add some features I want (mostly more pages despite Nextion's limitations) and along the way I am going to try to break the .ino apart into C++ classes and use PlatformIO too because I like the environment better.

Since it is not fair to keep changes to myself, I have tried to make my code less ugly than usual and started uploading it to GitHub.

So far I have a separate class for all the Nextion accesses, and a separate class for all the debugPrintln. I still want to separate MQTT, Webserver and Telnet into more classes.

Since I am walking into your project and tearing it all to pieces on my fork, I thought at the least I should say Hello. You are welcome to have a look at my fork and let me know how you feel. If I have "the right end of the stick", if there are small things I can do differently that would make the class-separating-work more useful to you; if there is anything I can usefully do to make the HASP project better.

Thanks!,

aderusha, 2022-09-06:
Closing as this repo is not being maintained.  [Check here for the updated project](https://github.com/HASwitchPlate/HASPone)!

Closed 2022-09-06.

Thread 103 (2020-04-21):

Disconnecting issues

jhhernan, 2020-04-21:
Hi. First of all: Congratulations! Great job, its a very useful proyect.
I updated to the last version but I`ve been noticing some disconnections. What can I check?
I have another HASwitchPlate with the older verson and it`s working OK.

aderusha, 2020-05-20:
For testing purposes you can revert to an older firmware if you think that's the issue.  Is there any chance the issue is RF signal related?  Can you maybe swap the location of the two devices?

aderusha, 2020-12-19:
Closing after no update from submitter

Closed 2020-12-19.

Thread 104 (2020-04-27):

Include the adc channel to the mqtt protocol

miloit, 2020-04-27:
Might it be possible to include the adc channel to the protocol in one of the next versions so that someone who is interested can maybe read out the supply voltage by putting 180(= max. 5V)/280 (=max. 6V)kohm between a0 pin and supply voltage?

miloit, 2020-05-15:
Combined with issue #106

Closed 2020-05-15.

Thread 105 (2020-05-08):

HAswitchplate forgetting settings

scubieman, 2020-05-08:
Having issues with the HASwitchplate forgetting settings, Like the wifi network and MQTT devices. With this happening it wont grab the yaml and update. Any ideas what i did wrong?

aderusha, 2020-05-08:
What process did you use for flashing the device originally?

scubieman, 2020-05-08:
I used Tasmotizer to flash, and used your bin file to update it. Seems ok i guess for now. I will close this and reopen if i run into another issue. Any way to chat via discord or something?

Closed 2020-05-08.

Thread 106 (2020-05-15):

Include all Open Digital and analog IO to configuration and MQTT protocol

miloit, 2020-05-15:
Hello,
Might it be possible that you can add all open I/O of the Wemos to the mqtt protocol and can they be configured via website to
-input
-output
-dht sensor protocol

So you can individually use the hasp for other purposes as well.

Thanks

PaulG4H, 2020-06-22:
Hello,
if you are searching for an universal Firmware for ESP which is configurable over web and support a lot of devices OOTB maybe ESPEasy or Tasmota is the way you want to go.

kquinsland, 2020-10-17:
@miloit It's relatively easy to add your own code to publish the value of the `A0` pin to MQTT.
[I added a LDR (and neopixels) to the HASP](https://karlquinsland.com/2020/10/enhanced-home-assistant-switch-plate-hasp/) to check the ambient light level in the room where the HASP is deployed.

You can see the code that publishes the LDR value here:

https://github.com/kquinsland/HASwitchPlate/blob/add-neopixels/Arduino_Sketch/HASwitchPlate/HASwitchPlate.ino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

But if you're looking for more 'generic' sensor support, Tasmota and ESPHome are much better alternatives!

aderusha, 2022-09-06:
Closing as this repo is not being maintained.  [Check here for the updated project](https://github.com/HASwitchPlate/HASPone)!

Closed 2022-09-06.

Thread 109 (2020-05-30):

no power issues

xHirscHx, 2020-05-30:
So i built 2 of these and using all the build materials for the list. When i power it with ac the wemo does not power on. If i plug in usb to wemo it powers up but no screen  ( no 5v as expected).
I have 120v to power supply lugs and 5v to the 5v lugs but not to wemo 5v or 3v.

aderusha, 2020-05-30:
Can you post pictures?  Are you using the PCB or protoboard?  In general, I'd advise tracing the path of 5V and see where it stops working.  If you have 5V at the PSU, do you also have 5V at the 5V pin to the WeMos?  If not, can you do a continuity test and see why that is?

xHirscHx, 2020-05-30:
im using the pcb board hasp  from the link. have continuity from 5v power supply to both pins wemo and the pin to the right on pcb.  It seems its a ground issue but i no nothing about this power supply form ac to 12v.

aderusha, 2020-05-30:
Any chance of a soldering issue on the 5V or GND pins on the WeMos?  Can you check your joints on the Wemos pin headers and also on the HASP board?

The Wemos has a 5V to 3.3V regulator on board.  5V from the USB or from that 5V pin both go to that regulator which then powers the board.  So, if it works from USB, that means that the regulator is working and the board is working.  This leaves getting 5V to that regulator, which must be your problem.

xHirscHx, 2020-05-30:
definitely could be a sodering issues i did my best non are touching but it ant pritty LOL

aderusha, 2020-05-30:
Visually I don't see anything overtly wrong, but the solder joints here aren't great and it's very possible that they aren't making contact where you'd hope they would.  I'd suggest some solder braid + flux to clean things up a bit.  Also, check continuity from +5V on the top of the Wemos board to +5V on the PSU.  Also check GND to GND, and also confirm there is no continuity between +5V and GND.

xHirscHx, 2020-05-30:
No continuity from gnd to gnd. 5v to 5v is fine

xHirscHx, 2020-05-30:
I have ground from psu to the header pins on the right but no ground at the wemo pin

aderusha, 2020-05-30:
That leaves GND at Wemos to it's header pins (on top) or the GND from wemos header pin to the PCB itself on the bottom.  If you have solder flux (not plumbing flux, stuff for electronics), soak those joints and hit it with some heat.

xHirscHx, 2020-05-30:
no joy. will it hurt anything if i conect the  2 gnds with a jumper and leave it

xHirscHx, 2020-05-30:
Funny i have 2 boards that are doing this

aderusha, 2020-05-30:
A jumper from PSU GND to Wemos GND is OK.

xHirscHx, 2020-05-30:
soldered  a jumper No fire no smoke all good booting up.
thx for your help,

Closed 2020-05-30.

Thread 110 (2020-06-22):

EU Version for 3.2 inch Nextion with PIR, LUX and BME280 Sensor, Automatic Backlight

PaulG4H, 2020-06-22:
I start with this project and update the software with the following features:

- change the display to an 3.2 inch which will fit in an standard 55mm double frame
- use an BH1750 I2C Lux sensor to calculate the screen brightness.
- the motion sensor switches the display on until timeout without re trigger by the PIR expired
- use an BME280 I2C temperature, humidity and air pressure sensor
- create a 3D printable case with base and top connected by 5x2 magnets
- use it with IP Symcon over mqtt

The software works but is not perfect as yours...

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

Are there anyone interested?

miloit, 2021-01-11:
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

Hello, I am interested.

Can you post your code and STL files.

SeraphimSerapis, 2021-01-11:
Better late than never. I'd also be interested -- would even consider buying a pre-assembled unit ;-)

PaulG4H, 2021-01-13:
Hello,

sorry for the late reply...

I will fork the project within the next week with my changes and STL Files

PaulG4H, 2021-01-13:
Fork done...

https://github.com/PaulG4H/HASwitchPlate

aderusha, 2021-01-13:
If you want to issue a PR I'd love to roll these into the main project repo!

PaulG4H, 2021-01-15:
> If you want to issue a PR I'd love to roll these into the main project repo!

Hi,

as I see you also still working in the dev branch, so it makes no sense to to do a PR for the code.

My current Version is much ahead and sliced into different files and the development is switched to Visual Studio Code with platformio instead the Arduino IDE (no more library version issues!)

My project is now an universal ESP8266 which I use for controll my 3D Printer Rack (Nextion Enhanced with 8 Relais board connected and controlled by the Nextion), three MQ4 Smoke Sensors on and ADS1015 I2C ADC board, 1-Wire Temperature Sensors and more...

It would be a honor for me if you add the stl files and code parts to your repo, then I will delete my fork again.

aderusha, 2022-09-06:
Closing as this repo is not being maintained.  [Check here for the updated project](https://github.com/HASwitchPlate/HASPone)!

Closed 2022-09-06.

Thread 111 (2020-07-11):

Connecting display using Wemos D1 R1 (not mini)

mirko25, 2020-07-11:
I have Wemos D1 R1 and Nextion NX3224T028_011 panel
I flashed firmware for nextion using sdcard successfully.
Flashed D1 using Arduino - selected WeMos D1 R1 as board also successfully.
Connected blue wire from panel to D7 and yellow to D4.
When powered on I can access web admin and set wifi network and connect to MQTT
But on display there is only message HASP Initializing...
Do I need to change something in sketch for D1 R1 board or connect display to different pins?

aderusha, 2020-07-11:
Your pinout as described should be correct.  That behavior suggests TX from the WeMos on pin D4 for some reason isn't making it to the RX on the panel.  Confirm your wiring with continuity checks, if you have access to another serial interface you can check at the panel to confirm it's seeing Nextion commands.

mirko25, 2020-07-12:
Thanks for your help. I finally found the problem. tx on my board is on pin labeled d9/tx1 so i switched it and it works.

Closed 2020-07-12.

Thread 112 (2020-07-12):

Certificate support?

jshep321, 2020-07-12:
Hi,
I have my MQTT setup for secure TLS / Certificate based usage only.  Does HASP support this?
Thanks!

aderusha, 2020-07-12:
Not as of now, no.  Doing this in a manner which works across all installations and which is also actually secure is problematic as we don't have the room nor the update mechanisms to pull trusted root certs regularly in order to compare your host cert.

It may be possible to do this insecurely, meaning connecting via TLS but not bothering to check the cert.  I'll dig into it.

jshep321, 2020-07-16:
OK thanks.  I'm soon going to be looking into integrating TLS+certs into my ESP32.  Likely similar challenges.   Might move to a REST interface instead of MQTT since TLS is already integrated there.

aderusha, 2020-12-26:
I'm digging into this one with no success thus far.  I think we might be able to do this by offering the user the ability to connect via TLS but with no actual certificate check, or by allowing the user to supply the expected certificate fingerprint.  However, getting BearSSL to work with the RAM currently left available by the rest of the code is problematic.  The most recent commit to the dev branch includes a substantial memory reduction in the form of doing fewer stupid things in the rest of the sketch.  It hasn't cleared up enough RAM to make BearSSL work right, but it's a start.

I've created a `MQTTTLSTEST` directive which turns on the current, broken attempts to make this fly.

aderusha, 2020-12-26:
Found some means to reduce the BearSSL memory requirements and that hasn't impacted functionality with any of the required services (MQTT add-in for Home Assistant and github).  Validation process is still fingerprint-only but it's a start.  `dev` branch should have a fully-working implementation, and it'll likely be pushed out in the next release here soon.

aderusha, 2022-09-06:
Closing as this repo is not being maintained.  [Check here for the updated project](https://github.com/HASwitchPlate/HASPone)!

Closed 2022-09-06.

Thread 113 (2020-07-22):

Missing Icon

CAB426, 2020-07-22:
I am trying to use the lung icon (f604) but not having any luck.  I tried fonts 6-10 and it does not seem to be included.  Wondering if it would be possible to get this font added.

EDIT:  It also appears heartbeat (f21e) in font 8 isn't available.

Appreciate it!

CAB426, 2020-07-25:
I took the time to figure out how to update the fonts in the HMI.  I also found that the heartbeat was in there, just didn't have the correct width.  Closing this as it is no longer relevant.  Loving the device!  Thanks!

Closed 2020-07-25.

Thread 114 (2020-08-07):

Track backlight on/off status for Nextion sleep/wake

aderusha, 2020-08-07:
Catch sleep/wake events from the panel and send MQTT backlight ON/OFF status in response.  Great idea @SeLLeRoNe!

SeLLeRoNe, 2020-08-07:
Thanks!!!!

jmyler, 2020-08-07:
I love this idea

mattkerrison, 2020-10-05:
Any update on this one? would be handy to wake up the screen with a touch but not accidentally activate a button

aderusha, 2020-12-03:
Also adding - create demo automations which can control sleep/wake state.

cbrochar, 2021-01-09:
I have been using the sleep mode via the automation in examples. I have noticed you cannot change the sleep on touch timer while the screen is asleep. Looing in the instruction set "A get/print/printh/wup/sleep instruction can be executed during sleep mode. "  So if the screen is asleep it ignores the "thup" command. I am able to avoid this by including a "sleep=0" command in the JSON just before the thup command. However, I noticed that you are strating to implement this issue/enhancement. I am wondering how this will effect the backlight on/off since the nextion will not send the 0x87, it should return a 0x68, So you may be able to add the backlight on to the "else if (nextionReturnBuffer[0] == 0x67 || nextionReturnBuffer[0] == 0x68)" statement. This way you do not get off-track when a sleep=0 command is sent.

aderusha, 2022-09-06:
Closing as this repo is not being maintained.  [Check here for the updated project](https://github.com/HASwitchPlate/HASPone)!

Closed 2022-09-06.

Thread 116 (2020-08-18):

{request} - Any chance you can export the sketchup as a STEP file?

kquinsland, 2020-08-18:
First, this project represents a *TON* of work and i'm grateful you've shared it with us!

I am (attempting) to make a few small modifications to add some functionality. This functionality does require *slight* modifications to the 3d printable enclosures, however.

The CAD package that i am strongest with is Fusion360... which does not have very good support for sketchup file imports. The results are... less than ideal. It appears that the individual polygons / triangle faces are what fusion is able to import. This makes some amount of sense to me as Fusion360 is not a native mesh program... but apparently sketchup is.

I did a quick bit of google and it does appear that sketchup *pro* supports exporting to STEP format, but it's not clear to me if this file / model was developed with pro.

If you can't do the export / conversion then don't worry about it / close this ticket and i'll re-create the model in f360 to make the changes there.

If the changes are successful, i'll publish the STEP files so they should be a painless import into any CAD package.

Thanks again for putting this project together :).

aderusha, 2020-08-18:
I am using Sketchup Pro, but the only means I know of to export STEP from SketchUp is via paid 3rd party plugins.  Annoyingly, I don't know of any particularly good way to bring this into f360.

kquinsland, 2020-08-18:
Ah, you're right!

I re-read a few of the threads that popped up on my google search and it turns out that you need to use the extension store in sketchup pro to do this. I will try exporting to DXF or just project the mesh and re-do it that way.

Thanks for the quick reply!

kquinsland, 2020-10-17:
I was not able to find a clean way to port the sketchup files to STEP, so i re-created them.

After a lot of work, I was able to incorporate the two modifications that I hinted at when I opened this thread:
- NeoPixels /. addressable RGB LEDs beneath the surface of the plate
- LDR / light. sensor beneath the surface of the plate.

Details on the mods: [here](https://karlquinsland.com/2020/10/enhanced-home-assistant-switch-plate-hasp/) and the STEP files are [here](https://github.com/kquinsland/HASwitchPlate/blob/add-neopixels/3D_Printable_Models/enhanced-HASP/combined.step)

Closed 2020-08-18.

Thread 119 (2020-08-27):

QOS or how to check mqtt state

Thoky81, 2020-08-27:
I would like to ask if the plate can publish the actual state of the buttons. Is this possible with mqtt qos? For example when I arm/disarm alarm in Home Assistant I dont always see the button on plate updated even if the alarm state in HA is changing the state accordingly.

I have include with mqtt.publish:

data:
  ...
  retain: true
  qos: 2

That helped a bit I think, but still the response is not so reliably.

Can somebody advice?

Thanks

aderusha, 2020-09-07:
Can you pull a debug log when the desired update is happening but being missed by HASP?

aderusha, 2020-11-05:
Any update on this?

aderusha, 2020-12-19:
Closing after no update from submitter

Closed 2020-12-19.

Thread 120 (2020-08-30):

Display works on USB but not thru PSU

exeljb, 2020-08-30:
So I'm trying to get my setup working but I'm having issues while powered up thru AC power.  Everything works fine when I power everything up thru the USB port on the D1 mini.  Then when I plug in the AC (USB power removed) everything powers up, D1 and Nextion but the display doesn't seem to send any serial data nor does it react to it.  I've checked that my PSU is outputting 4.99Vdc and has a ripple of 9mVac, USB power was showing 4.99 and 11mVac so I'm sure my PSU is ok.  Does anyone have any insights on why serial data might stop working when not using the USB power?

xHirscHx, 2020-09-03:
Had same issue  look at my post in closed issues "no power issues"
Check your grounds mine was a ground issue on the board.

aderusha, 2020-09-07:
Nothing specific to offer other than a generic "check your solder joints".  Have you made any more progress with this?

exeljb, 2020-09-08:
I had a chance to mess with it this weekend.  I had tried to clean up and make sure the solder joints were in good shape but the condition persisted.  I opted to just grab another pcb and power supply and put it all together from scratch.  The condition was not present on that new setup.
I'm unsure if it was a pcb, a psu or the transistor.  A DMM measurement from display ground to psu ground showed 50 ohms, which seems high.  On the new setup, I took the display ground straight to the psu ground.  Anyhow, I'm all set now, project is working and looking good.

Closed 2020-09-08.

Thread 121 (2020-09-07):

shorted Screen (help)

xHirscHx, 2020-09-07:
Any body out there blow the Nextion  Display fuse can it be replaced. When i was putting it in wall must have pushed to hard everything works when i swapped the screen out.@ 20 bucks a pop would love to fix this one.

aderusha, 2020-09-07:
To my knowledge the LCD itself is not fused.  I'd try asking around at unofficialnextion.com.

Closed 2020-09-07.

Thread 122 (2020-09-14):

Wemos D1 mini availability

bgardner46, 2020-09-14:
I built my first HASP and, after writing a short TCL plugin, it works great with my Homevision system. I would like to build a few more but have a question about sourcing more d1 minis. The link in the documentation now points to a device called a d1 mini nodemcu and I'm not sure if they are physically or electrically compatible. I did see the link below on Amazon but it is v3.0.0 and the ones I purchased from Aliexpress that are currently working are 3.1.0. Aliexpress lists these as no longer available.
[https://www.amazon.com/Stemedu-Arduino-Nodemcu-MicroPython-Female/dp/B0894XL9TW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](url)

Any suggestions?
Thanks for this great project and for sharing it with all of us.
Bob

aderusha, 2020-09-14:
While I've not tested all the various D1 mini versions out there, I've never had a particular version not work. [Their info page](https://docs.wemos.cc/en/latest/d1/d1_mini.html) isn't really clear on what is changing between revisions, but I think it's safe to expect it's something regarding component availability over time.  From our perspective, all the various versions should work.

So - I think you should be all set!

Have you published your work on the Homevision integration anywhere?  Really curious to hear more about that!

bgardner46, 2020-09-14:
Okay, thanks. I'll try the V3.0.0 models and let you know if there's any
problem.

I haven't published anything yet but will add a page to my website soon and
let you know when it's available.

Bob

On Mon, Sep 14, 2020 at 3:35 PM Allen Derusha <notifications@github.com>
wrote:

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

Closed 2020-11-05.

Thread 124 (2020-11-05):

Real bad contrast for the display?

psarossy, 2020-11-05:
I got one of the pre-assembled units to test this design out (and I love every other part of it), but the screen seems to have horrific viewing angles from the top, where it's viewed from 99% of the time, and fine from the bottom.

Is this normal? Is the screen defective, or should be upside down?

https://photos.app.goo.gl/fy1NVs8dXJzjTkKT7

aderusha, 2020-11-05:
Nextion has changed their LCD panels around some time a couple years ago and the viewing angles aren't always great from some directions.  If the viewing angle works better from below, there is a simple (if somewhat stupid) fix - physically mount the device upside down, and then flash the Nextion firmware [HASwitchPlate-Inverted.tft](https://github.com/aderusha/HASwitchPlate/blob/master/Nextion_HMI/HASwitchPlate-Inverted.tft) to the LCD.  That firmware is the same as the normal LCD firmware, just flipped 180°.

Give it a shot and let me know how it goes!

psarossy, 2020-11-25:
Sorry for the delayed response... The inverted firmware and turning upside down fixed my issue, but since I used a 3 slot decora plate, I couldn't just mount it upside down, but had to print a new plate as the LCD is not symmetrical.

Closed 2020-11-25.

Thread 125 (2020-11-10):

buttons are working but display is not getting the text

dimitrybradt, 2020-11-10:
Hello,

While the text buttons are not being displayed on the device, the d1 receives the commands from HA.
I've used an NX4832T035 at this point since I'm still waiting for the delivery of the NX3224T024.
Should I do anything more (than enlarging the buttons) in the nextion editor for a fix?

Thanks!

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

aderusha, 2020-11-10:
Nearly 100% this is a wiring problem.  Check your solder joints, this is what happens when TX from the panel doesn't make it to D7 on the Wemos D1.  You should be able to check w/ a continuity test between those pins.

dimitrybradt, 2020-11-10:
Hi,

The setup is still with Dupont cables...  I'm getting serial connection with display and Arduino board. so that's not the issue.
I must say if I use the emulator it doesn't show me a lot either (based on the code of output of the board.)
firmware issue? I'm using latest haspplate firmware and stock screen firmware but loaded correct nextion display through a serial connection.

aderusha, 2020-11-10:
Based on your log, you are not getting two-way communication with your LCD.  The firmware for both devices is in pretty wide use at this point, and while it's certainly not perfect it does work.  You will be best served to confirm a full signal path between the Wemos and the LCD, because that's almost certainly where your problem lies.

aderusha, 2020-12-19:
Following up - did you get your HASP working as expected?

Closed 2020-12-23.

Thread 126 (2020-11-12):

Screen Size Limits?

patschi1983, 2020-11-12:
Are there any limits for screen sizes or is even an 7" Nextion screen possible?
Thx

petergreis, 2020-11-12:
I am using a 7” screen, works just fine. I use a slightly beefier voltage regulator just to be sure...

On Nov 12, 2020, at 15:22, patschi1983 <notifications@github.com> wrote:

Are there any limits for screen sizes or is even an 7" Nextion screen possible?
Thx

—
You are receiving this because you are subscribed to this thread.
Reply to this email directly, view it on GitHub<https://github.com/aderusha/HASwitchPlate/issues/126>, or unsubscribe<https://github.com/notifications/unsubscribe-auth/ABBDJJ6AU4BPAOVHMWDT44TSPPVQPANCNFSM4TTLBPNQ>.

patschi1983, 2020-11-13:
THX for the fast response. ;-)

Closed 2020-11-13.

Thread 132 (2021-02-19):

Czech font coding

proasnet, 2021-02-19:
Hi, I have builded a prototype your HA Switch and is working with my Home Assistant.
Now, I tried edit a HMI file with Nextion Editor and I used a font generator with coding ISO-8859-2 with czech letters, as a "ěščřžýáíéúů", I replaced the first four font positions with the same size, but new codding, I change coding in Device settings.
Then I generated a new tft file, load to display.
Now, if I use texts for buttons with czech diacritics, on display in buttons I have a "loose tea"
I thing, that coding of mqtt messages have a limits, but I dont know, where I can set it if is possible.
Please, have somebody any idea?
Thank you

aderusha, 2022-09-06:
Closing as this repo is not being maintained.  [Check here for the updated project](https://github.com/HASwitchPlate/HASPone)!

Closed 2022-09-06.

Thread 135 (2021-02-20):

Configuration Saved, but immediately forgotten

mpoli, 2021-02-20:
I am having a persistent issue with 0.40 that causes the configuration, expect for SSID and SSID password to be "forgotten"  or not "sitck", and even the board name reverts to plate01 when I follow this procedure:

Recorded with ESP8266 flasher, DOUT, 1MB config

I boot the recently recorded device and I connect to the HASwitchPlate Wifi Network and fill in the SSID and SSID password, which is 50+ chars long, and change nothing else.

After the reboot, the device connects normally to the Wi-Fi network.

I open the web interface and start filling up the remaining information:

- HASP node name is 15 chars, all lower case and one "_"
- MQTT broker is an IP address
- MQTT port left at the default 1883
- MQTT user: "mqtt"
- MQTT password: a mix of lower case, upper case and special chars and numbers, 10+ chars long
- HASP Admin name left to default
- HASP Admin Password is 12 chars, upper case and lower case

Remaning options set to default.

I hit " save settings"

A screen with the correct name I just input pops up with:

caretaker_plate

Saving updated configuration values and restarting device

But then, nothing is really saved. The next time I open the screen, only the Wifi information is preserved, everything else reverts to default and I get this information from the from part of the screen:

MQTT Status: Disconnected, return code: 0
MQTT ClientID:
HASP Version: 0.40
LCD Model:
LCD Version: 0
LCD Active Page: 0
CPU Frequency: 160MHz
Sketch Size: 477536 bytes
Free Sketch Space: 2666496 bytes
Heap Free: 20176
Heap Fragmentation: 1
ESP core version: 2_6_3
IP Address: 192.168.1.76
Signal Strength: -69
Uptime: 15
Last reset: Fatal exception:0 flag:4 (SOFT_RESTART) epc1:0x00000000 epc2:0x00000000 epc3:0x00000000 excvaddr:0x00000000 depc:0x00000000

If I fill in all the information while connected to the HASwitchPlate (at first boot), all seems to work fine, and de device connectes to Wifi and MQTT without any apparent issues.

alexives, 2021-03-04:
I had the same problem, but I tried the procedure here - https://github.com/aderusha/HASwitchPlate/issues/107#issuecomment-629784869 and it seems to have worked for me.

> re-flash the firmware through the admin web page, followed by a factory reset.

aderusha, 2022-09-06:
Closing as this repo is not being maintained.  [Check here for the updated project](https://github.com/HASwitchPlate/HASPone)!

Closed 2022-09-06.

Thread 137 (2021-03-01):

Backlight MQTT message ignored if page set payload is first/same time.

marc-gist, 2021-03-01:
I have an automation that worked before the update to the latest beta/dev branch bin as of 11 days ago.
My Screen now flickers when changing pages, no big deal.  However, what broke on this update is>

When my lights turn off, I send two payloads to the screen (which worked before).

`hasp/plate01/brightness/set = 10`
`hasp/plate01/command/page = 2`

Basically at the same time.  If I add a slight delay to the Brightness one, it still does now work (brightness doesn't change).
If I add a delay to the Page (so brightness gets in first for sure), it works fine.

I've not change anything else, just the firmware. so not sure what is causing this.

aderusha, 2021-03-01:
I'm unable to re-create this behavior.

```bash
mosquitto_pub -h hassio -u hassio -P hassio -t 'hasp/plate01/brightness/set' -m '10'
mosquitto_pub -h hassio -u hassio -P hassio -t 'hasp/plate01/command/page' -m '2'
```

Works as expected on the current build.  I'll keep testing this as work continues.

marc-gist, 2021-03-01:
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

Thanks for testing. I will see if I can find an issue in my automations.

aderusha, 2022-09-06:
Closing as this repo is not being maintained.  [Check here for the updated project](https://github.com/HASwitchPlate/HASPone)!

Closed 2022-09-06.

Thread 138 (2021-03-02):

Desktop USB cutout line up

bgardner46, 2021-03-02:
I wasn't sure if this was the correct place to address this but here goes. I have built several in wall units and they work great- you do great work and I am impressed. I decided to build a desktop unit and the parts printed great but I can't figure out how to get the USB port on the d1mini to line up with the cutout in the back and the stand. Maybe I'm missing something but could use some suggestions for mounting the mini. I actually modified the back by making the hole a little larger and then mounted the d1mini at an angle and it sort of works but I feel like I'm missing something.

Thanks again for a great project.

Bob

aderusha, 2021-03-02:
Are you assembling this on the PCB?  Can you post pics of what your board looks like?

bgardner46, 2021-03-02:
I'm assembling on the same PCB as the wall units. I'm mounting the
d1mini directly to the PCB with standard headers. Here's a top view of the
original back:

[image: topview.jpg]

and here's a side view:

[image: sideview.jpg]

here's a finished unit with the modified d1mini install:

[image: desktop.jpg]

So any suggestions? Am I doing something wrong?

Thanks,

Bob

On Tue, Mar 2, 2021 at 1:15 PM Allen Derusha <notifications@github.com>
wrote:

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

aderusha, 2021-03-02:
Looks like the photos aren't working in your post.  Can you maybe drop them on imgur or similar?

bgardner46, 2021-03-02:
How about a Dropbox share link?

https://www.dropbox.com/sh/wi7o6gd5bsj910x/AABJnZ58sI9hFjtXRzadKY-Ea?dl=0

On Tue, Mar 2, 2021 at 2:36 PM Allen Derusha <notifications@github.com>
wrote:

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

bgardner46, 2021-03-03:
Here's an Imgur link as well. I set them as hidden but assume that you can
still view them with a link - not a regular Imgur user.

https://imgur.com/a/GOv8wAn

Bob

On Tue, Mar 2, 2021 at 2:36 PM Allen Derusha <notifications@github.com>
wrote:

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

aderusha, 2021-03-03:
Not sure if this is the problem but it appears that you're using the newer D1 mini board, [the BOM link](https://amzn.to/2UZlga4) has the right device which is a slightly different from the D1 you have in the photos above.

Specifically, it appears the version of the board you are using has the USB micro port soldered to the top instead of the bottom, and everything is out of alignment as a result.

This is pretty annoying but it's clearly the result of me under-specifying the correct parts to use :(

bgardner46, 2021-03-03:
I think you nailed it. I didn't even realize there were boards with the USB
connector on the bottom - my bad. I just ordered a couple.

Thanks for the quick response.

Bob

On Wed, Mar 3, 2021 at 5:10 AM Allen Derusha <notifications@github.com>
wrote:

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

Closed 2021-03-04.

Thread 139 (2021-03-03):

Link to 1.75mm filament

kdegraaf, 2021-03-03:
https://github.com/aderusha/HASwitchPlate/blob/master/3D_Printable_Models/README.md

The filament suggestion link on that page goes to AmazonBasics White PETG in 2.85mm.  I'm not sure how your Prusa i3 is configured, but my MK3S+ takes 1.75mm and I would guess that for most users, this is the correct size.  I suggest adding a link to the 1.75mm version.

For clarity, the links in question are:

https://www.amazon.com/AmazonBasics-Printer-Filament-2-85mm-White/dp/B07SZLZG5G
https://www.amazon.com/AmazonBasics-Printer-Filament-1-75mm-White/dp/B07T6W63MY

aderusha, 2022-09-06:
Closing as this repo is not being maintained.  [Check here for the updated project](https://github.com/HASwitchPlate/HASPone)!

Closed 2022-09-06.

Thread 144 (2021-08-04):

stuck on HASP initializing

pljda, 2021-08-04:
Hi, I have the same problem than #80 , could connect once. The stuck on the HASP initializing screen !!
I tested the link between D4 and RXD, D7 and TXD, 5v& Gnd - all are OK.
reinserted the micro SD card - reboot - HASP Initializing ...

Is there a way or bin file so I can reset the screen ?
Thanks - Philippe

aderusha, 2021-08-04:
First thing, you'll probably want to [head over to the new repository for the project](https://github.com/HASwitchPlate/HASPone) as a lot has changed since this repo was moved over there.

If you aren't getting a white screen showing the LCD update process when you power up with a microSD card inserted, [check through this guide](https://nextion.tech/faq-items/using-nextion-microsd/) to ensure that the microSD card has been setup correctly for use with Nextion.

pljda, 2021-08-04:
Hi Allen,
Thanks for your prompt reply. I finally mange to solve my concern with a full retart from the Wemos Mini.
It took me sometime to navigate and find some recap info .
Anyway congrat for your great job.

Closed 2021-08-08.

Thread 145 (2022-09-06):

File Version is too low

lroubinov, 2022-09-06:
I trying to flash the screen
but gettin file version is too low error

aderusha, 2022-09-06:
Hey @lroubinov !  You're currently looking at the old version of this project, which has been deprecated for a couple years at this point.  [Head over to the new project](https://github.com/HASwitchPlate/HASPone) and you'll find things might work out a little better for you :D

Closed 2022-09-06.

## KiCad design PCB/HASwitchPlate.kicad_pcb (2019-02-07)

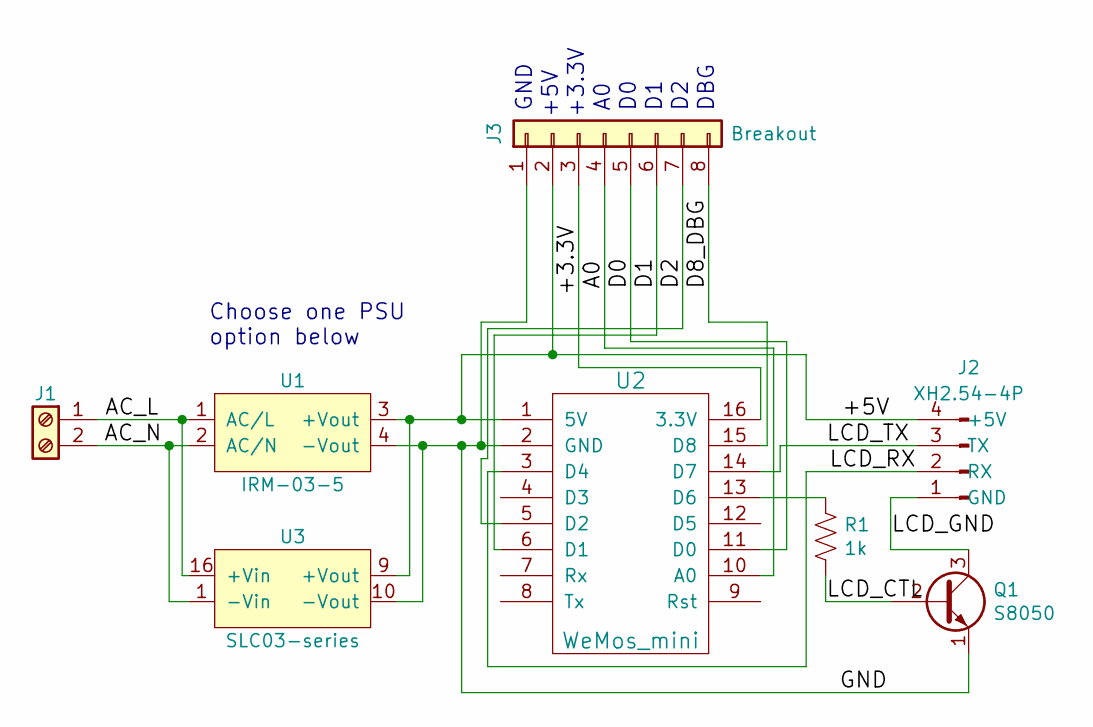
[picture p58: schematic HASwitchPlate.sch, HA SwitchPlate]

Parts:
J1: Screw Term.; TerminalBlock_bornier-2_P5.08mm
J2: XH2.54-4P; JST_XH2.54_04x2.54mm_Straight
J3: Breakout; Pin_Header_Straight_1x08_Pitch2.54mm
Q1: S8050; TO-92L_HandSolder
R1: 1k; R_Axial_DIN0207_L6.3mm_D2.5mm_P7.62mm_Horizontal
U1: IRM-03-5; ACDC-Converter_MeanWell-IRM-03-x
U2: WeMos_mini; wemos-d1-mini-with-pin-header-and-connector
U3: SLC03-series; ACDC-Converter_MeanWell-SLC03-series

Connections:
/+3.3V: J3.3, U2.16 (3.3V)
/+5V: J2.4 (+5V), J3.2, U1.3 (+Vout), U2.1 (5V), U3.9 (+Vout)
/A0: J3.4, U2.10 (A0)
/AC_L: J1.1, U1.1 (AC/L), U3.16 (+Vin)
/AC_N: J1.2, U1.2 (AC/N), U3.1 (-Vin)
/D0: J3.5, U2.11 (D0)
/D1: J3.6, U2.6 (D1)
/D2: J3.7, U2.5 (D2)
/D8_DBG: J3.8, U2.15 (D8)
/GND: J3.1, Q1.1 (E), U1.4 (-Vout), U2.2 (GND), U3.10 (-Vout)
/LCD_CTL: Q1.2 (B), R1.2
/LCD_GND: J2.1 (GND), Q1.3 (C)
/LCD_RX: J2.2 (RX), U2.3 (D4)
/LCD_TX: J2.3 (TX), U2.14 (D7)
unnamed: R1.1, U2.13 (D6)

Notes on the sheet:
GND
+5V
+3.3V
DBG
Choose one PSU option below

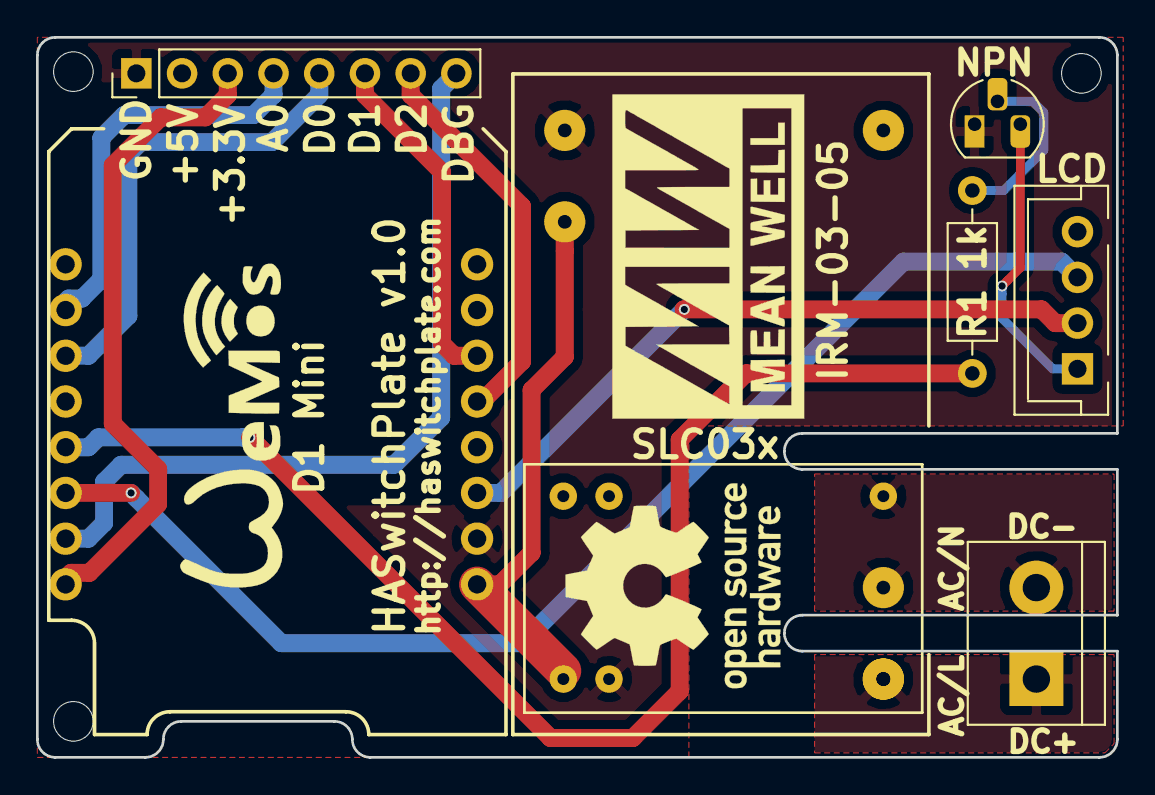
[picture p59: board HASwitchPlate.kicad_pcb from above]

Board: 2 copper layers, 60.0 x 40.0 mm, 8 parts (0 on the bottom side), 15 nets.

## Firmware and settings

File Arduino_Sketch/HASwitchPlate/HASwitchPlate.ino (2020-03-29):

////////////////////////////////////////////////////////////////////////////////////////////////////
//           _____ _____ _____ _____
//          |  |  |  _  |   __|  _  |
//          |     |     |__   |   __|
//          |__|__|__|__|_____|__|
//        Home Automation Switch Plate
// https://github.com/aderusha/HASwitchPlate
//
// Copyright (c) 2019 Allen Derusha allen@derusha.org
//
// MIT License
//
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
// OPTIONAL: Assign default values here.
char wifiSSID[32] = ""; // Leave unset for wireless autoconfig. Note that these values will be lost
char wifiPass[64] = ""; // when updating, but that's probably OK because they will be saved in EEPROM.

////////////////////////////////////////////////////////////////////////////////////////////////////
// These defaults may be overwritten with values saved by the web interface
char mqttServer[64] = "";
char mqttPort[6] = "1883";
char mqttUser[32] = "";
char mqttPassword[32] = "";
char haspNode[16] = "plate01";
char groupName[16] = "plates";
char configUser[32] = "admin";
char configPassword[32] = "";
char motionPinConfig[3] = "0";
////////////////////////////////////////////////////////////////////////////////////////////////////

#include <FS.h>
#include <ESP8266WiFi.h>
#include <ESP8266mDNS.h>
#include <WiFiUdp.h>
#include <ArduinoOTA.h>
#include <DNSServer.h>
#include <ESP8266HTTPClient.h>
#include <ESP8266WebServer.h>
#include <ESP8266httpUpdate.h>
#include <ESP8266HTTPUpdateServer.h>
#include <WiFiManager.h>
#include <ArduinoJson.h>
#include <MQTT.h>
#include <EEPROM.h>
#include <SoftwareSerial.h>

const float haspVersion = 0.40;                     // Current HASP software release version
byte nextionReturnBuffer[128];                      // Byte array to pass around data coming from the panel
uint8_t nextionReturnIndex = 0;                     // Index for nextionReturnBuffer
uint8_t nextionActivePage = 0;                      // Track active LCD page
bool lcdConnected = false;                          // Set to true when we've heard something from the LCD
const char wifiConfigPass[9] = "hasplate";          // First-time config WPA2 password
const char wifiConfigAP[14] = "HASwitchPlate";      // First-time config SSID
bool shouldSaveConfig = false;                      // Flag to save json config to SPIFFS
bool nextionReportPage0 = false;                    // If false, don't report page 0 sendme
const unsigned long updateCheckInterval = 43200000; // Time in msec between update checks (12 hours)
unsigned long updateCheckTimer = 0;                 // Timer for update check
const unsigned long nextionCheckInterval = 5000;    // Time in msec between nextion connection checks
unsigned long nextionCheckTimer = 0;                // Timer for nextion connection checks
unsigned int nextionRetryMax = 5;                   // Attempt to connect to panel this many times
bool updateEspAvailable = false;                    // Flag for update check to report new ESP FW version
float updateEspAvailableVersion;                    // Float to hold the new ESP FW version number
bool updateLcdAvailable = false;                    // Flag for update check to report new LCD FW version
bool debugSerialEnabled = true;                     // Enable USB serial debug output
bool debugTelnetEnabled = false;                    // Enable telnet debug output
bool debugSerialD8Enabled = true;                   // Enable hardware serial debug output on pin D8
const unsigned long telnetInputMax = 128;           // Size of user input buffer for user telnet session
bool motionEnabled = false;                         // Motion sensor is enabled
bool mdnsEnabled = true;                            // mDNS enabled
bool beepEnabled = false;                           // Keypress beep enabled
unsigned long beepPrevMillis = 0;                   // will store last time beep was updated
unsigned long beepOnTime = 1000;                    // milliseconds of on-time for beep
unsigned long beepOffTime = 1000;                   // milliseconds of off-time for beep
boolean beepState;                                  // beep currently engaged
unsigned int beepCounter;                           // Count the number of beeps
byte beepPin;                                       // define beep pin output
uint8_t motionPin = 0;                              // GPIO input pin for motion sensor if connected and enabled
bool motionActive = false;                          // Motion is being detected
const unsigned long motionLatchTimeout = 30000;     // Latch time for motion sensor
const unsigned long motionBufferTimeout = 1000;     // Latch time for motion sensor
unsigned long lcdVersion = 0;                       // Int to hold current LCD FW version number
unsigned long updateLcdAvailableVersion;            // Int to hold the new LCD FW version number
bool lcdVersionQueryFlag = false;                   // Flag to set if we've queried lcdVersion
const String lcdVersionQuery = "p[0].b[2].val";     // Object ID for lcdVersion in HMI
bool startupCompleteFlag = false;                   // Startup process has completed
const long statusUpdateInterval = 300000;           // Time in msec between publishing MQTT status updates (5 minutes)
long statusUpdateTimer = 0;                         // Timer for update check
const unsigned long connectTimeout = 300;           // Timeout for WiFi and MQTT connection attempts in seconds
const unsigned long reConnectTimeout = 15;          // Timeout for WiFi reconnection attempts in seconds
byte espMac[6];                                     // Byte array to store our MAC address
const uint16_t mqttMaxPacketSize = 4096;            // Size of buffer for incoming MQTT message
String mqttClientId;                                // Auto-generated MQTT ClientID
String mqttGetSubtopic;                             // MQTT subtopic for incoming commands requesting .val
String mqttGetSubtopicJSON;                         // MQTT object buffer for JSON status when requesting .val
String mqttStateTopic;                              // MQTT topic for outgoing panel interactions
String mqttStateJSONTopic;                          // MQTT topic for outgoing panel interactions in JSON format
String mqttCommandTopic;                            // MQTT topic for incoming panel commands
String mqttGroupCommandTopic;                       // MQTT topic for incoming group panel commands
String mqttStatusTopic;                             // MQTT topic for publishing device connectivity state
String mqttSensorTopic;                             // MQTT topic for publishing device information in JSON format
String mqttLightCommandTopic;                       // MQTT topic for incoming panel backlight on/off commands
String mqttBeepCommandTopic;                        // MQTT topic for error beep
String mqttLightStateTopic;                         // MQTT topic for outgoing panel backlight on/off state
String mqttLightBrightCommandTopic;                 // MQTT topic for incoming panel backlight dimmer commands
String mqttLightBrightStateTopic;                   // MQTT topic for outgoing panel backlight dimmer state
String mqttMotionStateTopic;                        // MQTT topic for outgoing motion sensor state
String nextionModel;                                // Record reported model number of LCD panel
const byte nextionSuffix[] = {0xFF, 0xFF, 0xFF};    // Standard suffix for Nextion commands
uint32_t tftFileSize = 0;                           // Filesize for TFT firmware upload
uint8_t nextionResetPin = D6;                       // Pin for Nextion power rail switch (GPIO12/D6)

WiFiClient wifiClient;
WiFiClient wifiMQTTClient;
MQTTClient mqttClient(mqttMaxPacketSize);
ESP8266WebServer webServer(80);
ESP8266HTTPUpdateServer httpOTAUpdate;
WiFiServer telnetServer(23);
WiFiClient telnetClient;
MDNSResponder::hMDNSService hMDNSService;

// Additional CSS style to match Hass theme
const char HASP_STYLE[] = "<style>button{background-color:#03A9F4;}body{width:60%;margin:auto;}input:invalid{border:1px solid red;}input[type=checkbox]{width:20px;}</style>";
// URL for auto-update "version.json"
const char UPDATE_URL[] = "http://haswitchplate.com/update/version.json";
// Default link to compiled Arduino firmware image
String espFirmwareUrl = "http://haswitchplate.com/update/HASwitchPlate.ino.d1_mini.bin";
// Default link to compiled Nextion firmware images
String lcdFirmwareUrl = "http://haswitchplate.com/update/HASwitchPlate.tft";

////////////////////////////////////////////////////////////////////////////////////////////////////
void setup()
{ // System setup
  pinMode(nextionResetPin, OUTPUT);
  digitalWrite(nextionResetPin, HIGH);
  Serial.begin(115200);  // Serial - LCD RX (after swap), debug TX
  Serial1.begin(115200); // Serial1 - LCD TX, no RX
  Serial.swap();

  debugPrintln(String(F("SYSTEM: Starting HASwitchPlate v")) + String(haspVersion));
  debugPrintln(String(F("SYSTEM: Last reset reason: ")) + String(ESP.getResetInfo()));

  configRead(); // Check filesystem for a saved config.json

  while (!lcdConnected && (millis() < 5000))
  { // Wait up to 5 seconds for serial input from LCD
    nextionHandleInput();
  }
  if (lcdConnected)
  {
    debugPrintln(F("HMI: LCD responding, continuing program load"));
    nextionSendCmd("connect");
  }
  else
  {
    debugPrintln(F("HMI: LCD not responding, continuing program load"));
  }

  espWifiSetup(); // Start up networking

  if (mdnsEnabled)
  { // Setup mDNS service discovery if enabled
    hMDNSService = MDNS.addService(haspNode, "http", "tcp", 80);
    if (debugTelnetEnabled)
    {
      MDNS.addService(haspNode, "telnet", "tcp", 23);
    }
    MDNS.addServiceTxt(hMDNSService, "app_name", "HASwitchPlate");
    MDNS.addServiceTxt(hMDNSService, "app_version", String(haspVersion).c_str());
    MDNS.update();
  }

  if ((configPassword[0] != '\0') && (configUser[0] != '\0'))
  { // Start the webserver with our assigned password if it's been configured...
    httpOTAUpdate.setup(&webServer, "/update", configUser, configPassword);
  }
  else
  { // or without a password if not
    httpOTAUpdate.setup(&webServer, "/update");
  }
  webServer.on("/", webHandleRoot);
  webServer.on("/saveConfig", webHandleSaveConfig);
  webServer.on("/resetConfig", webHandleResetConfig);
  webServer.on("/resetBacklight", webHandleResetBacklight);
  webServer.on("/firmware", webHandleFirmware);
  webServer.on("/espfirmware", webHandleEspFirmware);
  webServer.on("/lcdupload", HTTP_POST, []() { webServer.send(200); }, webHandleLcdUpload);
  webServer.on("/tftFileSize", webHandleTftFileSize);
  webServer.on("/lcddownload", webHandleLcdDownload);
  webServer.on("/lcdOtaSuccess", webHandleLcdUpdateSuccess);
  webServer.on("/lcdOtaFailure", webHandleLcdUpdateFailure);
  webServer.on("/reboot", webHandleReboot);
  webServer.onNotFound(webHandleNotFound);
  webServer.begin();
  debugPrintln(String(F("HTTP: Server started @ http://")) + WiFi.localIP().toString());

  espSetupOta(); // Start OTA firmware update

  mqttClient.begin(mqttServer, atoi(mqttPort), wifiMQTTClient); // Create MQTT service object
  mqttClient.onMessage(mqttCallback);                           // Setup MQTT callback function
  mqttConnect();                                                // Connect to MQTT

  motionSetup(); // Setup motion sensor if configured

  if (beepEnabled)
  { // Setup beep/tactile if configured
    beepPin = 4;
    pinMode(beepPin, OUTPUT);
  }

  if (debugTelnetEnabled)
  { // Setup telnet server for remote debug output
    telnetServer.setNoDelay(true);
    telnetServer.begin();
    debugPrintln(String(F("TELNET: debug server enabled at telnet:")) + WiFi.localIP().toString());
  }

  debugPrintln(F("SYSTEM: System init complete."));
}

////////////////////////////////////////////////////////////////////////////////////////////////////
void loop()
{ // Main execution loop

  if (nextionHandleInput())
  { // Process user input from HMI
    nextionProcessInput();
  }

  while ((WiFi.status() != WL_CONNECTED) || (WiFi.localIP().toString() == "0.0.0.0"))
  { // Check WiFi is connected and that we have a valid IP, retry until we do.
    if (WiFi.status() == WL_CONNECTED)
    { // If we're currently connected, disconnect so we can try again
      WiFi.disconnect();
    }
    espWifiReconnect();
  }

  if (!mqttClient.connected())
  { // Check MQTT connection
    debugPrintln("MQTT: not connected, connecting.");
    mqttConnect();
  }

  mqttClient.loop();        // MQTT client loop
  ArduinoOTA.handle();      // Arduino OTA loop
  webServer.handleClient(); // webServer loop
  if (mdnsEnabled)
  {
    MDNS.update();
  }

  if ((lcdVersion < 1) && (millis() <= (nextionRetryMax * nextionCheckInterval)))
  { // Attempt to connect to LCD panel to collect model and version info during startup
    nextionConnect();
  }
  else if ((lcdVersion > 0) && (millis() <= (nextionRetryMax * nextionCheckInterval)) && !startupCompleteFlag)
  { // We have LCD info, so trigger an update check + report
    if (updateCheck())
    { // Send a status update if the update check worked
      mqttStatusUpdate();
      startupCompleteFlag = true;
    }
  }
  else if ((millis() > (nextionRetryMax * nextionCheckInterval)) && !startupCompleteFlag)
  { // We still don't have LCD info so go ahead and run the rest of the checks once at startup anyway
    updateCheck();
    mqttStatusUpdate();
    startupCompleteFlag = true;
  }

  if ((millis() - statusUpdateTimer) >= statusUpdateInterval)
  { // Run periodic status update
    statusUpdateTimer = millis();
    mqttStatusUpdate();
  }

  if ((millis() - updateCheckTimer) >= updateCheckInterval)
  { // Run periodic update check
    updateCheckTimer = millis();
    if (updateCheck())
    { // Send a status update if the update check worked
      mqttStatusUpdate();
    }
  }

  if (motionEnabled)
  { // Check on our motion sensor
    motionUpdate();
  }

  if (debugTelnetEnabled)
  {
    handleTelnetClient(); // telnetClient loop
  }

  if (beepEnabled)
  { // Process Beeps
    if ((beepState == true) && (millis() - beepPrevMillis >= beepOnTime) && ((beepCounter > 0)))
    {
      beepState = false;         // Turn it off
      beepPrevMillis = millis(); // Remember the time
      analogWrite(beepPin, 254); // start beep for beepOnTime
      if (beepCounter > 0)
      { // Update the beep counter.
        beepCounter--;
      }
    }
    else if ((beepState == false) && (millis() - beepPrevMillis >= beepOffTime) && ((beepCounter >= 0)))
    {
      beepState = true;          // turn it on
      beepPrevMillis = millis(); // Remember the time
      analogWrite(beepPin, 0);   // stop beep for beepOffTime
    }
  }
}

////////////////////////////////////////////////////////////////////////////////////////////////////
// Functions

////////////////////////////////////////////////////////////////////////////////////////////////////
void mqttConnect()
{ // MQTT connection and subscriptions

  static bool mqttFirstConnect = true; // For the first connection, we want to send an OFF/ON state to
                                       // trigger any automations, but skip that if we reconnect while
                                       // still running the sketch

  // Check to see if we have a broker configured and notify the user if not
  if (mqttServer[0] == 0)
  {
    nextionSendCmd("page 0");
    nextionSetAttr("p[0].b[1].font", "6");
    nextionSetAttr("p[0].b[1].txt", "\"WiFi Connected!\\r " + String(WiFi.SSID()) + "\\rIP: " + WiFi.localIP().toString() + "\\r\\rConfigure MQTT:\\rhttp://" + WiFi.localIP().toString() + "\"");
    while (mqttServer[0] == 0)
    { // Handle HTTP and OTA while we're waiting for MQTT to be configured
      yield();
      if (nextionHandleInput())
      { // Process user input from HMI
        nextionProcessInput();
      }
      webServer.handleClient();
      ArduinoOTA.handle();
    }
  }
  // MQTT topic string definitions
  mqttStateTopic = "hasp/" + String(haspNode) + "/state";
  mqttStateJSONTopic = "hasp/" + String(haspNode) + "/state/json";
  mqttCommandTopic = "hasp/" + String(haspNode) + "/command";
  mqttGroupCommandTopic = "hasp/" + String(groupName) + "/command";
  mqttStatusTopic = "hasp/" + String(haspNode) + "/status";
  mqttSensorTopic = "hasp/" + String(haspNode) + "/sensor";
  mqttLightCommandTopic = "hasp/" + String(haspNode) + "/light/switch";
  mqttLightStateTopic = "hasp/" + String(haspNode) + "/light/state";
  mqttLightBrightCommandTopic = "hasp/" + String(haspNode) + "/brightness/set";
  mqttLightBrightStateTopic = "hasp/" + String(haspNode) + "/brightness/state";
  mqttMotionStateTopic = "hasp/" + String(haspNode) + "/motion/state";

  const String mqttCommandSubscription = mqttCommandTopic + "/#";
  const String mqttGroupCommandSubscription = mqttGroupCommandTopic + "/#";
  const String mqttLightSubscription = "hasp/" + String(haspNode) + "/light/#";
  const String mqttLightBrightSubscription = "hasp/" + String(haspNode) + "/brightness/#";

  // Loop until we're reconnected to MQTT
  while (!mqttClient.connected())
  {
    // Create a reconnect counter
    static uint8_t mqttReconnectCount = 0;

    // Generate an MQTT client ID as haspNode + our MAC address
    mqttClientId = String(haspNode) + "-" + String(espMac[0], HEX) + String(espMac[1], HEX) + String(espMac[2], HEX) + String(espMac[3], HEX) + String(espMac[4], HEX) + String(espMac[5], HEX);
    nextionSendCmd("page 0");
    nextionSetAttr("p[0].b[1].font", "6");
    nextionSetAttr("p[0].b[1].txt", "\"WiFi Connected!\\r " + String(WiFi.SSID()) + "\\rIP: " + WiFi.localIP().toString() + "\\r\\rMQTT Connecting:\\r " + String(mqttServer) + "\"");
    debugPrintln(String(F("MQTT: Attempting connection to broker ")) + String(mqttServer) + " as clientID " + mqttClientId);

    // Set keepAlive, cleanSession, timeout
    mqttClient.setOptions(30, true, 5000);

    // declare LWT
    mqttClient.setWill(mqttStatusTopic.c_str(), "OFF");

    if (mqttClient.connect(mqttClientId.c_str(), mqttUser, mqttPassword))
    { // Attempt to connect to broker, setting last will and testament
      // Subscribe to our incoming topics
      if (mqttClient.subscribe(mqttCommandSubscription))
      {
        debugPrintln(String(F("MQTT: subscribed to ")) + mqttCommandSubscription);
      }
      if (mqttClient.subscribe(mqttGroupCommandSubscription))
      {
        debugPrintln(String(F("MQTT: subscribed to ")) + mqttGroupCommandSubscription);
      }
      if (mqttClient.subscribe(mqttLightSubscription))
      {
        debugPrintln(String(F("MQTT: subscribed to ")) + mqttLightSubscription);
      }
      if (mqttClient.subscribe(mqttLightBrightSubscription))
      {
        debugPrintln(String(F("MQTT: subscribed to ")) + mqttLightSubscription);
      }
      if (mqttClient.subscribe(mqttStatusTopic))
      {
        debugPrintln(String(F("MQTT: subscribed to ")) + mqttStatusTopic);
      }

      if (mqttFirstConnect)
      { // Force any subscribed clients to toggle OFF/ON when we first connect to
        // make sure we get a full panel refresh at power on.  Sending OFF,
        // "ON" will be sent by the mqttStatusTopic subscription action.
        debugPrintln(String(F("MQTT: binary_sensor state: [")) + mqttStatusTopic + "] : [OFF]");
        mqttClient.publish(mqttStatusTopic, "OFF", true, 1);
        mqttFirstConnect = false;
      }
      else
      {
        debugPrintln(String(F("MQTT: binary_sensor state: [")) + mqttStatusTopic + "] : [ON]");
        mqttClient.publish(mqttStatusTopic, "ON", true, 1);
      }

      mqttReconnectCount = 0;

      // Update panel with MQTT status
      nextionSetAttr("p[0].b[1].txt", "\"WiFi Connected!\\r " + String(WiFi.SSID()) + "\\rIP: " + WiFi.localIP().toString() + "\\r\\rMQTT Connected:\\r " + String(mqttServer) + "\"");
      debugPrintln(F("MQTT: connected"));
      if (nextionActivePage)
      {
        nextionSendCmd("page " + String(nextionActivePage));
      }
    }
    else
    { // Retry until we give up and restart after connectTimeout seconds
      mqttReconnectCount++;
      if (mqttReconnectCount > ((connectTimeout / 10) - 1))
      {
        debugPrintln(String(F("MQTT connection attempt ")) + String(mqttReconnectCount) + String(F(" failed with rc ")) + String(mqttClient.returnCode()) + String(F(".  Restarting device.")));
        espReset();
      }
      debugPrintln(String(F("MQTT connection attempt ")) + String(mqttReconnectCount) + String(F(" failed with rc ")) + String(mqttClient.returnCode()) + String(F(".  Trying again in 30 seconds.")));
      nextionSetAttr("p[0].b[1].txt", "\"WiFi Connected:\\r " + String(WiFi.SSID()) + "\\rIP: " + WiFi.localIP().toString() + "\\r\\rMQTT Connect to:\\r " + String(mqttServer) + "\\rFAILED rc=" + String(mqttClient.returnCode()) + "\\r\\rRetry in 30 sec\"");
      unsigned long mqttReconnectTimer = millis(); // record current time for our timeout
      while ((millis() - mqttReconnectTimer) < 30000)
      { // Handle HTTP and OTA while we're waiting 30sec for MQTT to reconnect
        if (nextionHandleInput())
        { // Process user input from HMI
          nextionProcessInput();
        }
        webServer.handleClient();
        ArduinoOTA.handle();
        delay(10);
      }
    }
  }
}
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

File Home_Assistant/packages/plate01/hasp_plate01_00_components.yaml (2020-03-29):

##############################################################################
# Components used for the operation of various elements of each HASP device

# Enable this iframe to integrate the HASP web admin panel in Hass.
# This will not work if you have SSL enabled, see details here:
# https://www.home-assistant.io/components/panel_iframe/
panel_iframe:
  plate01:
    title: "plate01"
    url: "http://plate01"
    icon: "mdi:cellphone-text"

light:
  # Create a light device to control the backlight on the HASP device
  - platform: mqtt
    name: plate01 Backlight
    command_topic: "hasp/plate01/light/switch"
    state_topic: "hasp/plate01/light/state"
    brightness_state_topic: "hasp/plate01/brightness/state"
    brightness_command_topic: "hasp/plate01/brightness/set"
    availability_topic: "hasp/plate01/status"
    payload_available: "ON"
    payload_not_available: "OFF"
  # These MQTT lights allow the user to select from a color wheel. Bitwise
  # math is done on the RGB-888 value selected by the user to convert to
  # RGB-565 and publish that value to MQTT to be picked up by the automations
  # below.
  - platform: mqtt
    name: HASP plate01 Selected Foreground Color
    command_topic: "hasp/plate01/homeassistant/selectedforegroundcolor"
    state_topic: "hasp/plate01/homeassistant/selectedforegroundcolor"
    payload_off: "ON"
    rgb_command_topic: "hasp/plate01/homeassistant/selectedforegroundcolor/rgb"
    rgb_command_template: "{{ (red|bitwise_and(248)*256) + (green|bitwise_and(252)*8) + (blue|bitwise_and(248)/8)|int }}"
  - platform: mqtt
    name: HASP plate01 Selected Background Color
    command_topic: "hasp/plate01/homeassistant/selectedbackgroundcolor"
    state_topic: "hasp/plate01/homeassistant/selectedbackgroundcolor"
    payload_off: "ON"
    rgb_command_topic: "hasp/plate01/homeassistant/selectedbackgroundcolor/rgb"
    rgb_command_template: "{{ (red|bitwise_and(248)*256) + (green|bitwise_and(252)*8) + (blue|bitwise_and(248)/8)|int }}"
  - platform: mqtt
    name: HASP plate01 Unselected Foreground Color
    command_topic: "hasp/plate01/homeassistant/unselectedforegroundcolor"
    state_topic: "hasp/plate01/homeassistant/unselectedforegroundcolor"
    payload_off: "ON"
    rgb_command_topic: "hasp/plate01/homeassistant/unselectedforegroundcolor/rgb"
    rgb_command_template: "{{ (red|bitwise_and(248)*256) + (green|bitwise_and(252)*8) + (blue|bitwise_and(248)/8)|int }}"
  - platform: mqtt
    name: HASP plate01 Unselected Background Color
    command_topic: "hasp/plate01/homeassistant/unselectedbackgroundcolor"
    state_topic: "hasp/plate01/homeassistant/unselectedbackgroundcolor"
    payload_off: "ON"
    rgb_command_topic: "hasp/plate01/homeassistant/unselectedbackgroundcolor/rgb"
    rgb_command_template: "{{ (red|bitwise_and(248)*256) + (green|bitwise_and(252)*8) + (blue|bitwise_and(248)/8)|int }}"

binary_sensor:
  - platform: mqtt
    name: plate01 Connected
    device_class: connectivity
    state_topic: "hasp/plate01/status"
    payload_on: "ON"
    payload_off: "OFF"
    availability_topic: "hasp/plate01/status"
    payload_available: "ON"
    payload_not_available: "OFF"

sensor:
  - platform: mqtt
    name: plate01 Status
    state_topic: "hasp/plate01/status"
    availability_topic: "hasp/plate01/status"
    payload_available: "ON"
    payload_not_available: "OFF"
    json_attributes_topic: "hasp/plate01/sensor"

input_text:
  hasp_plate01_pagebutton1label:
    name: plate01 Page 1 Label
    icon: mdi:book-open-page-variant
  hasp_plate01_pagebutton2label:
    name: plate01 Page 2 Label
    icon: mdi:book-open-page-variant
  hasp_plate01_pagebutton3label:
    name: plate01 Page 3 Label
    icon: mdi:book-open-page-variant
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

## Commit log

2017-09-11 Update to new namespace
    New namespace in use to allow full 2-way communication, changes to serial ports to allow full hardware UART control of the panel (while still allowing for USB programming of the device), and added re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
2017-09-13 Updated 3D printer model and instructions
    [HASwitchPlate_front.stl, HASwitchPlate_rear.stl]
2017-09-13 Documentation updates covering new sliders and Arduino OTA
2017-09-14 HMI re-ordering of buttons on pages 6 and 7
    Preparing for implementation of alarm keypad capabilities
2017-09-15 Assembly instructions and minor changes to the model
    [HASwitchPlate_front.stl, HASwitchPlate_rear.stl]
2017-09-15 Updated BOM to include links to specific fasteners
2017-09-21 Add support for optional motion sensor
2017-09-21 Revert 3D printer initialization change
2017-10-01 Fix link to 20mm M2 screws
2017-10-14 Add board schematic
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2018-04-10 Add PCB design
    [HASwitchPlate.kicad_pcb, HASwitchPlate.sch]
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2018-04-10 Removing PCBs
    [HASwitchPlate.kicad_pcb, HASwitchPlate.sch]
2018-04-17 Adding new PCB and matching enclosure
    [HASwitchPlate.kicad_pcb, HASwitchPlate.sch, HASwitchPlate_front.stl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]
2018-04-18 Update enclosure models with debug/development versions
    [HASwitchPlate_front.stl, HASwitchPlate_front_debug.stl, HASwitchPlate_rear.stl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]
2018-04-18 Update documentation for device initialize, address Alarm automation bug
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2018-04-26 Arduino sketch v0.2.1 bugfix and feature relase
    [HASwitchPlate.ino]
2018-04-27 New HASP device deployment script
2018-04-28 Arduino sketch v0.2.3 release
2018-05-01 Update license and fix product links
    [HASwitchPlate.ino]
2018-05-05 New enclosure design
    [HASwitchPlate_front.stl, HASwitchPlate_front_debug.stl, HASwitchPlate_front_double_decora_right.stl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]
2018-05-07 Correct 3D print model image
2018-05-28 Add triple-wide decora plate
    [HASwitchPlate_front_triple_hasp_decora_decora.stl]
2018-05-28 Add exploded model STL
2018-05-28 Add support for running it in any dir.
    1: Check if configuration.yaml is present i current dir.
    2: if not, search for that dir
    3: if 1 dir found, cd to that.
    4: if more that 1 dir, exit.
2018-06-04 UK face plate for testing
    [HASwitchPlate_front_single_UK-UNTESTED.stl]
2018-07-02 Add 5x decora plate for @jpe-nyc
2018-08-22 Simplify HA automations for adjusting font/font size by implementing a couple of scripts
2018-09-18 Fix for hang when DHCP not available
    [HASwitchPlate.ino]
2018-12-03 Model updates for easier printing
    [HASwitchPlate_front_double_decora_right.stl, HASwitchPlate_front_double_toggle_right.stl, HASwitchPlate_front_single.stl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]
2018-12-18 Add desktop stand
    [HASwitchPlate_desktop_base.stl, HASwitchPlate_desktop_front.stl, HASwitchPlate_desktop_rear.stl]
2018-12-20 Additional User Contributed 3D Printable Models
    HASwitchPlate_double_spacer.stl - 5mm spacer between front switchplate and wall.
    HASwitchPlate_front_double_blank.stl - Left HASP module and right is a blank for two gang boxes
    HASwitchPlate_front_nolcd.stl - Solid front plate to separate LCD from D1/Power
    HASwitchPlate_contrib - Source files for above
    [HASwitchPlate_contrib.skp, HASwitchPlate_double_spacer.stl, HASwitchPlate_front_nolcd.stl]
2019-01-01 Minor 3D model updates and cleanup
    [HASwitchPlate_front_double_decora_right.stl, HASwitchPlate_front_double_toggle_right.stl, HASwitchPlate_front_single.stl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]
2019-01-03 Update electronics assembly documentation
2019-01-04 PCB v0.06
    [HASwitchPlate-B.Cu.gbr, HASwitchPlate-B.Mask.gbr, HASwitchPlate-B.SilkS.gbr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]
2019-01-04 Fix file paths for PCB publication
2019-01-06 Add minimum clearance rear enclosure
    [HASwitchPlate_rear_lcdmod_minimum_clearance.stl]
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2019-01-21 2019/01/21(BK): Big updates to the code, including: -Works with multiple HASPs (two sample sets of files for Foyer/Master included) -Added Status screen automation example (indoor/outdoor temp, day &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
2019-02-07 HASP v0.35
    [HASwitchPlate-B.Cu.gbr, HASwitchPlate-B.Mask.gbr, HASwitchPlate-B.SilkS.gbr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]
2019-02-10 -Rewrote all openHAB->HASP rules to use the JSON command topic for formatting like button text and font size. -Removed all individual items for txt/font/bco topics (cut # of items down by half) -Adde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
2019-02-10 Added /state/JSON MQTT subtopic, which publishes all button and dimmer events, with values (ON/OFF for buttons, ON/val for dimmers) in JSON format. Resolves #52 in upstream
    [HASwitchPlate.ino]
2019-02-10 Fixed case for state JSON topic ("JSON"->"json")
    [HASwitchPlate.ino]
2019-02-11 Removing "OFF" event for now (unable to distinguish between two quick OFF->ON->OFF state changes in openHAB, due to state not being locked in during rule execution (so quick button presses were being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
2019-02-16 Incorporated denominator's fix for plate refresh rule trigger (should work on all reconnects now)
2019-02-17 Rename desktop models
    [HASwitchPlate_desktop_rear.stl, HASwitchPlate_rear_desktop.stl]
2019-02-17 Fix desktop model names
    [HASwitchPlate_desktop_front.stl, HASwitchPlate_front_desktop.stl]
2019-02-18 ESP for Arduino 2.5.0 compatibility updates
2019-02-19 Fix Nextion LCD download from HTTP server
    [HASwitchPlate.ino]
2019-02-22 Fix Nextion upload from browser
    [HASwitchPlate.ino]
2019-02-22 Add LCD upload timeouts to reset in case something goes wrong
    [HASwitchPlate.ino]
2019-02-23 Fix mDNS using LEA MDNSResponder
    [HASwitchPlate.ino]
2019-02-24 Fix for auto firmware upgrades
    [hasp_plate01_00_components.yaml]
2019-02-24 fixing case in upgrade automation
2019-03-02 Add note about ESP8266 for Arduino 2.5.0 requirement
2019-03-25 Update documentation for compiling in Arduino IDE
2019-06-11 Update code to support ArduinoJson 6.x
2019-06-12 Extend MQTT JSON memory allocation, fix AllPCB link
    [HASwitchPlate.ino]
2019-06-12 Fix MDI icons and JSON array nulls
    [hasp_plate01_00_components.yaml]
2019-06-21 Fix PCB link
2019-07-12 Update HASwitchPlate.ino
    This pull request to to add a beep tone on screen press. This will help people to know that the button press was successful.
    I have also added a MQTT command to allow invalid code tried it will beep a pattern. (once I get Yet another alarm system to update his code to allow this.)
    Thanks
    Ben
2019-08-09 Invalid file.
    [HASwitchPlate_front_India_EU_86x86_blank.stl]
2019-08-09 Faceplate for India created by @ceaswaran
    Downloaded from https://www.thingiverse.com/thing:3712046
    [HASP_frontcover_India_V2.STL]
2020-02-12 Fix "status" sensor device
    [hasp_plate01_00_components.yaml]
2020-02-13 Fixes for beep code, disable WiFi sleep, update for WiFiManager constants
    [HASwitchPlate.ino]
2020-02-13 Set retain=true when publishing status and sensor messages
2020-02-29 HASP v0.40 Beta Documentation and 3D model updates
    [HASwitchPlate_assembly_jig.stl, HASwitchPlate_front_2x_decora_hasp.stl, HASwitchPlate_front_2x_hasp_decora.stl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]
2020-03-23 Replace FontAwesome icons w/ Material Design
2020-03-31 Remove duplicate models
    [HASwitchPlate_front_double_decora_right.stl, HASwitchPlate_front_double_toggle_right.stl, HASwitchPlate_front_triple_hasp_decora_decora.stl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]
